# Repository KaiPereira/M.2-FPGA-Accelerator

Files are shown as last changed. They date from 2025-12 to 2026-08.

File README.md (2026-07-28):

# M.2 FPGA Hardware Accelerator Devboard

This is an M.2 2280 M-Key card I've designed that plugs into the SSD slot in your computer and provides an FPGA fabric you can interact with over PCIe. It also has a couple pins broken out and a couple connectors like micro HDMI and USB-C so you can create custom pipelines that go from peripherals, into the FPGA, directly into your computer through the high-speed PCIe. 




## Custom Features
- M.2 M-Key 2280 SSD Form Factor for PCIe programming and interfacing
- Artix 7 with 50K LUTs and 256MB RAM
- USB-to-JTAG for programming and interfacing with peripherals
- Micro HDMI and 10 pins broken out for extra functionality
- Functions as a standalone devboard or can interface with your computer
- 6 LEDs for debugging and programming
- TC2030 breakout under USB-C if you DNP USB-to-JTAG

## PCB Design

The M.2 FPGA Hardware Accelerator is an extremely high density 0.8mm, 6 layer board using the JLC06081H-2116 stackup and has a stackup of SIGNAL/GND/SIGNAL/PWR/GND/SIGNAL.

A V2 is likely going to use a custom or different stackup to reduce the trace width for the DDR3 traces so I can minimize the cross-talk further, which is an issue with the current board.









## Firmware

Firmware is unwritten because I haven't produced the boards, and it requires significant prototyping in Vivado but there is some basic skeleton software inside of the [/firmware](/firmware) folder.

## Production

I've based the board around JLCPCB production and I've included an LCSC/JLCPCB BOM inside of the [/PCB/production](/PCB/production/) folder.

It uses the JLC06081H-2116 stackup which you can find details about on the JLC site if you want to produce the board from a different fabricator.

You'll want some specific settings too like:
- Impedance controlled traces
- ENIG and select gold fingers to add hard gold onto the M.2 M-Key edge connector
- 0.8mm thick board
- X-Ray to confirm all the BGA placement

Produce this board at your own cost, it's an untested board and I haven't manufactured it myself yet, because I want to create a V2 with a different stackup, and it's an extremely constrained design so many problems can arise!  

## Credits

Thanks so much to the KiCad discord for the PCB reviews, and to everyone in Hack Club for the support and to Renran and Samliu for running [Fallout](https://fallout.hackclub.com/) which is the program that's sponsoring this project!

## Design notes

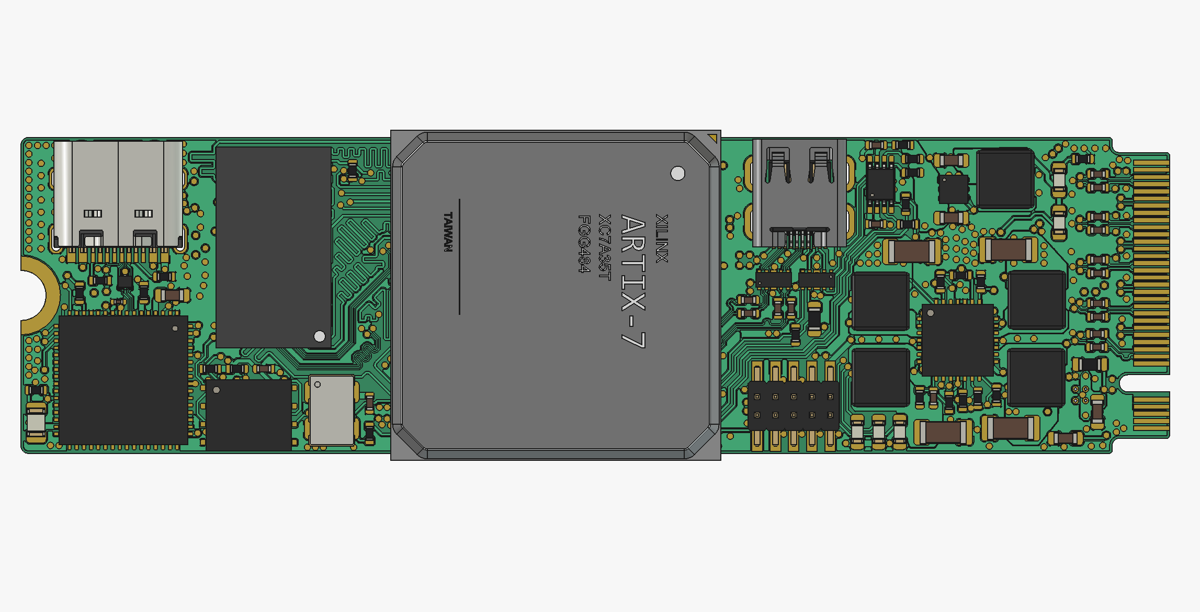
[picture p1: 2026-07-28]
PCB/renders/Top PCB Render.png

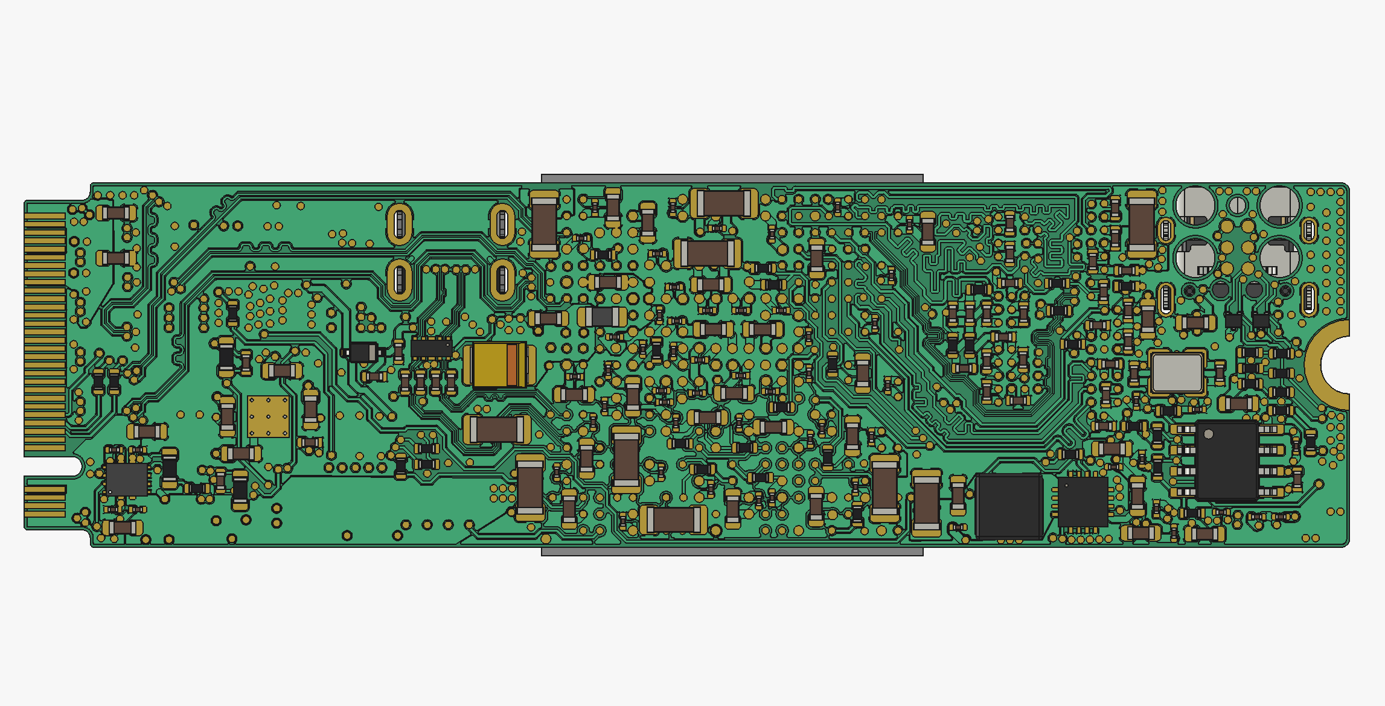
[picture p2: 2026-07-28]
PCB/renders/Bottom PCB Render.png

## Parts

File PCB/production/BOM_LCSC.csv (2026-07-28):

Designator | Footprint | Quantity | Value | LCSC Part #
C10, C11, C12, C3, C4, C5, C6, C7, C8, C9 | 402 | 10 | 220n | C16772
C100, C102, C104, C105, C106, C107, C108, C109, C112, C118, C124, C125, C127, C129, C135, C136, C137, C138, C143, C144, C145, C146, C148, C150, C151, C154, C155, C156, C157, C161, C162, C163, C164, C168, C169, C17, C170, C171, C18, C19, C20, C25, C27, C28, C29, C30, C31, C35, C36, C38, C39, C47, C54, C67, C69, C71, C91, C92, C95, C99 | 201 | 60 | 470n | C76591
C101, C103, C126, C130, C133, C134, C141, C142, C147, C15, C152, C153, C159, C160, C166, C167, C173, C2, C21, C22, C23, C32, C33, C37, C40, C41, C42, C43, C44, C56, C66, C68, C70, C75, C87, C89, C90, C94, C98 | 603 | 39 | 4u7 | C19666
C110, C111, C113, C114, C115, C116, C117, C119, C120, C122, C123, C139, C14, C16, C57, C58, C59, C60, C61, C62, C63, C64, C65, C73, C74, C76, C77, C78, C79, C80, C81, C82, C83, C84, C86, C93 | 402 | 36 | 100n | C1525
C121, C46 | 402 | 2 | 1u | C52923
C128, C72 | 603 | 2 | 47n | C1622
C13, C172 | 402 | 2 | 10n | C15195
C131, C132, C140, C149, C158, C165, C34, C45, C49, C51, C53, C85, C88 | 1206 | 13 | 47u | C96123
C24 | CP_EIA-3528-21_Kemet-B | 1 | 330u | C542287
C26 | 1206 | 1 | 100u | C15008
C48 | 402 | 1 | 68pF | C107009
C50, C96, C97 | 402 | 3 | 33p | C1562
C52 | 402 | 1 | 22pF | C1555
D1 | 603 | 1 | KT-0603R | C2296
D2 | 805 | 1 | KT-0805Y | C2296
D3 | D_SOD-323 | 1 | 1N5819WS | 1N5819WS
D4, D5, D6, D7 | 603 | 4 | KT-0603G | C2297
FB1 | 805 | 1 | 120@100MHz | C5120901
J1 | M.2 M-Key 2242 | 1 | Bus_M.2_Edge_M
J4 | USB_C_Receptacle_HRO_TYPE-C-31-M-12 | 1 | TYPE-C-31-M-12 | C165948
J5 | PinHeader_2x05_P1.27mm_Vertical_SMD | 1 | Conn_02x05_Odd_Even | C41376037
J7 | Kai's_HDMI_Micro-D_Molex_46765-1xxx | 1 | HDMI_D_1.4 | C711358
L1, L2, L3, L4, L5, L6 | L_Sunlord_SWPA4030S | 6 | 1u5 | C42100
R1, R31 | 402 | 2 | 100 | C25076
R10, R11, R12, R13, R34, R38, R39, R40, R41, R45, R46, R5, R50, R51, R53, R54, R7, R9 | 402 | 18 | 10k | C25744
R14, R15, R17, R18, R2, R24, R3, R42, R43, R56, R57, R76, R77, R78, R79, R80 | 402 | 16 | 1k | C11702
R16 | 402 | 1 | 240 | C25153
R19, R20, R21, R23, R27, R28, R30, R44, R59, R60, R61, R62, R63 | 402 | 13 | 4k7 | C25900
R25, R26, R29, R32, R36, R37, R75 | 402 | 7 | 22 | C25092
R33, R47 | 603 | 2 | 30k | C22984
R35, R6 | 603 | 2 | 4k99 | C23046
R4 | 402 | 1 | 2k | C4109
R48, R49 | 402 | 2 | 5k1 | C25905
R52 | 402 | 1 | 2k2 | C25879
R55 | 402 | 1 | 12k | C25752
R58, R65 | 402 | 2 | 100k | C25741
R8 | 603 | 1 | 8k2 | C25981
U1 | Xilinx_FGG484 | 1 | XC7A50T-FGG484 | C1521780
U10 | QFN-64-1EP_9x9mm_P0.5mm_EP4.35x4.35mm | 1 | FT2232HQ | C193662
U11 | FBGA-96_8x14mm_Layout9x16_P0.8mm | 1 | MT41J128M16JT-125:K | C426885
U12 | VSSOP-8_2.3x2mm_P0.5mm | 1 | PCA9306DC1 | C129510
U14, U15, U16 | Diodes_UDFN-10_1.0x2.5mm_P0.5mm | 3 | UCL0524P | C2835428
U17 | VQFN-16-1EP_3x3mm_P0.5mm_EP1.68x1.68mm_ThermalVias | 1 | TPS62132 | C81563
U2 | QFN-28-1EP_5x5mm_P0.5mm_EP3.25x3.25mm_ThermalVias | 1 | MAX20029ATIA/V+ | C1235515
U3, U4, U6 | Texas_DRT-3 | 3 | TPD2EUSB30 | C97502
U5 | Texas_VQFN-HR-12_2x2.5mm_P0.5mm_ThermalVias | 1 | TPS2121RUXR | C485916
U7 | W-PDFN-8-1EP_6x5mm_P1.27mm_EP3x3mm | 1 | MT25QL128ABA1EW7-0SIT | C2887898
U8 | WSON-6-1EP_2x2mm_P0.65mm_EP1x1.6mm | 1 | TPS61240DRVR | C59567
U9 | SOIC-8_3.9x4.9mm_P1.27mm | 1 | M93C56-WMN6TP | C283453
Y2 | Crystal_SMD_3225-4Pin_3.2x2.5mm | 1 | 12MHz | C9002
Y3 | Oscillator_SMD_SiT_PQFN-4Pin_5.0x3.2mm | 1 | 100MHz | C78882

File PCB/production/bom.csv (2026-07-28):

Designator | Footprint | Quantity | Value | LCSC Part #
C10, C11, C12, C3, C4, C5, C6, C7, C8, C9 | 0402 | 10 | 220n
C100, C102, C104, C105, C106, C107, C108, C109, C112, C118, C124, C125, C127, C129, C135, C136, C137, C138, C143, C144, C145, C146, C148, C150, C151, C154, C155, C156, C157, C161, C162, C163, C164, C168, C169, C17, C170, C171, C18, C19, C20, C25, C27, C28, C29, C30, C31, C35, C36, C38, C39, C47, C54, C67, C69, C71, C91, C92, C95, C99 | 0201 | 60 | 470n
C101, C103, C126, C130, C133, C134, C141, C142, C147, C15, C152, C153, C159, C160, C166, C167, C173, C2, C21, C22, C23, C32, C33, C37, C40, C41, C42, C43, C44, C56, C66, C68, C70, C75, C87, C89, C90, C94, C98 | 0603 | 39 | 4u7
C110, C111, C113, C114, C115, C116, C117, C119, C120, C122, C123, C139, C14, C16, C57, C58, C59, C60, C61, C62, C63, C64, C65, C73, C74, C76, C77, C78, C79, C80, C81, C82, C83, C84, C86, C93 | 0402 | 36 | 100n
C121, C46 | 0402 | 2 | 1u
C128, C72 | 0603 | 2 | 47n
C13, C172 | 0402 | 2 | 10n
C131, C132, C140, C149, C158, C165, C34, C45, C49, C51, C53, C85, C88 | 1206 | 13 | 47u
C24 | CP_EIA-3528-21_Kemet-B | 1 | 330u | C542287
C26 | 1206 | 1 | 100u | C15008
C48 | 0402 | 1 | 68pF
C50, C96, C97 | 0402 | 3 | 33p
C52 | 0402 | 1 | 22pF
D1 | 0603 | 1 | KT-0603R | C2296
D2 | 0805 | 1 | KT-0805Y | C2296
D3 | D_SOD-323 | 1 | 1N5819WS | 1N5819WS
D4, D5, D6, D7 | 0603 | 4 | KT-0603G | C2297
FB1 | 0805 | 1 | 120@100MHz | C5120901
J1 | M.2 M-Key 2242 | 1 | Bus_M.2_Edge_M
J4 | USB_C_Receptacle_HRO_TYPE-C-31-M-12 | 1 | TYPE-C-31-M-12 | C165948
J5 | PinHeader_2x05_P1.27mm_Vertical_SMD | 1 | Conn_02x05_Odd_Even
J7 | Kai's_HDMI_Micro-D_Molex_46765-1xxx | 1 | HDMI_D_1.4 | C711358
L1, L2, L3, L4, L5, L6 | L_Sunlord_SWPA4030S | 6 | 1u5 | C42100
R1, R31 | 0402 | 2 | 100
R10, R11, R12, R13, R34, R38, R39, R40, R41, R45, R46, R5, R50, R51, R53, R54, R7, R9 | 0402 | 18 | 10k
R14, R15, R17, R18, R2, R24, R3, R42, R43, R56, R57, R76, R77, R78, R79, R80 | 0402 | 16 | 1k
R16 | 0402 | 1 | 240
R19, R20, R21, R23, R27, R28, R30, R44, R59, R60, R61, R62, R63 | 0402 | 13 | 4k7
R25, R26, R29, R32, R36, R37, R75 | 0402 | 7 | 22
R33, R47 | 0603 | 2 | 30k
R35, R6 | 0603 | 2 | 4k99
R4 | 0402 | 1 | 2k
R48, R49 | 0402 | 2 | 5k1
R52 | 0402 | 1 | 2k2
R55 | 0402 | 1 | 12k
R58, R65 | 0402 | 2 | 100k
R8 | 0603 | 1 | 8k2
U1 | Xilinx_FGG484 | 1 | XC7A50T-FGG484
U10 | QFN-64-1EP_9x9mm_P0.5mm_EP4.35x4.35mm | 1 | FT2232HQ
U11 | FBGA-96_8x14mm_Layout9x16_P0.8mm | 1 | MT41J128M16JT-125:K | C426885
U12 | VSSOP-8_2.3x2mm_P0.5mm | 1 | PCA9306DC1 | C129510
U14, U15, U16 | Diodes_UDFN-10_1.0x2.5mm_P0.5mm | 3 | UCL0524P | C2835428
U17 | VQFN-16-1EP_3x3mm_P0.5mm_EP1.68x1.68mm_ThermalVias | 1 | TPS62132
U2 | QFN-28-1EP_5x5mm_P0.5mm_EP3.25x3.25mm_ThermalVias | 1 | MAX20029ATIA/V+ | C1235515
U3, U4, U6 | Texas_DRT-3 | 3 | TPD2EUSB30
U5 | Texas_VQFN-HR-12_2x2.5mm_P0.5mm_ThermalVias | 1 | TPS2121RUXR | C485916
U7 | W-PDFN-8-1EP_6x5mm_P1.27mm_EP3x3mm | 1 | MT25QL128ABA1EW7-0SIT | C2887898
U8 | WSON-6-1EP_2x2mm_P0.65mm_EP1x1.6mm | 1 | TPS61240DRVR
U9 | SOIC-8_3.9x4.9mm_P1.27mm | 1 | M93C56-WMN6TP
Y2 | Crystal_SMD_3225-4Pin_3.2x2.5mm | 1 | 12MHz | C9002
Y3 | Oscillator_SMD_SiT_PQFN-4Pin_5.0x3.2mm | 1 | 100MHz | C78882

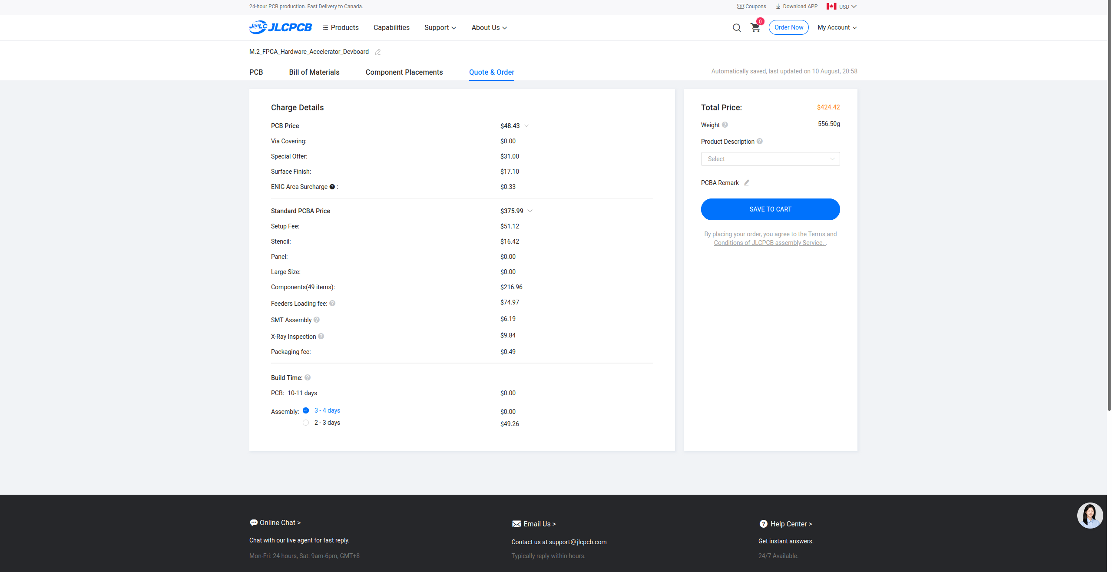
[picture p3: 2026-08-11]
PCB/production/JLCPCB BOM Cost.png

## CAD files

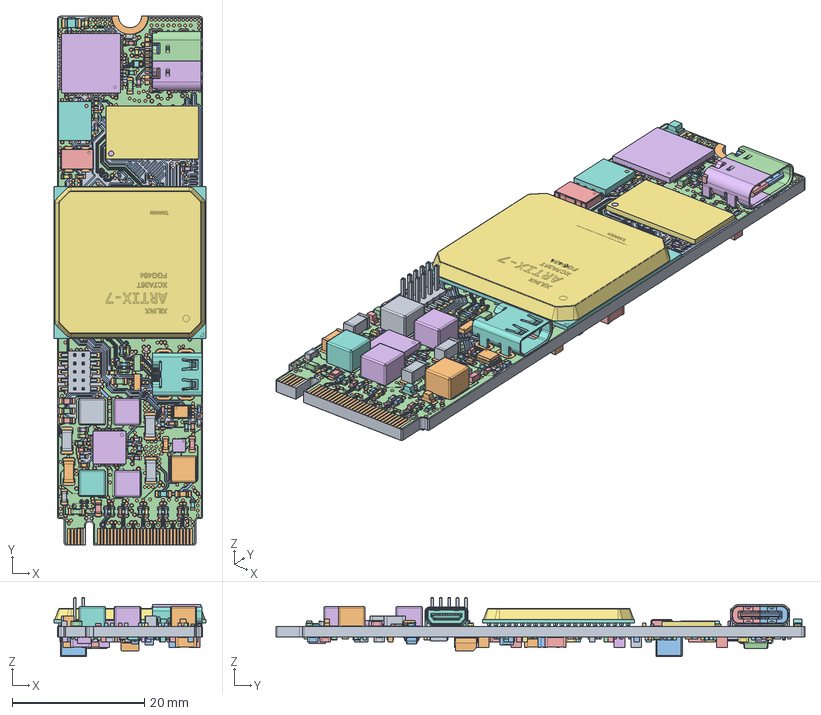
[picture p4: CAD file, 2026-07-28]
PCB/PCB.FCStd
23.0 x 80.0 x 9.00 mm
Pcb_6ed7
topPads_6ed7_cut
topTracks_6ed7
topZones_6ed7
botPads_6ed7_cut
botTracks_6ed7
botZones_6ed7
U3_DRT_3_db824c9c6ecc
C72_C_0603_1608Metric_5e36e871a214
U12_VSSOP-8_2.3x2mm_P0.5mm_27119c29455c
C105_C_0201_0603Metric_810f01f4b739
C70_C_0603_1608Metric_285581eceda0
C9_C_0402_1005Metric_7bbb193fbc59
R28_R_0402_1005Metric_2ceafa7c5941
A0A1D60D-8EA2-4440-A76C-889AD579F6B7
A0A1D60D-8EA2-4440-A76C-889AD579F6B001
J5_PinHeader_2x05_P127mm_Vertical_SMD_d3717308b6a3
R62_R_0402_1005Metric_ff690207b4ec
C5_C_0402_1005Metric_4392c6b985be
U15_Diodes_UDFN-10_1.0x2.5mm_P0.5mm_482b8b0d3ad6
R33_R_0603_1608Metric_e8235a0dd6c8
U8_WSON_6_1EP_2x2mm_P065mm_EP1x16mm_4512e4520f19
C119_C_0402_1005Metric_a6c59a1147ee
b2c8199a-8124-11ed-a8f2-acde48001122_part
b2c81abc-8124-11ed-a8f2-acde48001122_part
b2c81abc-8124-11ed-a8f2-acde48001122_part001
b2c81abc-8124-11ed-a8f2-acde48001122_part002
b2c81abc-8124-11ed-a8f2-acde48001122_part003
b2c81abc-8124-11ed-a8f2-acde48001122_part004
b2c81abc-8124-11ed-a8f2-acde48001122_part005
b2c81abc-8124-11ed-a8f2-acde48001122_part006
b2c81abc-8124-11ed-a8f2-acde48001122_part007
b2c81abc-8124-11ed-a8f2-acde48001122_part008
b2c81b5c-8124-11ed-a8f2-acde48001122_part
R11_R_0402_1005Metric_b85a15342edb
D6_LED_0603_1608Metric_46c866f26d77
Y3_Oscillator_SMD_EuroQuartz_XO53-4Pin_5.0x3.2mm_67b5db197837
R48_R_0402_1005Metric_d4512e19648c
C48_C_0402_1005Metric_6bb54f56762e
D2_LED_0805_2012Metric_66023c916e94
C7_C_0402_1005Metric_07508b53c483
a684622a-8551-11ed-a139-00155d22e2d7_part
a68462b6-8551-11ed-a139-00155d22e2d7_part
a68462b6-8551-11ed-a139-00155d22e2d7_part001
R60_R_0402_1005Metric_9ab4710071f4
C111_C_0402_1005Metric_9e80eb63b43e
R49_R_0402_1005Metric_c1691efec041
R55_R_0402_1005Metric_50459dd57344
a684622a-8551-11ed-a139-00155d22e2d7_part001
a68462b6-8551-11ed-a139-00155d22e2d7_part003
a68462b6-8551-11ed-a139-00155d22e2d7_part004
C10_C_0402_1005Metric_e4306dec6820
D7_LED_0603_1608Metric_ffa68f399684
U2_QFN-28-1EP_5x5mm_Pitch0.5mm_19db0ce88066
R75_R_0402_1005Metric_a483df6bea4b
R77_R_0402_1005Metric_3be320d7ddfe
C4_C_0402_1005Metric_65057fa5bc6c
C139_C_0402_1005Metric_fde9821d451f
C122_C_0402_1005Metric_816c50b5e529
R47_R_0603_1608Metric_03dc8c990f57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

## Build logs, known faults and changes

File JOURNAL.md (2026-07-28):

---
title: FPGA Accelerator
author: Kai Pereira
description: " A low-cost, PCIe FPGA accelerator M.2 M-Key form factor devboard for hobbyists"
created_at: 2025-12-16
---
## The idea - 2 Hours

I've worked on a ton of different boards ranging from keyboards, to motherboards to hackathon badges to even carriers, but now I want to work on something next level.

I've always been fascinated by hybrid computing in a consumer setting and building complicated stuff, so with that in mind, I've come up with my next idea.

FPGA's are becoming much more mainstream for parallelization and computing so I want to explore how hobbyists can leverage this technology in an affordable and cool way.

The thing about FPGA's, is while they're really useful, it's hard to make practical applications of them as a hobbyist, because it's not like you're going to innovate the next big chip or something, but that's where I want to leverage the fact that FPGA's aren't just useful for mainstream chips, but also more niche applications like very specific hardware acceleration, that consumers can actually make cool use of and practice.

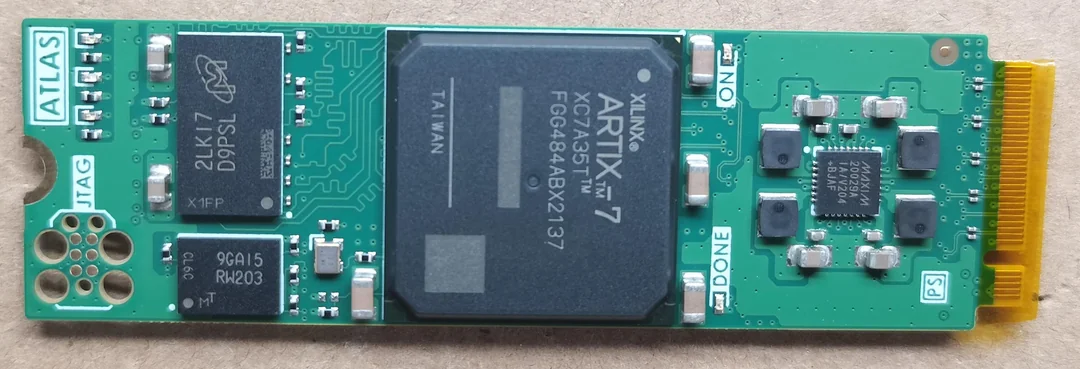
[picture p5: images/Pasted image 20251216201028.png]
Pasted image 20251216201028.png


So the idea is simple, I want a low-cost way, hobbyists can make practical applications of FPGA's in a bunch of different settings.

To do this, I want to provide an FPGA devboard of sorts, that can interface with your computer hardware so you can practice on real-world applications in more niche settings. But I want to go a step further and also make it function as a standard devboard in case you don't have access to an M.2 slot, so I need to break out like standard USB-C and whatnot.

This also means that I want to add other functions like HDMI, maybe even GbE and just generally make it insanely useful to hobbyists!

There's a couple key goals I have for this project:
- Learn to route BGA and high-density impedance controlled traces
- Learn GbE, HDMI and PCIe routing
- Understand at a high level, the physics behind the board
- Focus on routing best practices, specifically minimizing loops

This project has already been similarly done by Phil's lab, but his project was more-so focused on acceleration instead of as a hobbyist development board, but this video will still be really useful to reference during development of this project! https://www.youtube.com/watch?v=8bw80LiCl7g

## Connectors!! - 4 Hours

Now the first thing I have to decided, is what type of edge connector I want to use. Now NVMe SSD's are standard M.2 size, but have different type of "keys" which is essentially where the different holes are on it:

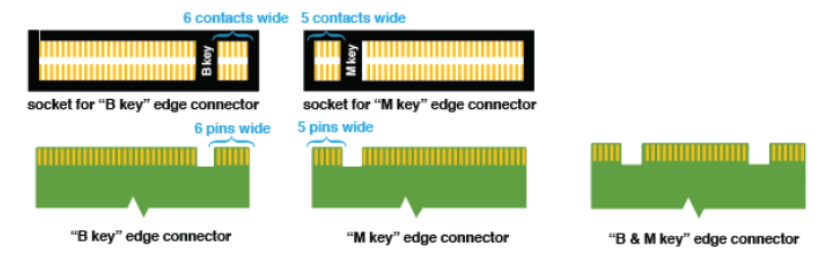
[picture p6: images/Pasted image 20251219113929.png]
Pasted image 20251219113929.png


NVMe SSD's mostly just use M-Key edge connectors, so that's what I'm going to use.

But now, there's also more than just one type of size, there's actually 5 of them (probably more than that, but the 5 most common)

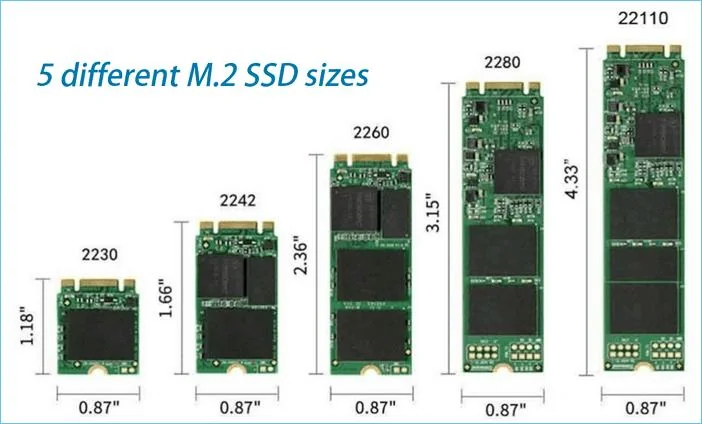
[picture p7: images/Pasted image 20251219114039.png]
Pasted image 20251219114039.png


Now 2280 is by far the most common, but I don't actually think I'll use all that space, so for now, I think I'm going to go with 2242 which is decently common still but for other applications most of the time.

The numbering system is really simple. 2242 means 22mm x 42mm, 2280 means 22mm x 80mm.

So now i have to create my footprint and symbol for these edge connectors. I can also easily change my form factor after making the footprint because it's legitimately just the height that changes.

Lucky for me, someone's already made some M.2 footprints and symbols, so I'm going to use these ones from https://github.com/timonsku/M.2-Card-Footprints

Now this person didn't actually make an M-Key, so I had to modify one of the existing ones to make it. M.2 footprints are really interesting, because they literally just remove the pins where the key is and don't really shift anything, so it's easy to make footprints for:

Pasted image 20251219114720.png

Now I was thinking I might be able to use a B+M-Key to be more compatible, but the ECP5 only has a soft SATA PHY or SERDES which would be really complicated and annoying to implement, so I'm just keeping it symbol.

And then this library I downloaded included the symbols already, so I'm all set to get working:

Pasted image 20251219115014.png

## Edge connector and choosing an FPGA - 4 Hours

Now I want to get working on actually wiring the edge connector! The first thing I'm going to do is wire the power and ground.

I decided to use one 100nF cap per pin, and then one 1uF + 10uF per group of them like so:

Pasted image 20251219121205.png

I'm referencing the M.2 PCI express electromechanical datasheet for pins https://picture.iczhiku.com/resource/eetop/sHksKPigIJigRbbx.pdf

Pasted image 20251219121236.png

I've decided to 0402 for 100nF, and 1uF, and then 0603 for 10uF to save as much space as possible, but still be pretty efficient at decoupling.

Next, I need to choose what FPGA I actually want to use. The first thing that comes to mind is the ECP5. It's a small and cheap FPGA with SERDES so it works with PCIe which is really cool. 

It has a faster (5G) and slower version, so I can have gen 2 PCIe speeds which is pretty cool. The minimum 5G FPGA costs around $18.50 https://jlcpcb.com/partdetail/Lattice-LFE5UM5G_25F8MG285C/C1551932 so it's a pretty good option.

But there's also the Xilinx Artix FPGA which is significantly more powerful, the XC7A100T has nearly 4x the LUTS and is way more powerful, but is also significantly larger, having 4x lanes. The price is actually pretty good though, coming in at just $29.

So the Artix FPGA is probably a better option, because the price and accessibility of the ECP5 for the specs I need is just kind of out of scope. It'll also give me really good practice with a really popular AMD FPGA which could be really helpful for the future! 

Now the Xilinx Aritix has MANY different packages, ranging from 12K to 215K LUTs and 720 to 13000 Kb of memory. I also need a minimum of 4 GTP transceivers which are essentially just high speed pins so 15K LUTs minimum.

But let's stay within the price range, so I want under $20 for the FPGA and preferably over 25K LUTs which gives me many good options!

This means I should also increase the size of my board from 2242 to 2280 which I actually wanted an excuse to do, and I can also add all those other features. 

So in the end, I think I'm going to go with the XC7A50T-1FGG484C, the Xilinx Artix 7, with 50K LUTs, coming in at just $17 at minimum quantities, and having 484 pins!!! https://jlcpcb.com/partdetail/AMDXILINX-XC7A50T1FGG484C/C1521780

I think this is honestly the perfect option, and I know Phil's Lab uses the same one, but it's the best for the job!

## Working on the FPGA - 3 Hours

Now that I know I want to use the Artix 7 FPGA, I need to add it into KiCad. I'm really lucky because KiCad actually has this symbol built in, but the footprint doesn't seem to come up, so I'll need to look into that:

Pasted image 20251220104108.png

Pasted image 20251220104157.png

And lucky me, a footprint actually does exist!!

Pasted image 20251220104406.png

Next, I want to figure out what voltage lines I need for my project. Based off of the datasheet, I'll need:
- VCCINT 1V, FPGA fabric logic, lowest voltage for CMOS is 1V
- VCCBRAM 1V. internal block RAM, needs to be really stable
- VMGTAVCC 1V, analog GTP transceivers voltage, might need to be seperate from VCCINT
- VCCAUX 1V8, powers configuration and clocking stuff, 1V8 for noise margin
- VCCO 3V3, powers I/O banks 3V3 because connector is 3V3 and I use 3V3 logic
- VMGTAVTT 1V2, very interesting termination voltage, it basically controls the impedance of the GTP transceiver/PCIe lines, and makes sure they don't see reflections and too much nosie!
- DDR3 Voltage, 1V5 for DDR3 I/O bank pins which are 1V5 for standard DDR3 (1V35 for DDR3L)

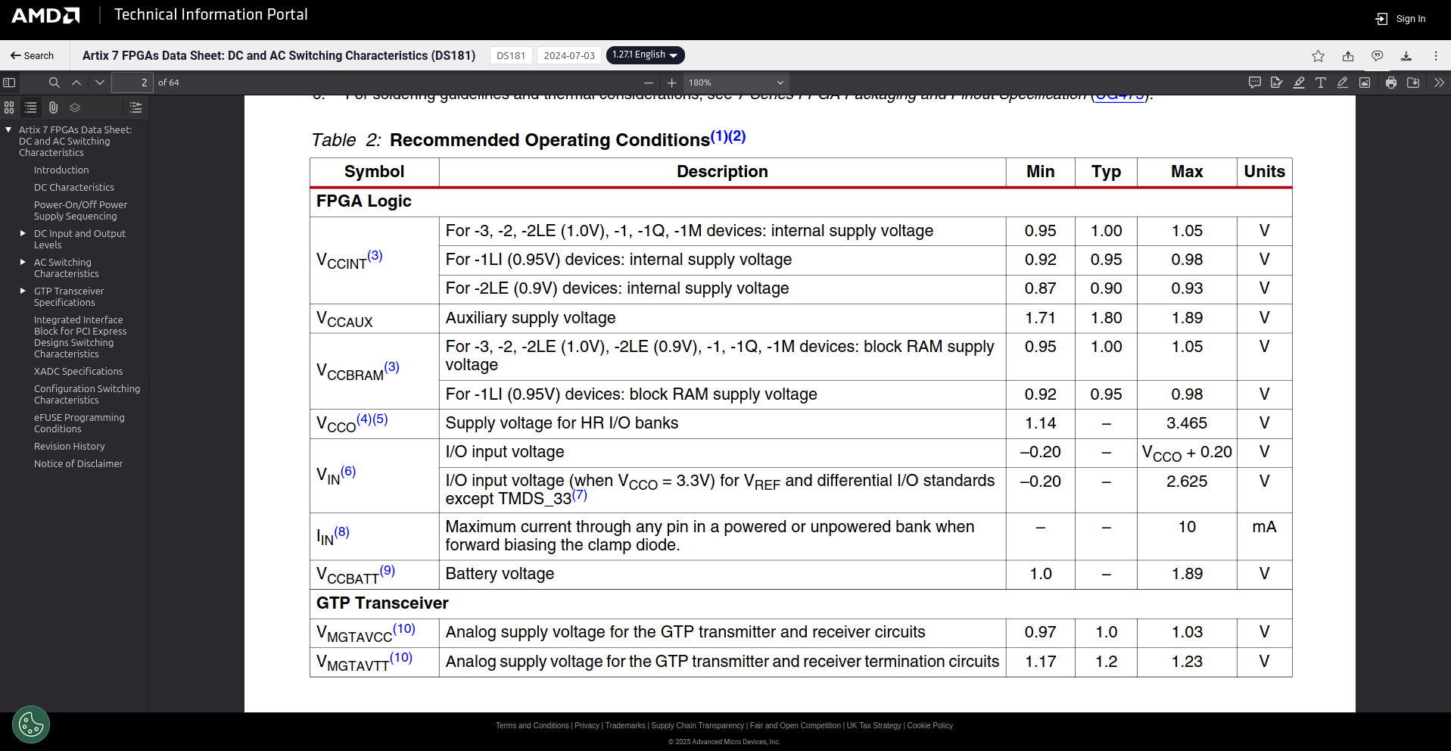
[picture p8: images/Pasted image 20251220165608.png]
Pasted image 20251220165608.png


So now that I have all the theory worked out, I can get working on making the actual thing! 

This was just a bunch of datasheet reading today and a couple video's, but I have a really good idea on how to do this now!

## Decoupling time! - 5 Hours

Decoupling is fairly simple with the Artix 7, the datasheets tell you almost exactly how to do it:

Pasted image 20251221082541.png
Pasted image 20251221082558.png

So just like that, I organized everything and added in the decoupling: 

Pasted image 20251221082621.png

And I'll also need ferrite beads on these lines, but before that, I want to figure out what PMIC I'm going to use. I have 4 rails, and I need 3V3, so a quad switching buck converter would be a really good option! 

I want to do this, because the characteristics of the bucks will help me determine the values of the ferrite beads!

I spent nearly 6 hours straight, fueled from Yerba and classical music trying to find the best buck, and I've found 2 possible options.

The [MAX20029](https://www.analog.com/en/products/max20029.html) is the lower cost option, with up to 1.5A channels, and is fixed/adjustable, though I would only use the fixed part. It's high efficiency, but the efficiency kind of drops off at lower current, but it has a smaller package and is designed for automotive. You can use the same value inductor on all the rails and it has power sequencing. This is the same one that Phil's lab uses, and it's really good!

The [LTC3370](https://www.digikey.ca/en/products/detail/analog-devices-inc/LTC3370IUH-TRPBF/5155587) is a bit more overkill, with strong 2A channels, and really good efficiency characteristics. It's a bit larger and a bit more expensive, and it's a bit overkill, but you can have the same value inductors, and is also a fantastic option! 

I've legitimately looked at 100's of buck converters, and these are probably the 2 best options! 

In the end, I think I'm going to go with the MAX20029 because it has smaller inductors, is cheaper and perfectly fits the specs. Even though it's what phil uses, it honestly just is the superior option and the only downfall is I can't use any of the fixed variants, so I have to use quite a few voltage dividers. 

I've done a lot of research today, so I think I'm going to hop off for now! 

## Power management! - 8 Hours

Now that I've found what PMIC I want to use, we need to add it into KiCad.

But after some second thought, I've decided that the LTC3370 is actually probably a better choice because of it's higher current demands which means better power tolerance, and I want support for all the extra peripherals I might add too. 

So let's add that in! 

The first thing I need to do is create the symbol for my buck converter. After referencing the datatsheet and tuning things up, I've come up with this pretty clean symbol that will probably change to my likings, but it's good as a template, and has all the necessary pins and footprint! 

Pasted image 20251225000450.png

Pasted image 20251225000521.png

Next, I'm going to wire all the important stuff for the buck converter. Per the datasheet, each input should have a 22uF cap, VCC should have 10uF, and each 2A channel output should have 47uF! 

I calculated the voltage dividers using VOUT = VFB(1 + R2/R1), and used 100K as my bottom resistor to minimize my BOM. This gives me a really nice and convenient voltage divider setup:

I also used 2.2uH inductors which are recommended by the datasheet for 2A, and they have a really low ESR to minimize power loss:

Pasted image 20251225000820.png

BUTTTT, this is kind of when I had a brain blast and decided to just outright switch to the MAX20029.

I realized that I would be saving over $7 with the MAX20029 and it has way simpler power sequencing and smaller package, so it's just significantly better.

So let's make the symbol for the MAX20029! I came up with this tall little symbol, I might make it larger but it kind of fits my needs:

Pasted image 20251227142741.png

And then it's really simple wiring, you just need pullups on PG to have a stable state, and also calculate the voltage dividers and frequency matching capacitors:

Pasted image 20251227142844.png

PG1 will go high when it's active, and the pullup just helps to ensure it gets there. There's no voltage divider on 1V0, because the VOUT is already 1V, and then the rest have voltage dividers to get there and frequency matching rounded down to the nearest E6 capacitor!

## More decoupling and filtering - 5 Hours

Now that I've finished with my power supply, I need to figure out how to properly filter it for my analog rails! 

This actually took me a really long time to figure out because I've never fully understood ferrite beads, but after a bit of research and talking with the KiCad guys, I've done a simple but effective implementation in my opinion:

Pasted image 20251229001159.png

I chose 600R@100MHz to filter out the high frequency noise moderately and it's low DCR so it has a minimal drop and is up to 2A. I made a little low pass filter LC filter by adding some shunts to ground, and added a bulk before the cap on MGTAVCC because it's higher current!

I decided to also set up an LTSpice simulation for these ferrite beads, just to make sure everything will be fine, and I can use it in the future for more accurate testing and adjusting once I've finished routing the board!

This took me a really long time to figure out, but I think it turned out really well! 

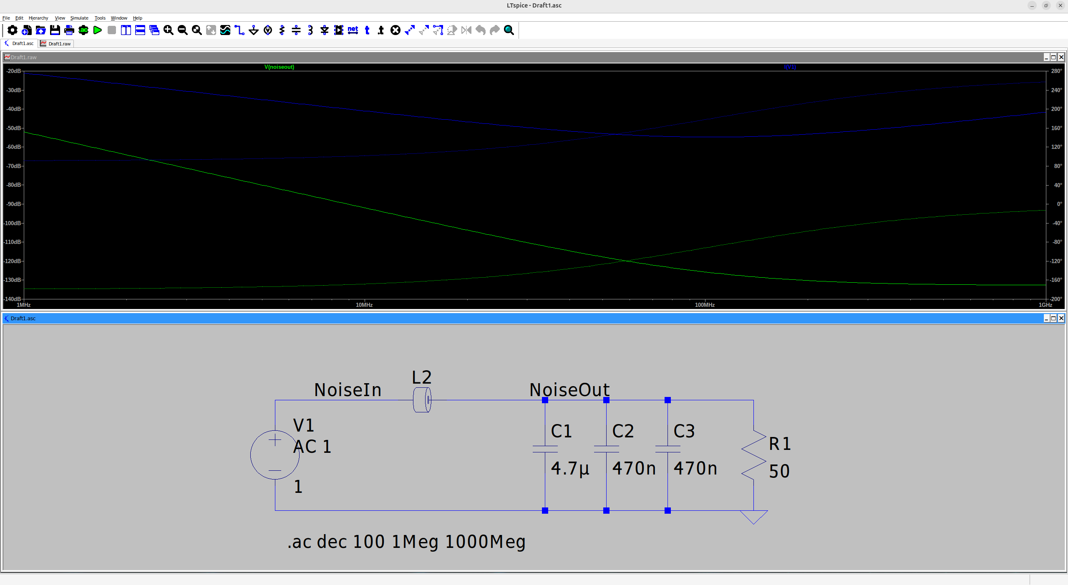
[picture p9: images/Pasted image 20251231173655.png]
Pasted image 20251231173655.png


This isn't too relevant right now, but will be really useful once I've finished routing! 

I also fixed up some of the decoupling on my m.2 edge connector because it wasn't using the standard values in my schematic.

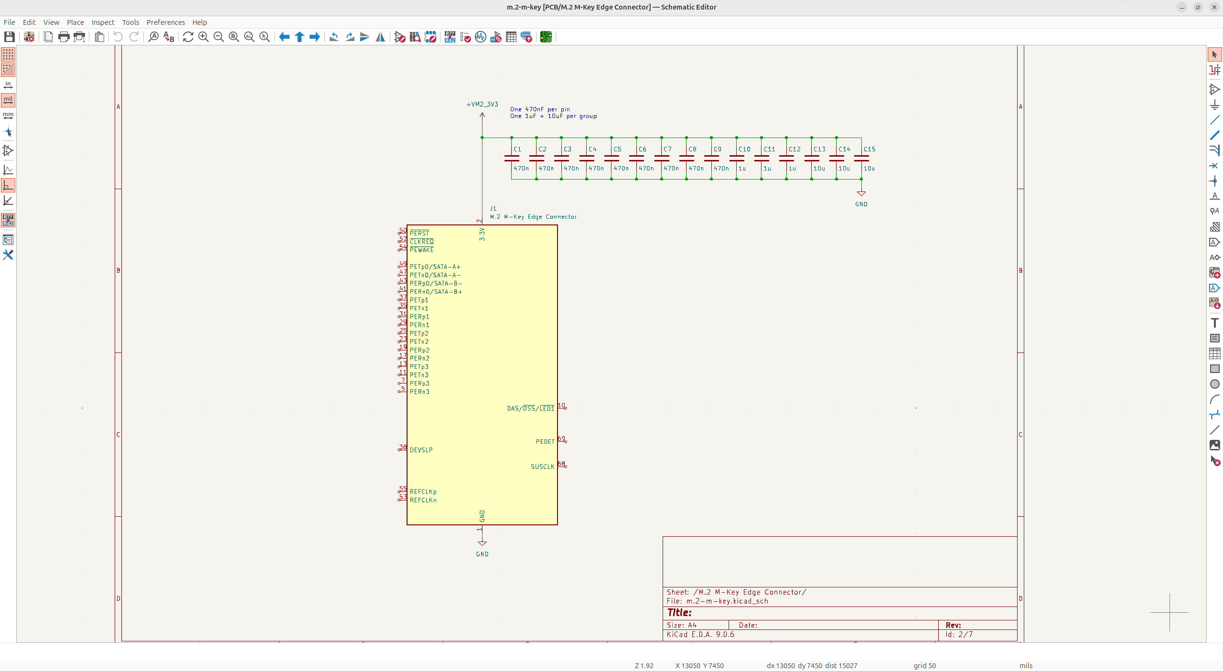
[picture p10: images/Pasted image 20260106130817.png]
Pasted image 20260106130817.png

It actually took me so long to figure out LTSpice, but that was essentially how my day went! 

## Configurations and JTAG, oh no - 15 hours

So now I have the majority of my fundamental power system in place, but I actually need a way to program this thing. The first thing I have to do is configure the artix 7 to work over master SPI. I referenced the datasheet for this part and it pretty much tells you what to do:

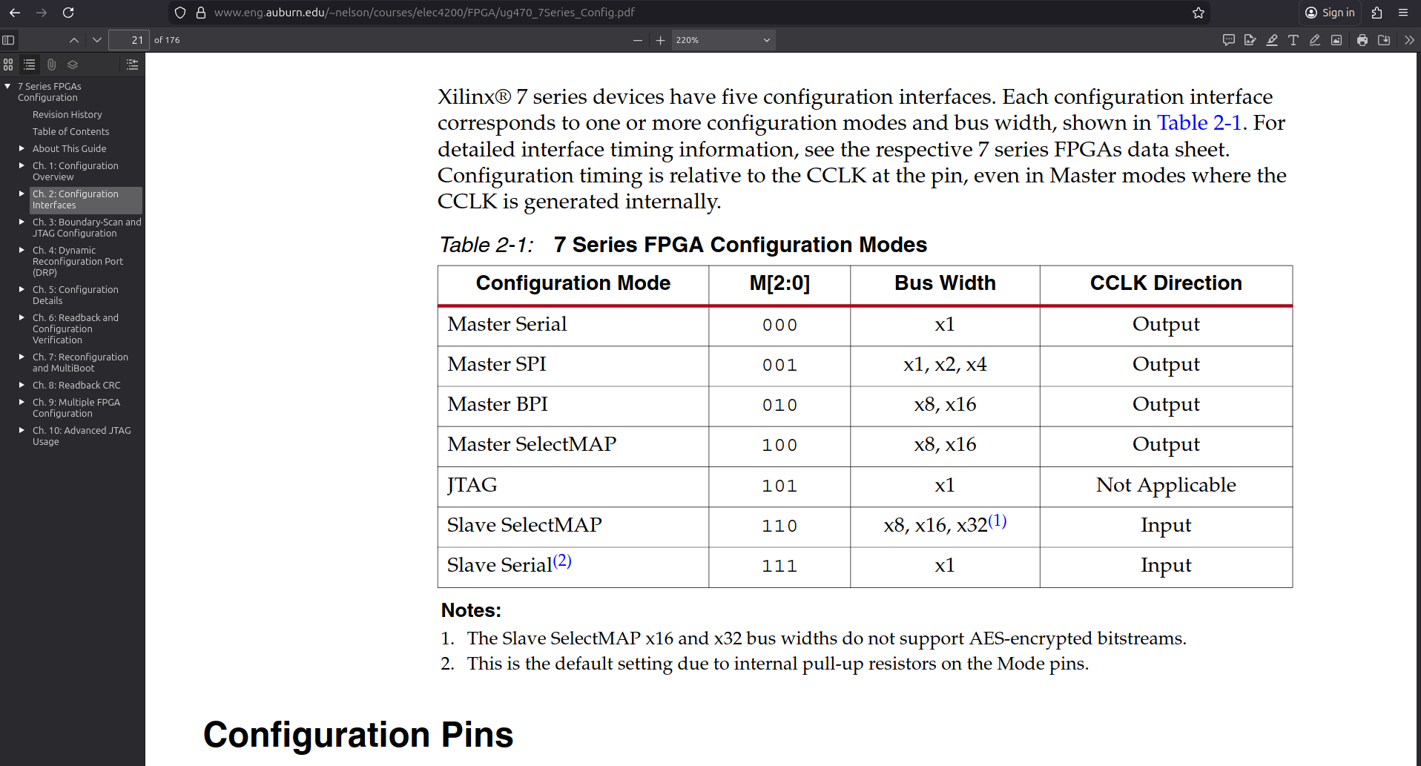
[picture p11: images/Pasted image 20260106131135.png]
Pasted image 20260106131135.png


A 0 means tie it low, and a 1 means tie it high. I also added this DNP resistor in case you want to use the artix 7 built in flash for debugging, so it's just kind of handy:

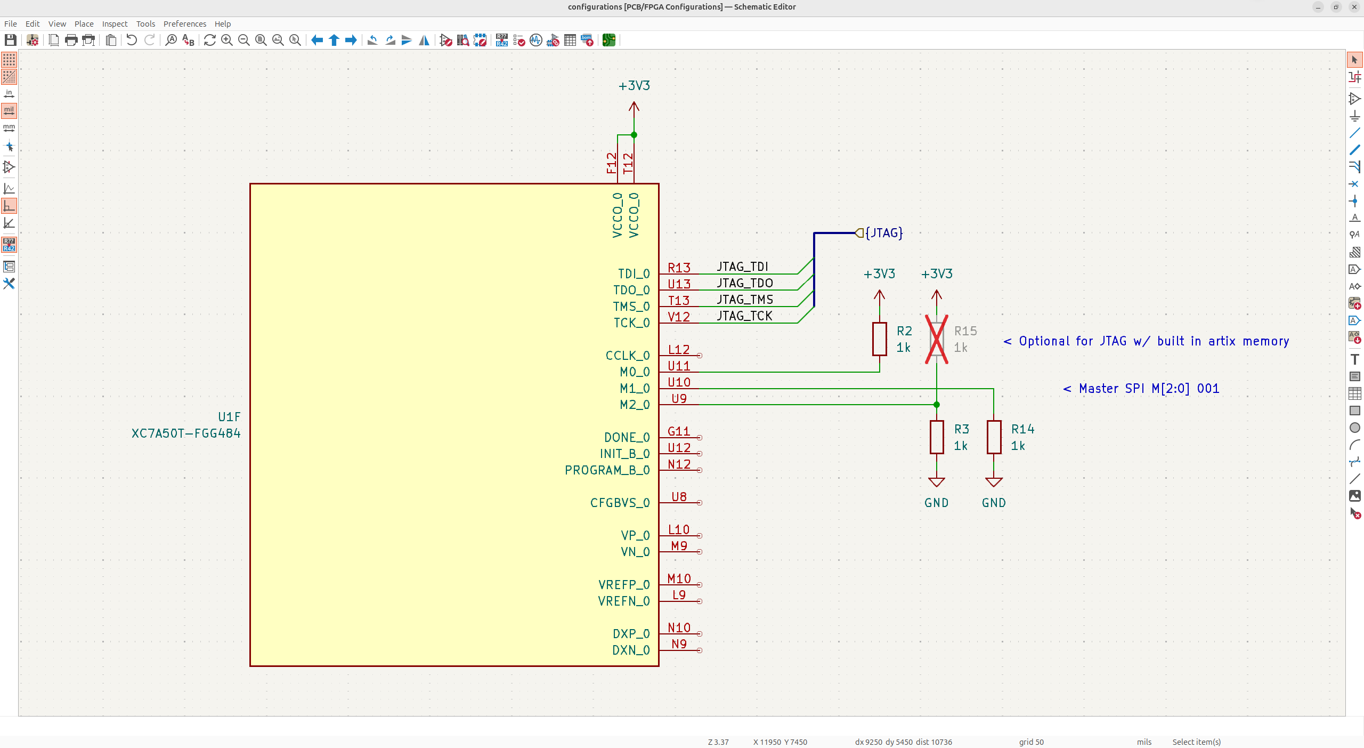
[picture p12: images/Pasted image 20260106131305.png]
Pasted image 20260106131305.png


I also learned how buses work, and created a JTAG bus which connects to a hierarchial label which will connect to my USB to JTAG/TC2030.

The next thing I need to figure out is my JTAG. This is how the board will be programmed, the JTAG interface will feed into the artix 7, and the artix 7 will feed it into SPI.

Now the first thing I want to do is add on a TC2030 interface which is a compact way of programming JTAG using this little debugger:

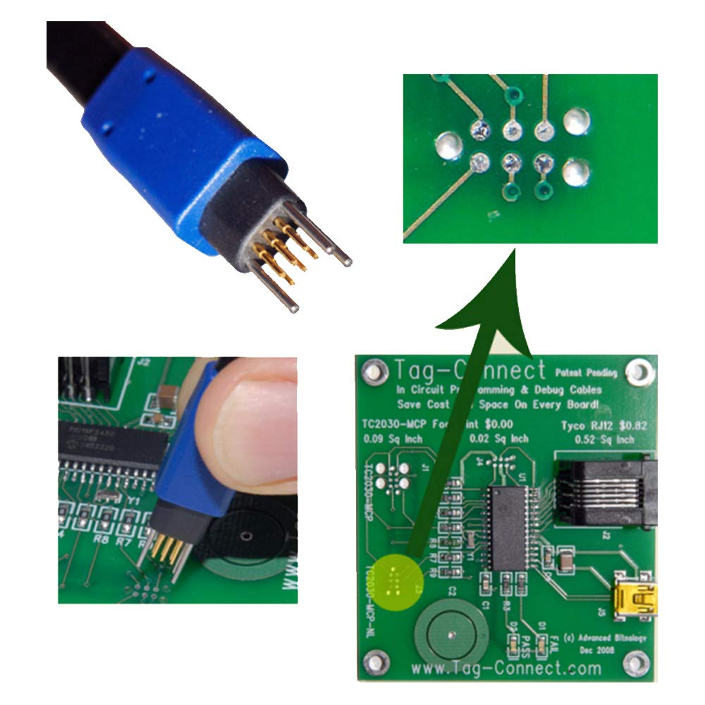
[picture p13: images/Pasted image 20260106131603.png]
Pasted image 20260106131603.png


I also wanted to have USB to JTAG because it's way easier and actually cheaper to debug with it because you don't need an external probe. Now I probably spent over 10 hours thinking about how I should do my USB to JTAG, I put so much thought into this.

But at the end of the day, Vivado, the tool I'm probably going to use to program my board, and all the other tools only really support FT2232H, and because I'm probably going to be debugging a bunch, I didn't want to bitbang, so I decided to go with the large and expensive IC for programming!

The thing is, I don't have to place the FT2232H in my production runs, only in my prototypes runs so it's perfectly fine to have for prototyping, it'll just cost more for those boards though....

I also wanted to have USB to power and program the board, so I came up with this monstrosity of a schematic:

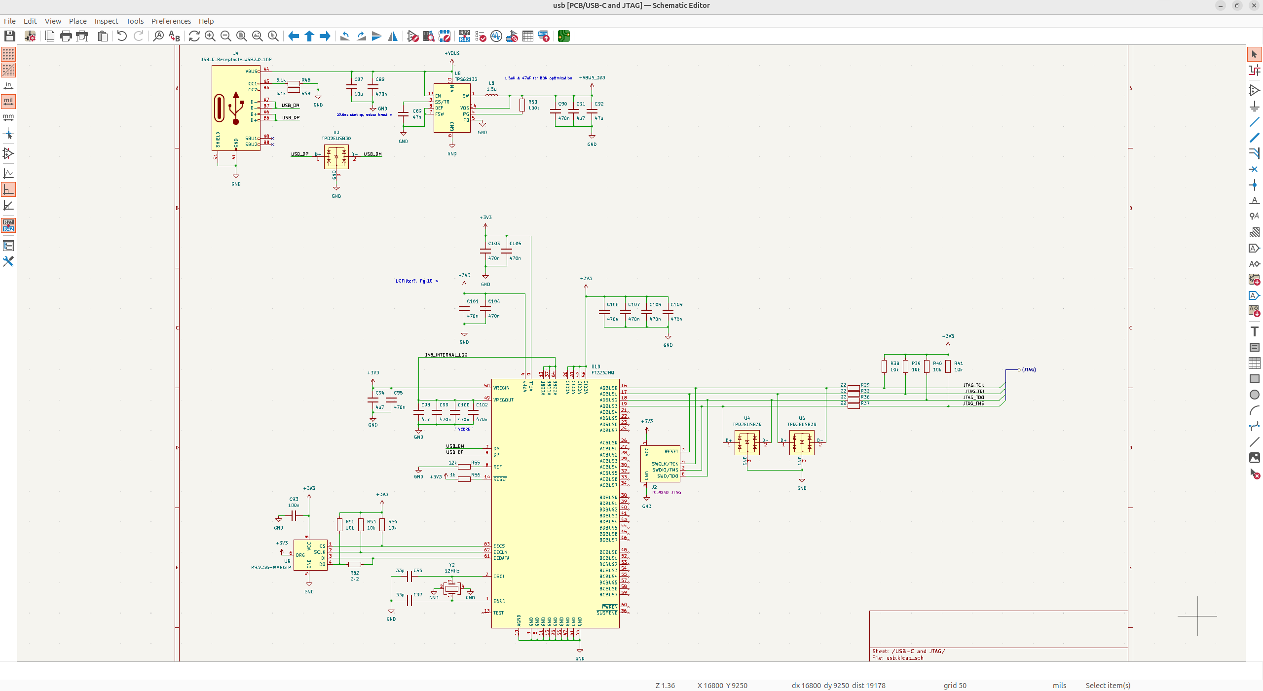
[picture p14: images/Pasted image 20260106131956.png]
Pasted image 20260106131956.png


USB-C comes in, get's bucked down and has some ESD protection. The data lines go into the FT2232H USB to JTAG, and then JTAG get's pulled up so nothing's floating, and goes into my bus for use in the configurations schematic. The TC2030 will go underneath the USB-C receptacle and if you DNP the USB to JTAG logic, it'll still be programmable via the probe. Pretty cool huh :D

I did some really good work for these couple days, but I'm still missing some fundamental logic for this circuit that's really important, but we'll see this in the next section!

## Power architecture - 6 Hours

Now there's a bit of a problem that arises with having both USB-C and an m.2 edge connector supplying our board. What if the current just flows right onto the motherboard, completely frying and destroying it.

This is why we need to implement a power mux on our board! I usually try to shy away from power mux's because there's usually a smarter way of solving power issues, but in this case, it was pretty much necessary, and the slight added cost is important so that our board functions smoothly.

I found this nearly perfect IC, which let's met control the ramp up of the inrush, the max current, switchover and so much more, all in a small package! This is THE TPS2121RUXR.

This beauty took me a whole to wrap my head around, but it does everything for me:

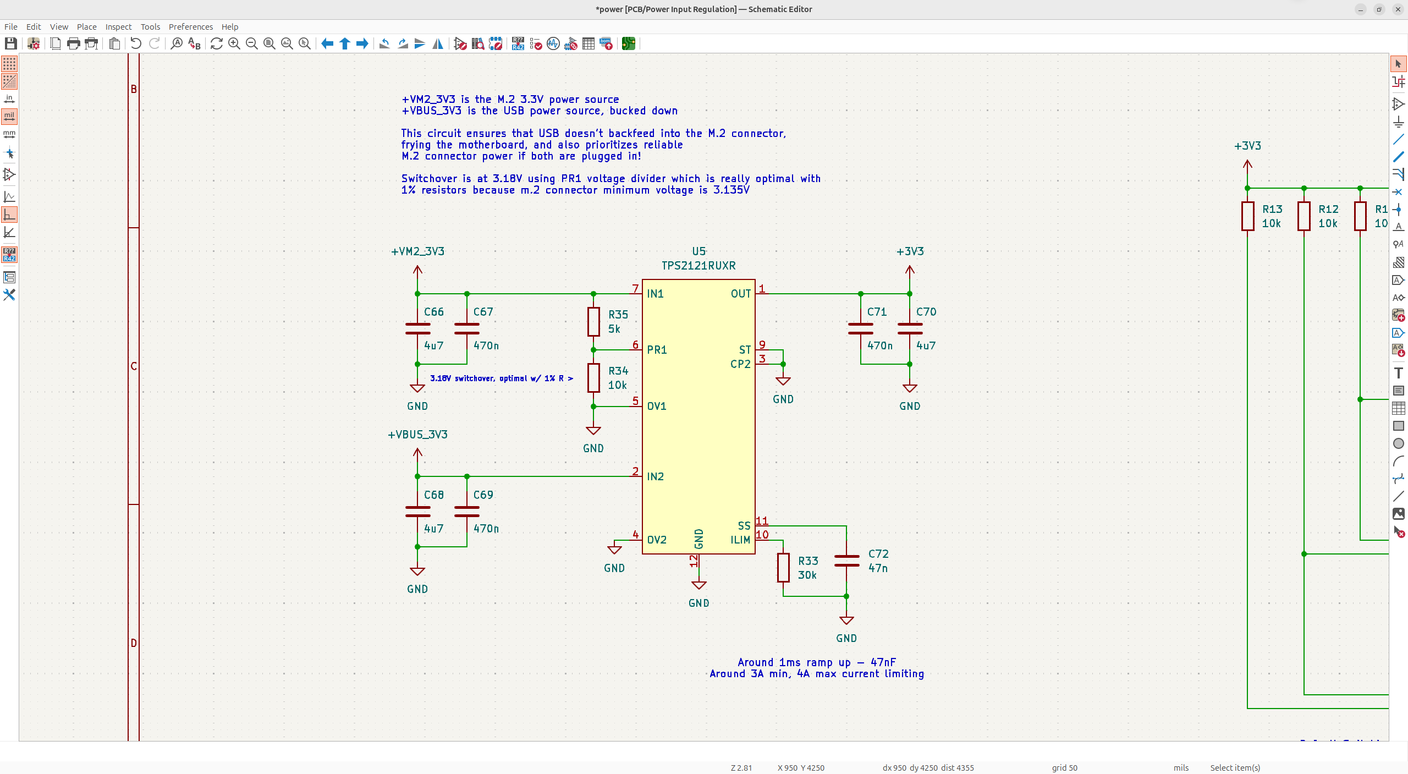
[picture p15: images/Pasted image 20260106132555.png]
Pasted image 20260106132555.png


I prioritized the M.2 connector source because the motherboard is always going to supply smooth power because you need to be able to have a reliable computer right!

And then of course I added some smooth decoupling, and we got that finished after some time! 

I'm going to end off this section here, because now we're going to get into some really technical territory, figuring out the pinouts for my flash, ram, etc. It's going to be a wild ride! 

## Flash storage and configurations - 4 Hours

Now that I've finished with the power architecture of my board, I need to implement all the configurations for my board and also add the flash storage.

The flash storage is fairly simple, there's some fixed pins on the artix 7 for it, so I can just wire it to those with some pullups according to the artix datasheet. I then added some decoupling:

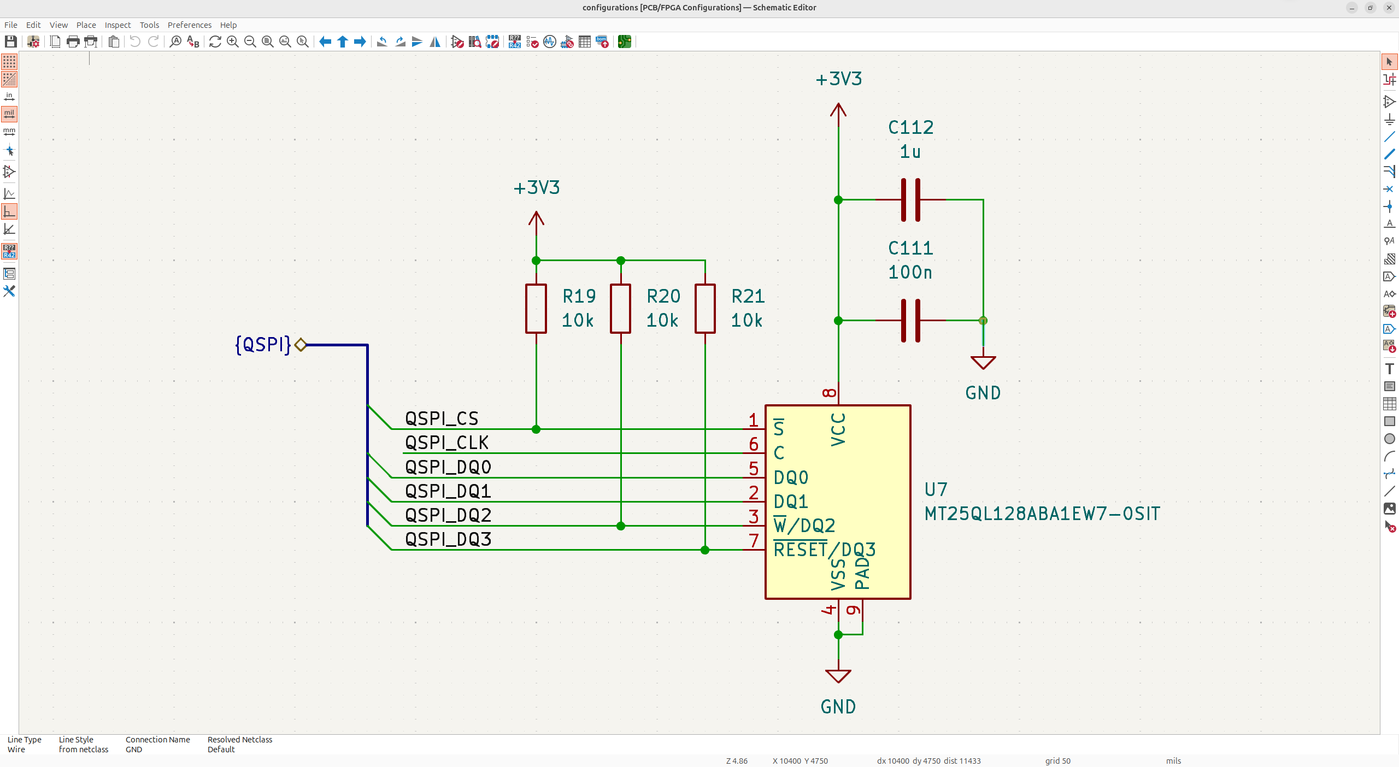
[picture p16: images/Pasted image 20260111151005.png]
Pasted image 20260111151005.png
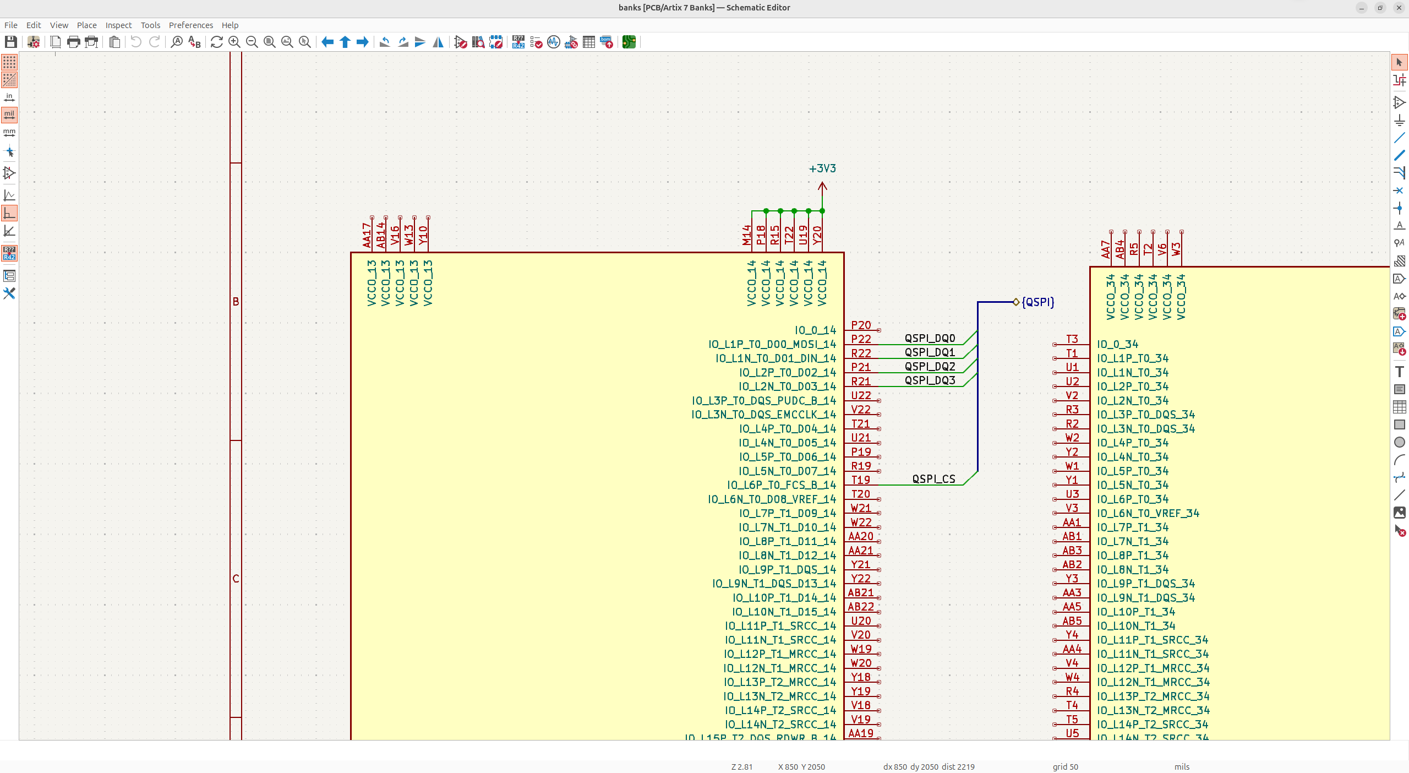
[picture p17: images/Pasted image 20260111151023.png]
Pasted image 20260111151023.png


Next, I added a basic configuration to the board to make it work according to UG470:

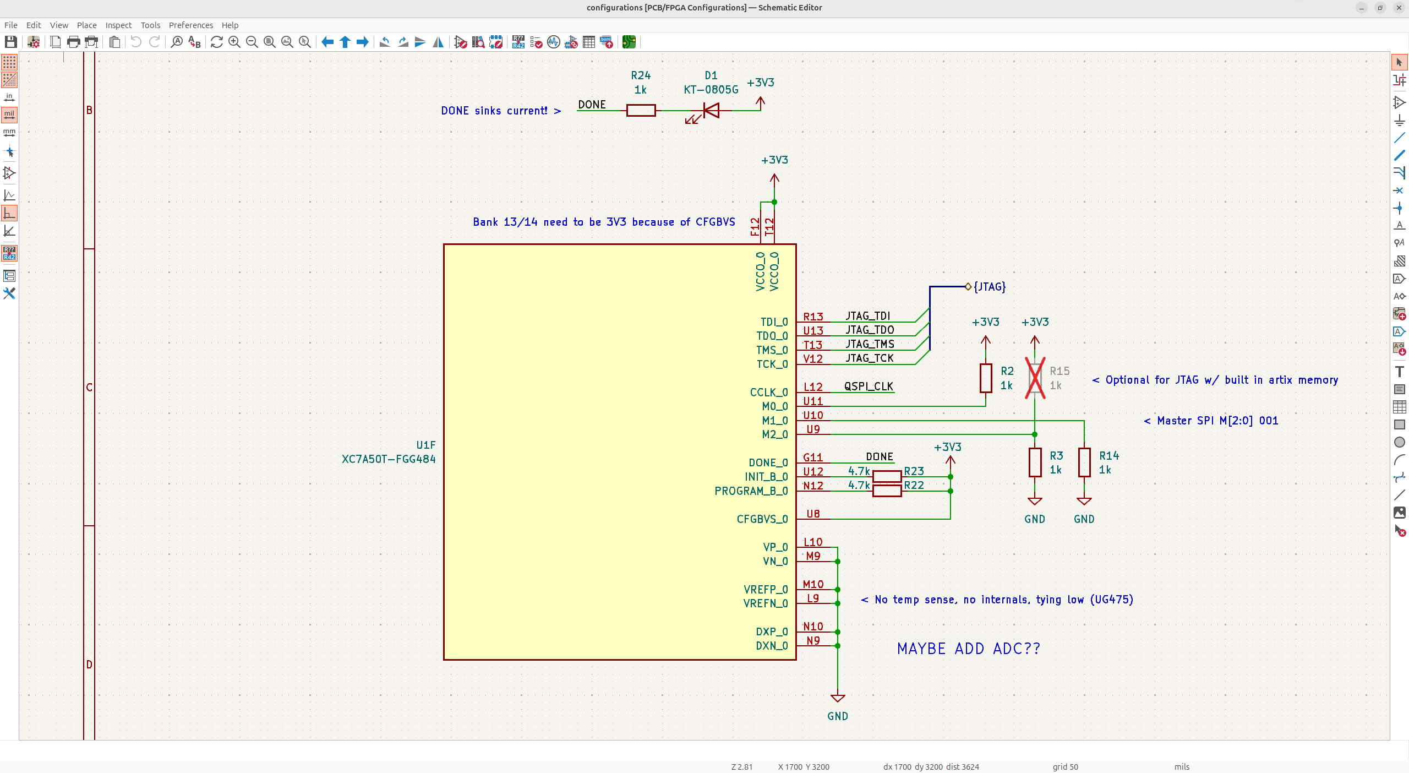
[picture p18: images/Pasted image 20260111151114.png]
Pasted image 20260111151114.png


- DONE is wired so that the LED will turn OFF when the configuration is finished and ON when it's actively configuring. 
- INIT is just a configuration pin that tells you if there's any configuration errors and needs to be pulled high <= 4k7R
- PROGRAM is another configuration pin that's used for configuration reset, and I just needed to pull this high. After reading this a second time, I decided to actually add a button to manually reset it if I wanted to, because this board is technically a devboard ya know (shown below)
- CFGBVS is a bank voltage configuration, it's needed because there's configuration pins on multiple banks so to maintain a near the same voltage of all of the them, I pulled this high to tell the artix 7, they're all 3V3 essentially
- And then, VP/VN, VREFP/VREFN and DXP_0/DXN_0 are essentially just part of the XADC to get internal reads of the FPGA and whatnot, and I just tied them low for now to disable all of that, but I want to revisit it, but not necessarily change any of it!

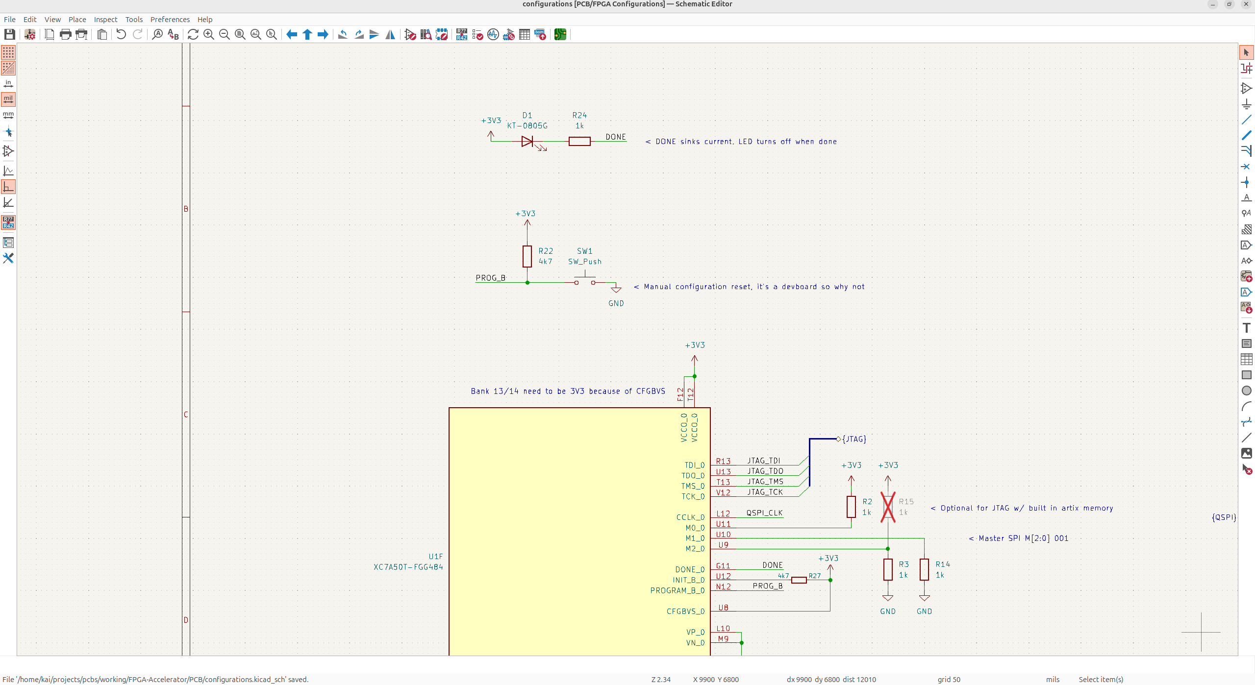
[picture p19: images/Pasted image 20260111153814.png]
Pasted image 20260111153814.png


## Fun DDR3 wiring time now :D - 6 Hours

Now that I've wired up the flash storage, I need to add in the DDR3 memory! Flash storage is non-volatile which means it stores information long term, retaining all of it without power, while RAM is volatile and is used for active tasks (but you probably knew that ;). 

DDR3 works pretty fast, so you have to pay attention to how you wire it! I chose my RAM from an artix 7 datasheet which specifies the compatible ones you can use, and I chose MT41J128M16JT.

This is a 2 Gb (gigabit) memory with 16 bit data width which means it's 256 MB (2Gb / 8) of memory that can fit 128M words 16 bits wide, because 2Gb / 16 = 128! 

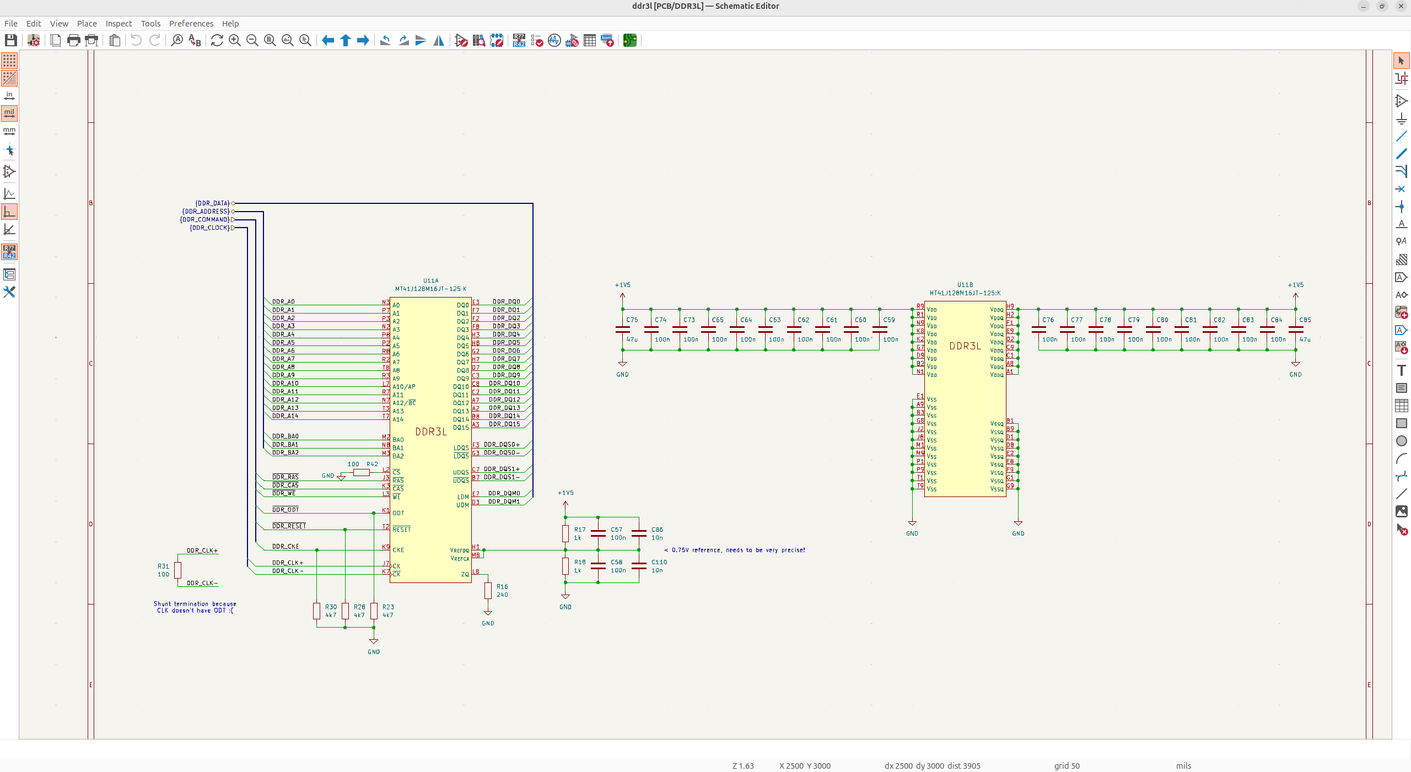
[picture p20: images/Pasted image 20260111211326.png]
Pasted image 20260111211326.png


I created this custom DDR3 symbol because I like to have my decoupling pins visible so I don't make any dumb mistakes. I did a 100nF cap per VDD pin and then a bulk cap near both sides to keep it stable.

Next, I wired all of the address, command, data and clock buses to hierarchical sheets to keep it clean.

CS# is then tied low, because I'm only using one memory IC, and I have pulldowns on ODT, CKE and RESET as suggested from most reference boards. I put a 100R shunt resistor (an AC resistor) to match the differential impedance of 100R, and then ZQ is tied to 240R which is like a calibration pin and needs to be tied with this exact value! 

You'll notice a perfect split voltage divider on Vref, which is essentially just half of VCC, and it needs to be really precise to distinguish cleanly between high and low data signals for fast DDR3 signals. I put a bunch of decoupling on it to make sure it's really precise with very low noise! 

And that's our DDR3 wired, it was a lot more complicated to do than I described, but that's the gist of it! 

## PCIe and the GTP WHAA transceivers ;) - 5 Hours

Now that I've added DDR3 in, I can power on my board, fully program it and execute commands on it too! Now I need to wire the PCIe lanes to the GTP transceivers which lets me board connect to your computer via the m.2 connector! 

Remember earlier how we added in the m.2 connector for power, well now I just have to wire all the lanes up and came up with this:

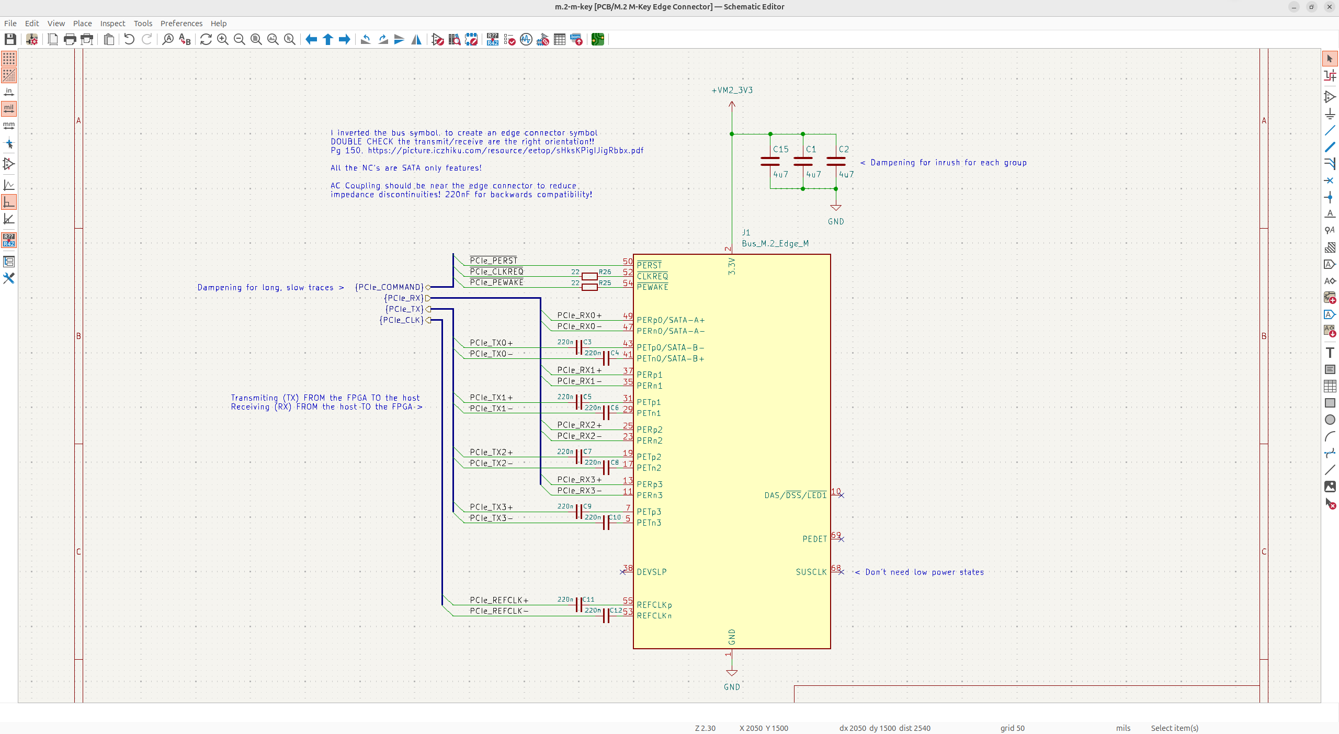
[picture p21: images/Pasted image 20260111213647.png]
Pasted image 20260111213647.png


I changed up the decoupling to instead be a mid range cap per group of pins, because all I really care about is dampening the inrush when plugging the board in/out and powering it on. 

Now let's list out what all of these signals are for! All except for SUSCLK are SATA only pins, and SUSCLK is just for low power states, when you sleep your computer and want to still maintain basic functions which I don't want.

Next, I actually modified my old symbol to create this edge connector symbol which basically just inverses the PCIe text to be more accurate of what's happening on our board. So the pins that were originally receiving PCIe in the form of a bus, are SENDING them now on our board. So all of these transmits, are what's transmitting to our card.

It's mutually known that the side receiving the signals should handle it's own AC coupling, so my FPGA TX lanes, which are sending from the edge connector, and receiving into my board, are going to be AC coupled! 

Because PCIe is close to a fundamental square waveform, it's got sharp edges. So these capacitors in parallel filter out the DC noise, and only allow the switching waveform noise to pass through, pretty cool huh! I used 220nF because it's suggested for if you want multiple generation backwards compatibility because you can use like gen 3 in gen 2 systems, gen 4 in gen 2 and so on and so forth.

CLK also has AC coupling because the direction isn't fixed so they should both be handling it regardless! 

Next, you'll notice 22R dampening resistors on some of the command lines. These are the longer and slower command lines which just travel really far, so I just want to make sure nothing got messed up on the way. PERST is a bit faster so I don't want to cause anti-resonance by adding in dampening resistors on it.

Now we need to just wire these PCIe signals into our FPGA, and BOOM, we're done!

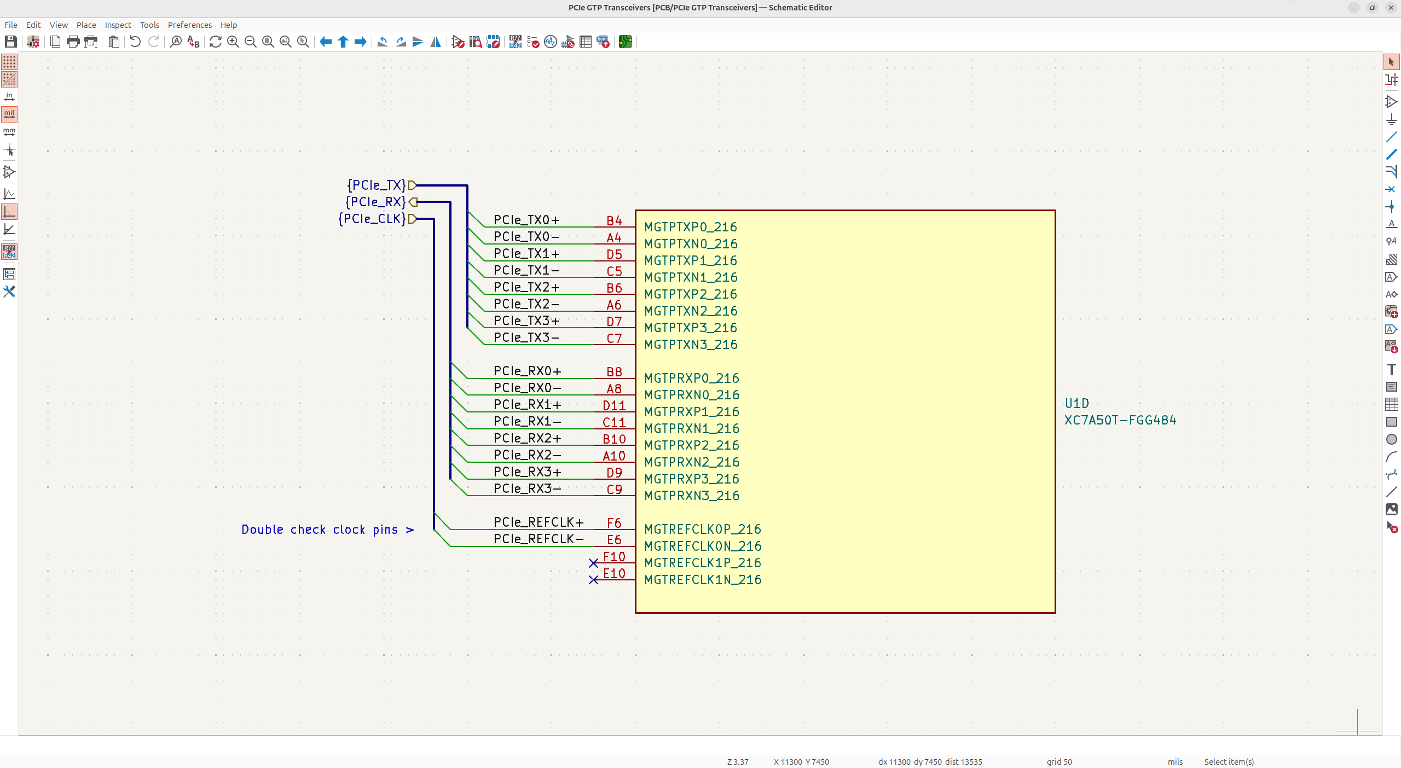
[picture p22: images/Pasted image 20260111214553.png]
Pasted image 20260111214553.png


We don't use the other clock and it's probably reserved for some other uses, so I'm just going to no connect it for now! I want to double check I did this right later, but it should be fine! 

## Time to HDMI - 6 Hours

Because I want my FPGA hardware accelerator devboard to function as a standalone devboard, I really want to add HDMI so that I can use it as a linux capable device, and some other very fun shenanigans. 

Because you could plug it into both your computer and HDMI, you could do fun things like low latency video output or video processing or even data visualization for the whole acceleration!

So I came up with this little schematic:

Pasted image 20260120061538.png

First of all, I don't want ethernet powering my board, so I added a diode to prevent that, and it's connected to VBUS so if USB is plugged in, you get the extra features from HDMI.

I want to actually add a really small boost onto the board so that I can get these features, so I'll think about the best way of adding that! 

My board is pretty noisy, so I added a 1uF cap just because I can, and then of course 100nF for basic decoupling.

The only signals that actually need level shifting is DDC because it's I2C so it's decently fast and important signals. I decided to do some fancy current limiting on HPD so it's a really weak 5V signal that can't damage my FPGA but the FPGA can clamp the voltage to still be able to read it! 

And then CEC is just the electronics control and it's a 3V3 signal that I just need a weak pullup on! 

I added ESD protection to all of the lines, just because I want to create a pretty professional board, and I also added minor AC coupling because it's really fast edge-rate signals.

I think I had a really strong fundamental understanding of this wiring which I'm really proud of myself for, but I really need to get that 5V sorted out, and a $1 boost might be the best way to do that. 

## Ethernet shenanigans - 7 Hours

The second peripheral I wanted to add onto the board is ethernet! 

Ethernet is really cool to add to an FPGA board like this, because it allows you to use the FPGA as like a firewall of sort, or even send signals, and it just has some really neat use cases.

I decided to use a magjack with integrated magnetics and other useful stuff because I don't want to have to worry about all of that working with ethernet for the first time. 

Pasted image 20260120062520.png

First, you'll notice really strong pullups on MDI lines. These aren't actually pullups, and are instead parallel termination. Essentially when signal reflections hit these lines, they'll sink into the power/ground instead of just continuously reflecting, and this is why it's on the analog rail, so the power can get filtered! 

Next, you'll notice my basic decoupling and termination on TX/RX lanes. The RX termination will be close to the PHY, and the TX termination will be closer to the MAC.

RMII needs a 50 MHz crystal, so I've added that in, alongside a feedback resistor which just makes the crystal function smoothly, but you don't really need that so it's just DNP.

I added a button onto the ethernet PHY to force reset, because it's a devboard, I just want a bit more customization, so I decided to just add this!

Finally, we have the LED's, one is pulled up internally, and one needs an external pullup, but once they have pullups they act as current sinks so I can just wire those as sinks to the PHY LED's.

And BOOM, we have ethernet fully wired on our board! I'm really excited to work more with ethernet and understand the PHY and magnetics some more, because they seem really cool!

## Revisions and starting to route everything - 8 Hours

Now that I've finished wiring my ethernet, I'm actually done my schematic!

Now we can work on laying out all the components onto the board so we can make sure that it fits nicely! This is a really iterative process, but you can get a nice rough layout which you'll modify greatly as you route, but it'll form the basis of your board!

**I actually decided to remove my ethernet in this step, because the PHY was too large for such a small card, it wasn't worth it...**

First I layed out all my large components onto the frontside of the PCB so that I could get a grasp of how the board would look.

Next I added all the passives for the top layer to have short loop area's, and really just going for optimal practices. There's a lot of thought that goes into doing this, but it's not too difficult!

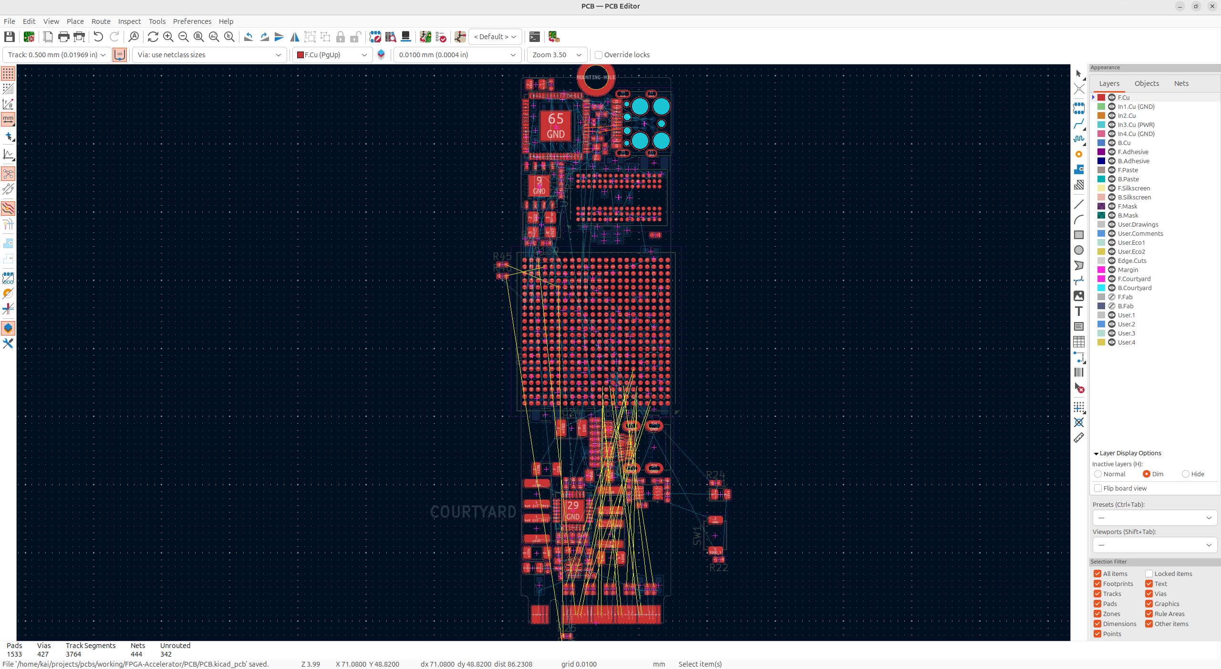
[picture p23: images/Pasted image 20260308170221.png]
Pasted image 20260308170221.png


Next I took a look at the back side. Essentially where I couldn't fit all of the other passives is where I would place these ones. This is especially true for stuff like my decoupling which won't have space on the front because of my BGA DDR3, artix 7, etc.

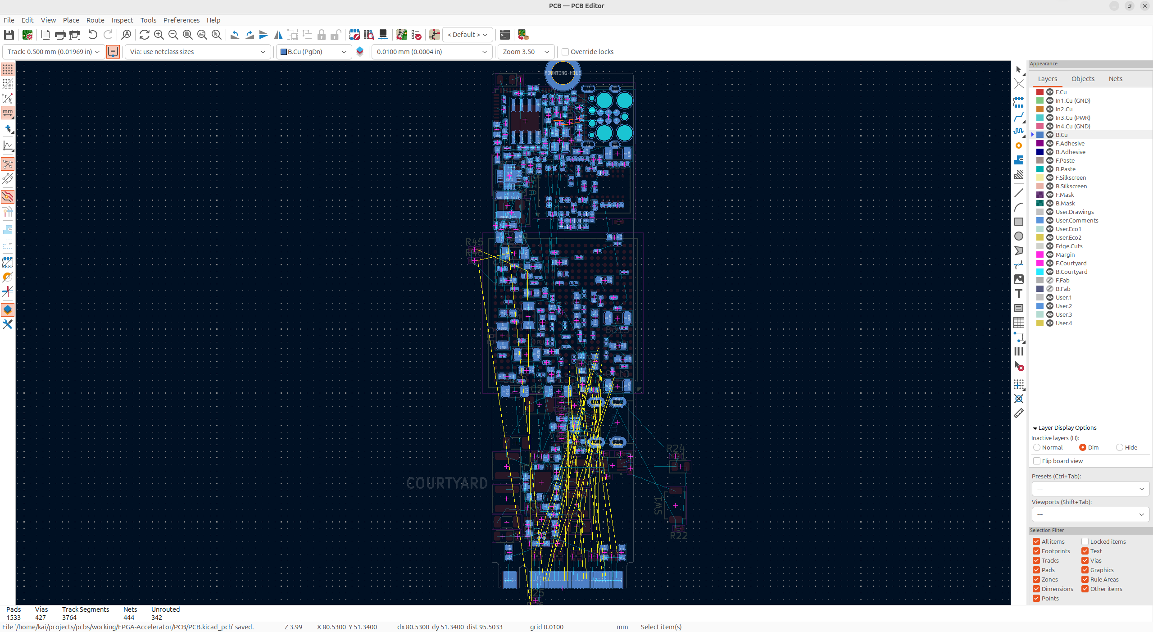
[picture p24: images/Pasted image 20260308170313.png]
Pasted image 20260308170313.png


There was a LOT of thought that went into this layout. I first modelled it off of existing boards, so fpga in the center, power management at the bottom, connectors on one side, and then USB to JTAG at the top alongside the flash and DDR3!

There's a couple components I left off the board for now, because those aren't too important, and they're in spots where traces might go, so I don't quite know exactly where I want to put them!

This was actually after I started routing, so most of these components are in their final spots. Lots more components were actually off the board, and it's a constantly iterative process!

## Decoupling scheme and some basic routing - 7 Hours

Decoupling an FPGA and all the other peripherals is extremely difficult. They're power intensive devices and you really need to know the theory behind what you're doing.

The main things I was thinking about, was keeping a short loop area, minimizing trace inductance and properly laying out components for future routing.

Ignore the DDR3 traces, I took this screenshot after doing some intensive routing:

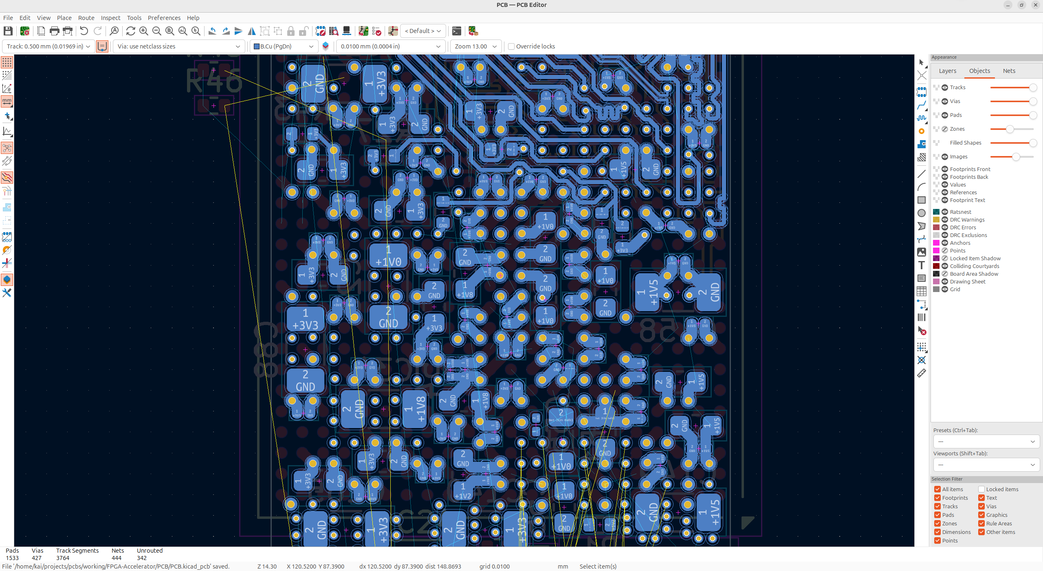
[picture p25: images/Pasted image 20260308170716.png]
Pasted image 20260308170716.png

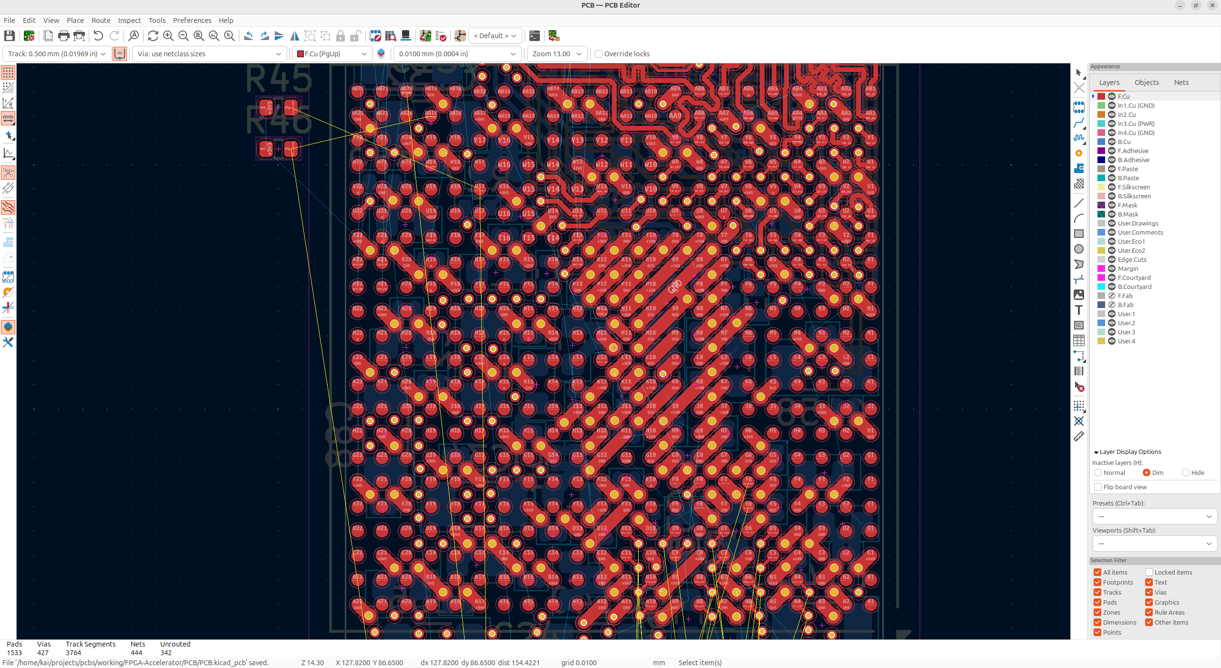
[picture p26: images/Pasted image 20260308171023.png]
Pasted image 20260308171023.png


You can see I used the largest possible trace and via which maximized the surface area of the copper, minimizing the density of the magnetic flux, decreasing inductance which give higher efficient decoupling.

The higher frequency decoupling (470nF) is priority, it should be directly next to the pins it's decoupling. The mid frequency decoupling can be a bit farther away, but you still want to keep it close to the group of pins. And then finally, the low frequency decoupling can be quite far away, but you want to make the path extremely low inductance nonetheless. 

You'll notice that there's no via-in-pad, this is an extra cost that I really don't need, and I want to create an extremely professional board, so it's something that was really important to me.

Now there's a lot of decoupling on this board, but I really just want to go over the FPGA and DDR3 decoupling because those are definitely the most intensive.

Next, let's take a look at our DDR3 decoupling. This needs to be extremely efficient for a hungry device, so we keep the paths short and tight.

You need to keep VREF extremely quiet, so you'll notice a bunch of extra decoupling on that too. 

Ignore these other traces, this is after I routed my DDR3 which we'll go over soon:

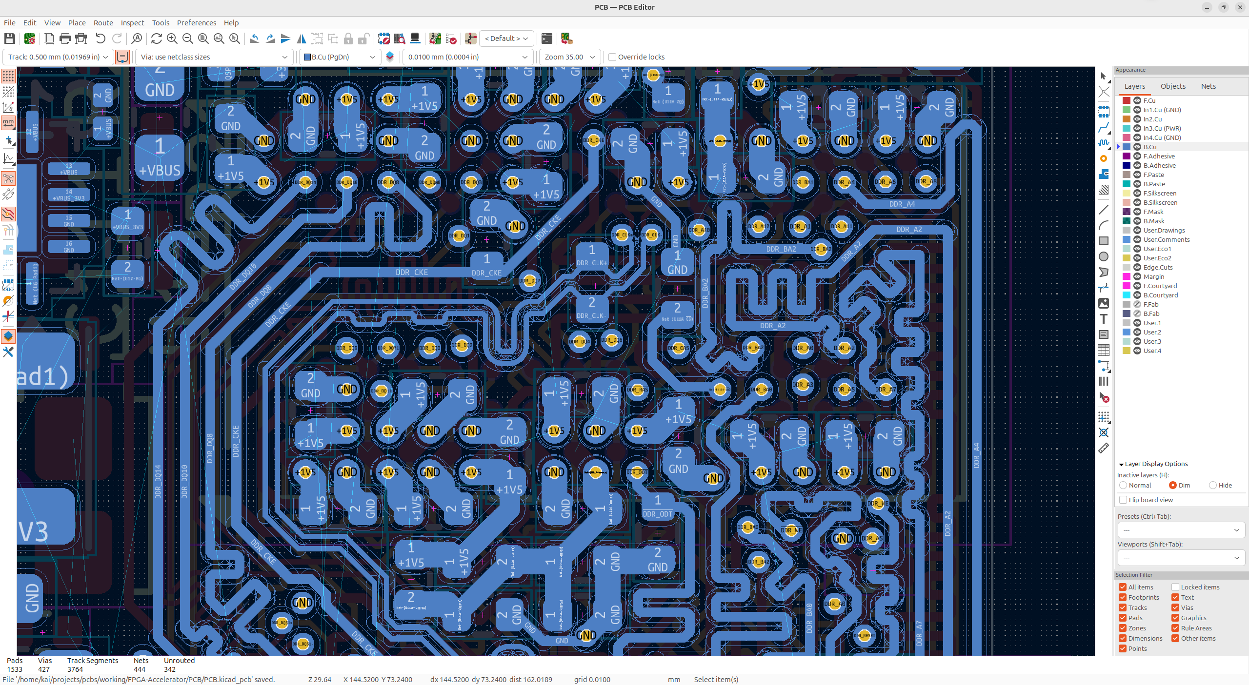
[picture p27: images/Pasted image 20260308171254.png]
Pasted image 20260308171254.png

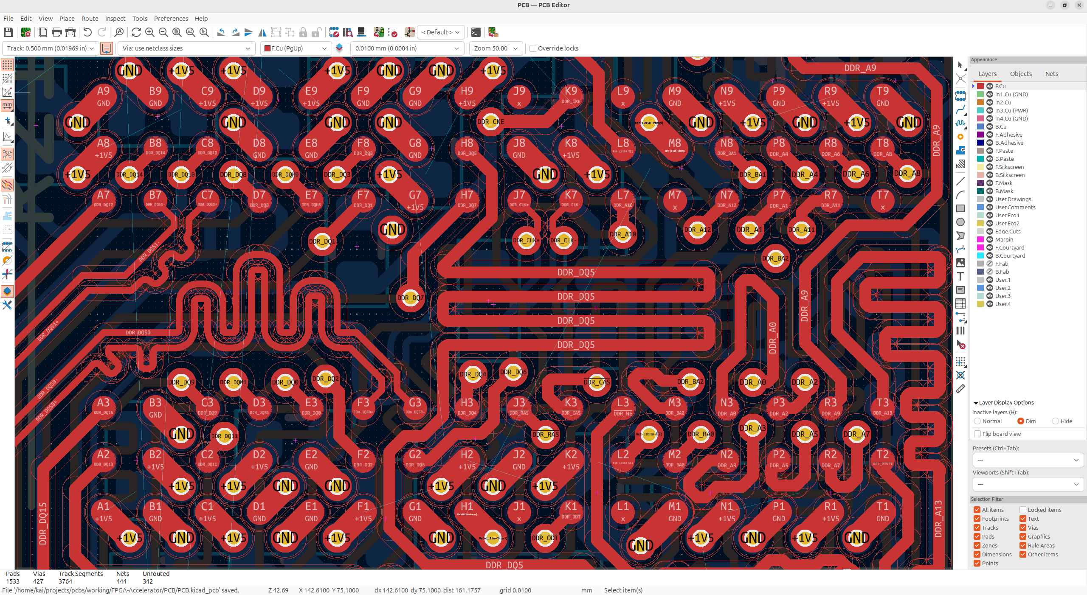
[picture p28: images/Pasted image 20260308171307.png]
Pasted image 20260308171307.png


And just like that, we've efficiently decoupled our intensive components! Next let's take a lookat the most complicated bit of routing, which I've already done a lot of, our DDR3!

## Intensive DDR3 routing - 50 Hours

Now, let's take a look at arguably the most complicated part of our board, the DDR3 routing. 

There's a LOT of considerations when routing DDR3:
- Efficient power distribution and VREF
- Proper configurations
- Proper layout/dogbone/breakout
- DDR3 to FPGA routing
- Length/delay mathching
- Differential pairs

And a whole lot more.

Let's start off with our power distribution. I already went over this a lot, but all of the DDR3 pins should have 100nF decoupling, and medium/bulk decoupling along the sides of the chip. You can see exactly how we decoupled this chip, high frequency decoupling RIGHT by the pins, and then mid/low frequency at the top.

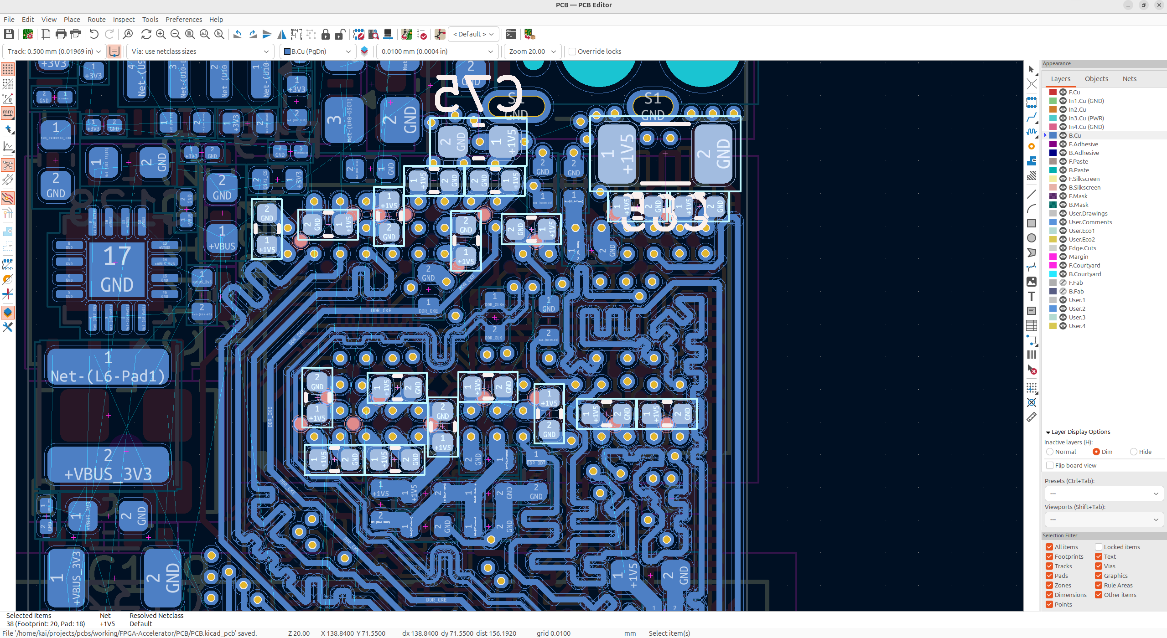
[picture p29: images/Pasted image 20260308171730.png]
Pasted image 20260308171730.png


Next we can take a look at VREF. VREF is a little pesky brat that needs to be well filtered, so we have 100nF to 10nF caps right by the pins so we can efficiently run our DDR3. 

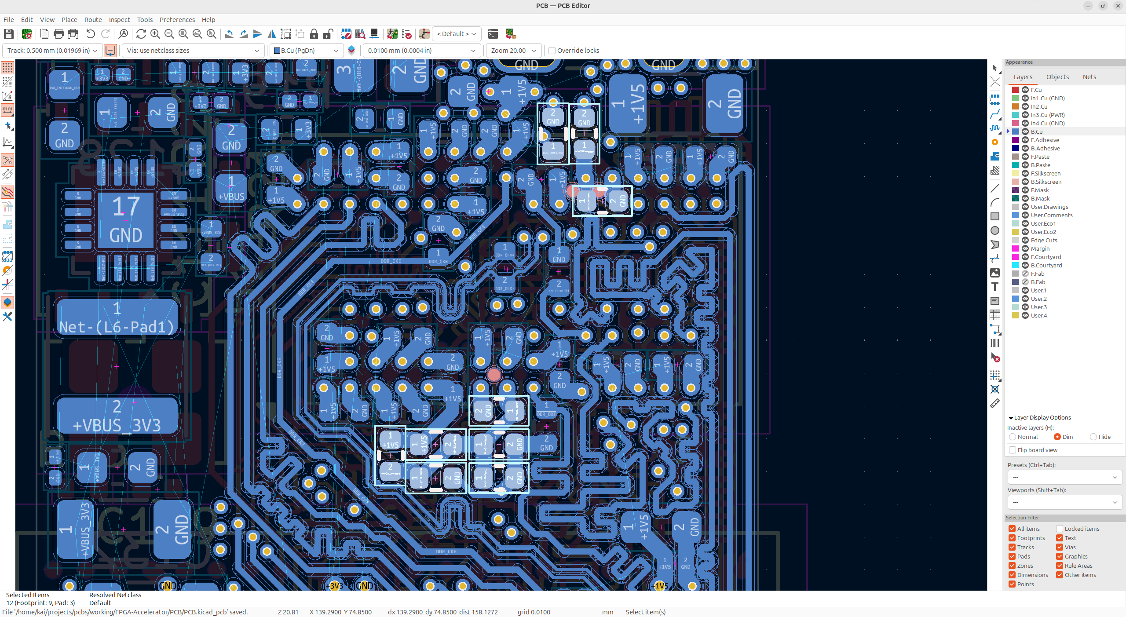
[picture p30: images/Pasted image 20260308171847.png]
Pasted image 20260308171847.png


The layout considerations of these caps is extremely important because you need to image how you're going to get all of your traces through still, so it's a big puzzle game. 

Next we have the actual routing and dogbone. Lots of your traces will need a via to get to other layers, so we put them in the center where there's no pins, perfectly placed so we don't get solder taken away from the pads by the via's.

Routing these traces is definitely what took the longest, because there's so many considerations. 

I routed the traces probably about 10 different times, because you need to pass what's called MIG, which essentially tells you if you used the right pins on the FPGA for your DDR3. The FPGA doesn't have specific pins, but instead byte lanes, where say pins DQ0 - 7 could go, and not other signals, so it's not crazy specific but still tedious.

After passing MIG, you need to length/delay match all of your signals. This is an EXTREMELY dense layout, so doing this is absurdly difficult and tedious, which took a LOT of time.

I'm not going to explain all of the specifics or else I would basically create my own DDR3 datasheet, the important stuff is all already created and I'm not going to repeat it. 

But this is what our final layout looks like, it's absolutely beautiful and took wayyyyy too long:

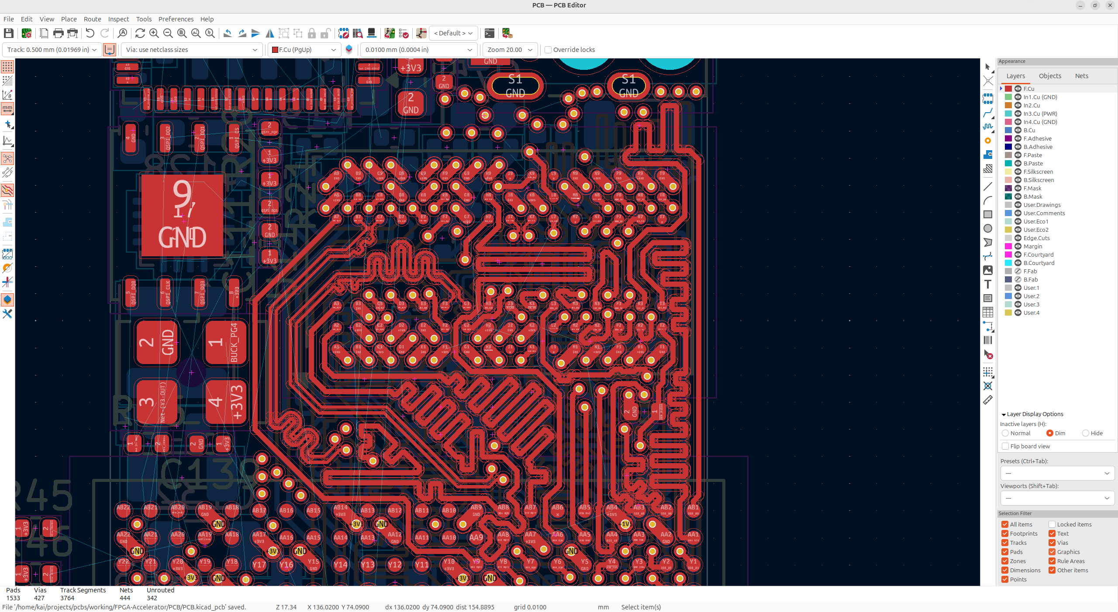
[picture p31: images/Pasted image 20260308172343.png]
Pasted image 20260308172343.png


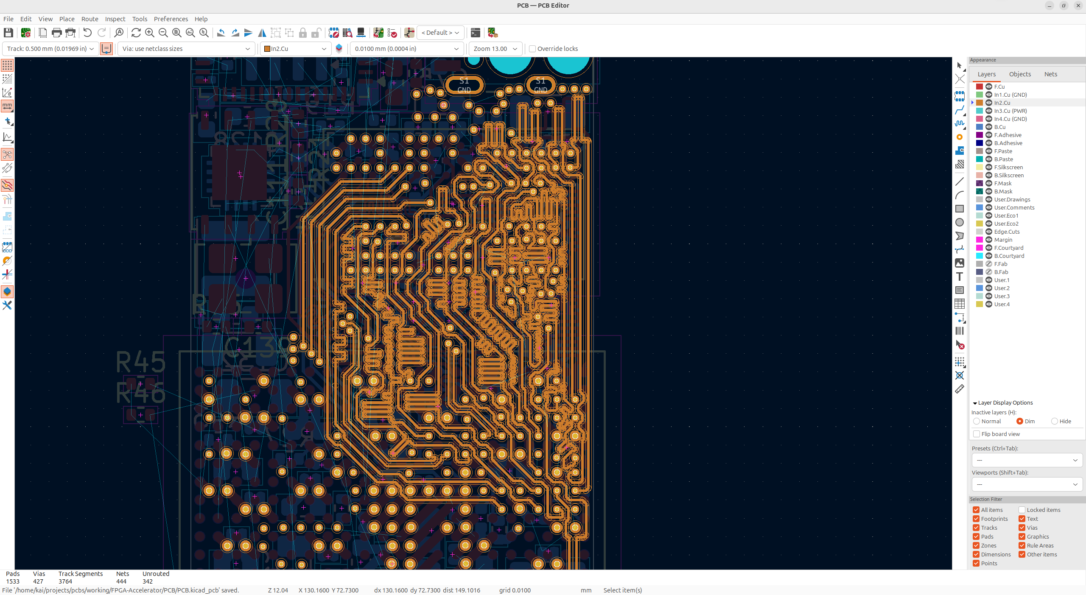
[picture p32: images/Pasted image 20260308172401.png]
Pasted image 20260308172401.png


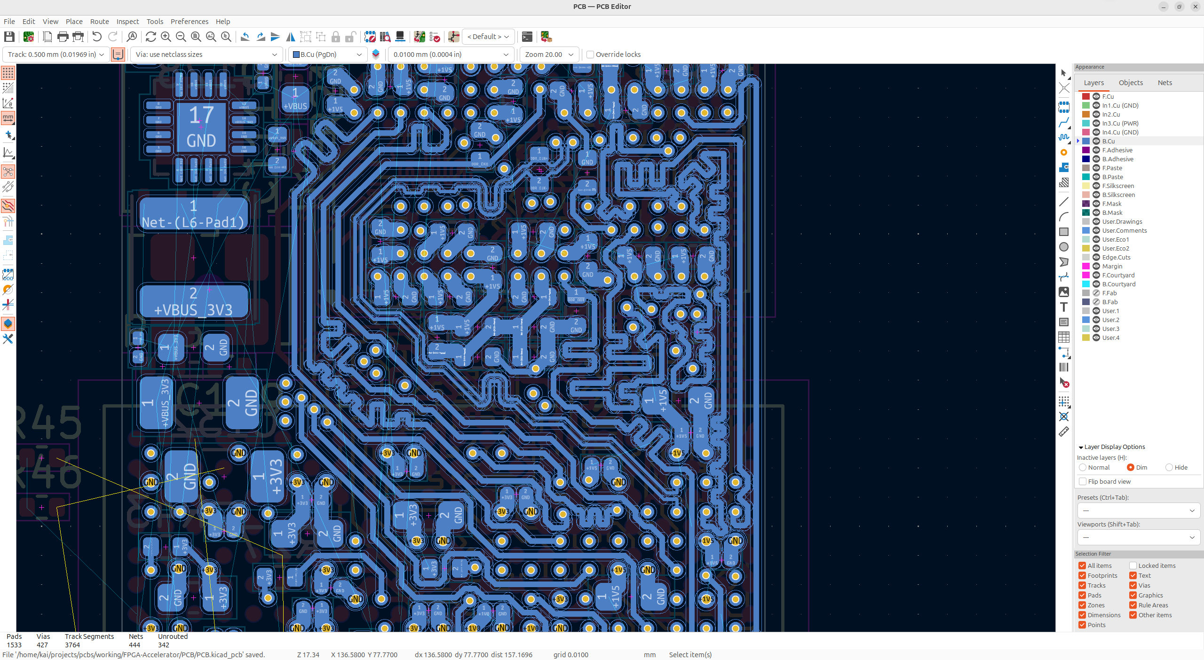
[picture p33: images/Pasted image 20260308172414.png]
Pasted image 20260308172414.png


This isn't actually the end of my DDR3 shenanigans though. I haven't done it yet, but I'll need to simulate the signal integrity of my traces using a field solver because of the extremely dense layout, there's a lot of local crosstalk which could kill my design. 

## More layout and basic routing - 5 Hours

Now it's really hard to say specifically what I'm up to in these parts, but I'm essentially just trying to lay out all the components, and get ready for a massive spree of routing. Because all the connections are made to be as short as possible, routing everything else is actually fairly simple.

All of these small things is just like configurations, passives, all the small details ya know.

So let's take a look at the current status of the board:

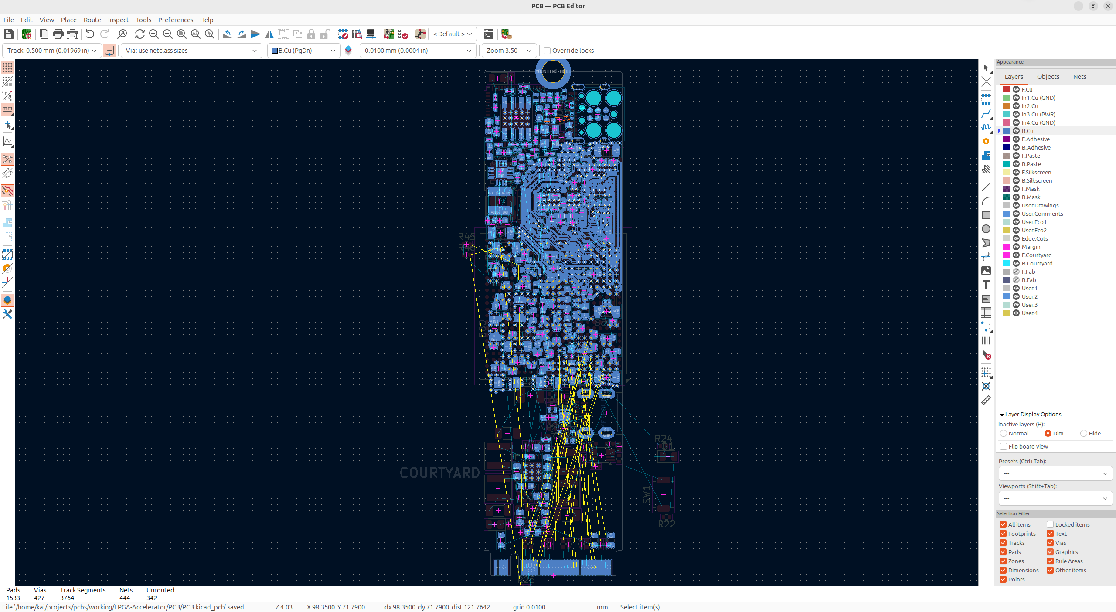
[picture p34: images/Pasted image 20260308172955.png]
Pasted image 20260308172955.png


Pasted image 20260308173008.png

Pasted image 20260308173018.png

The only components left are this button with it's resistor and an LED, because I want to figure out if I want to add some more LED's and I don't quite know exactly where I want to put these yet, so it's not crazy serious.

I was also running the DRC during this time to make sure that I didn't have any problems that would annoy me AFTER I finished doing all of this routing, so it was just like a lot of small stuff I was up to.

Let's just take a minute to admire this beautiful, near 100% density layout :D 

Pasted image 20260308173205.png

Now that I've actually put everything on the board, it's time to actually route it!!!! 

This honestly won't take too long, because all the connections are so optimally placed already, it's just a quick trace ;) 

## Top half routing - 6 Hours

Now initially I thought that the rest of my layout would've been simple to route on 6 layers, but I was actually kind of wrong. 

The first thing I need to do, was route the top half, to the bottom half. This means USB to JTAG, QSPI flash, crystal, etc. I decided to keep the QSPI and JTAG signals on the middle layer and then leave all the simple direct connections to the top and bottom so they could be low inductance. 

Pasted image 20260329142145.png

Pasted image 20260329142208.png
Pasted image 20260329142235.png

You can see it's getting extremely dense which makes it significantly harder to route. I'm currently still in the process of routing the JTAG lines, but it's almost done. 

## Power architecture - 7 Hours

Now that I've routed pretty much the entirety of the top half, I need to route most of the bottom half. This half is a bit more important because it consists of the high speed PCIe gen 2.0 and also the power architecture/rails.

Now this part will only consist of the power architecture just barbecue it took a really long time and was a major part of this board. 

So the first thing I had to do was layout my buck converter so that I could efficiently branch out the power fills on the same layer. 

I drew it out and then matched it onto the cube shaped quad buck:

Pasted image 20260329142723.png
Pasted image 20260329142733.png

This gave me a good visualization of how to do the fills, so this is how I layed out my buck:

Pasted image 20260329142828.png

I also added a small 5V buck boost so that I could always power the HDMI, which I thought was worth it so I didn't have any unpredictable behavior on this board. It'll also let me break out another 5V debug pin which is pretty useful to people. 

Now that I've finished the buck schematic and routing, I can do my power fills and the rest of the bottom routing. Do note that a lot of my bottom stuff has already been routed, and that this is just an old screenshot, but you'll see more in the next log.

And this is how I did my power fills, pretty clean and messy at the same time:

Pasted image 20260329143046.png

Now that I've done all my power fills, we can move onto the next and one of the final parts!

## The bottom routing - 5 Hours

Now the power architecture was quite a large portion of the bottom routing, but there's still quite a bit like the PCIe and bringing out the JTAG/QSPI pins on the FPGA to the top.

So the first thing I did was route the PCIe. This took a lot of mental bandwidth to figure out, but I did it pretty cleanly, without too many via transitions.

Pasted image 20260329143317.png

And then next, I routed out the HDMI and all the other smaller things I need to do like the power good signal for the crystal from the buck converter and many other things!

Pasted image 20260329143417.png

Pasted image 20260329143435.png

And then finally, you'll notice some of the other small things on the board like the LED's, small passives , configuration stuff and other things I was waiting to add when I had less space. 

Now, I just have to route the 34 remaining things and also do my UART and HDMI routing! 

## Some chill routing - 4 Hours

Now I'm on the final stretches of this board with 34 unrouted items. But the thing is, this number is kind of a lie, because some of these are like badly done fills so you need to completely redo them.

So I did quite a few different things this time. I was mainly fixing DRC errors and routing the smaller things. This includes doing stuff like:
- Fixing small traces to decoupling/resistors that I forgot to add
- Redoing the M.2 3V3 power fill to be much more efficient
- Routing some small, low frequency signal pins
- DRC fixes

There's honestly not too many changes in the photo's, but here's the new power fill and feel free to check the commit history :D 

Pasted image 20260331072314.png

Pasted image 20260331072333.png

18 unrouted now, way less DRC errors, we're getting really close!

## Finishing up the project- 20 Hours

I went into a crazy focus mode in order to finish up this project, so I'm constraining it into one log.

So the first thing I did was finish routing everything onto the board:

Pasted image 20260727194611.png

But I really wanted to add more LED's and also some header pins so that I could debug stuff, so with a lot of finesse, I added those in too:

Pasted image 20260727194649.png
Pasted image 20260727194707.png

And after fixing all of the DRC errors which were mostly just problems with the fills not getting to some components, which required tuning up the settings for the fills, the board design is done :D

Pasted image 20260727194737.pngPasted image 20260727194744.png

*I also added in some 3D models of the missing components so the board would look more complete*

Now I just had to create the BOM which was pretty simple because all of the complicated parts already had their part or manufacturing #'s because I was putting them in, while designing the board instead of after:

Pasted image 20260727194846.png

*Beautiful :D*

Then, I produced all of my fab files, double checked everything and now we can move onto the README!

I'm a big perfectionist when it comes to my README's, so this one was no different. I simply did an introduction + custom features + PCB Design + firmware + production notes in my README and just like that, it's complete.

Pasted image 20260727195011.png

My entire project is finally complete, the culmination of many months and nearly 200 hours of work, and it's beautiful.

I'm probably not going to get the board manufactured until I re-do the board with a better stackup so I can reduce the trace width, and reduce the cross-talk for the DDR3.

Extremely constrained boards like this are really tricky, but I think I did a great job and in the future, I'll probably work on boards with larger footprints so I'm not as constrained... lots of cool stuff to come :D

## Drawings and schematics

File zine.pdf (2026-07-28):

# M.2 FPGA Hardware Accelerator Devboard

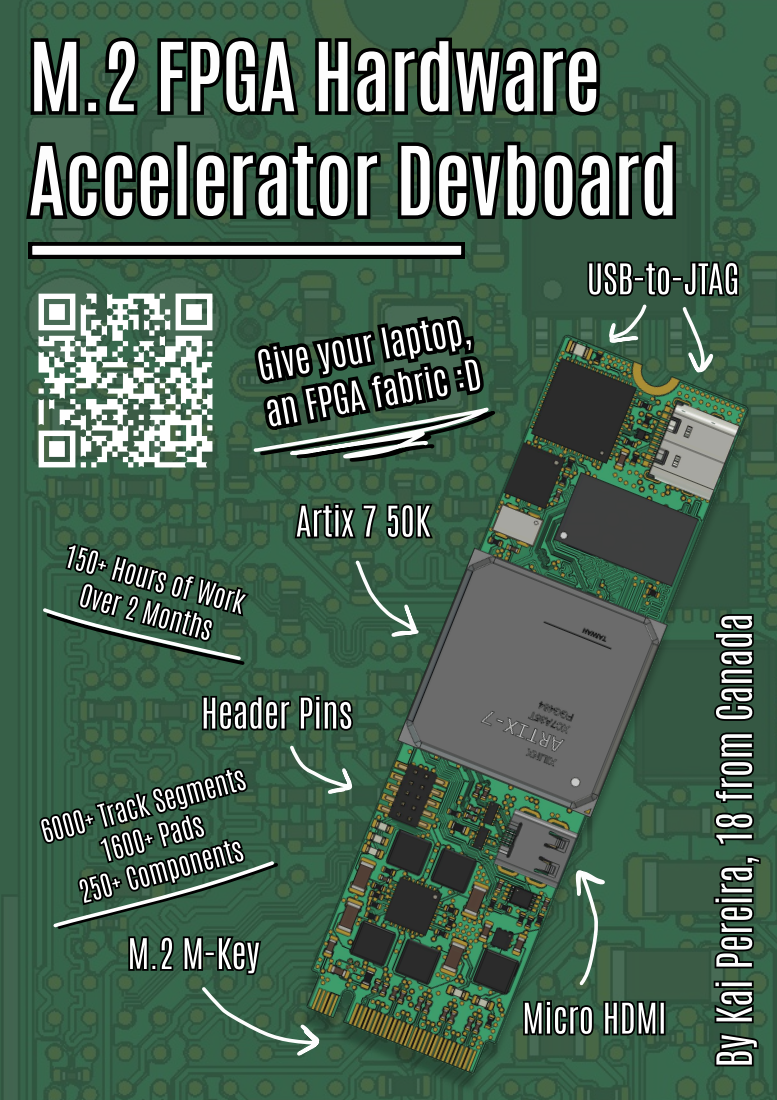
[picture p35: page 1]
Over 2 Months; Header Pins; Artix 7 50K; Micro HDMI; 6000+ Track Segments; 1600+ Pads 250+ Components; M.2 M-Key

USB-to-JTAG By Kai Pereira, 18 from Canada

Give your laptop,

an FPGA fabric :D

150+ Hours of Work

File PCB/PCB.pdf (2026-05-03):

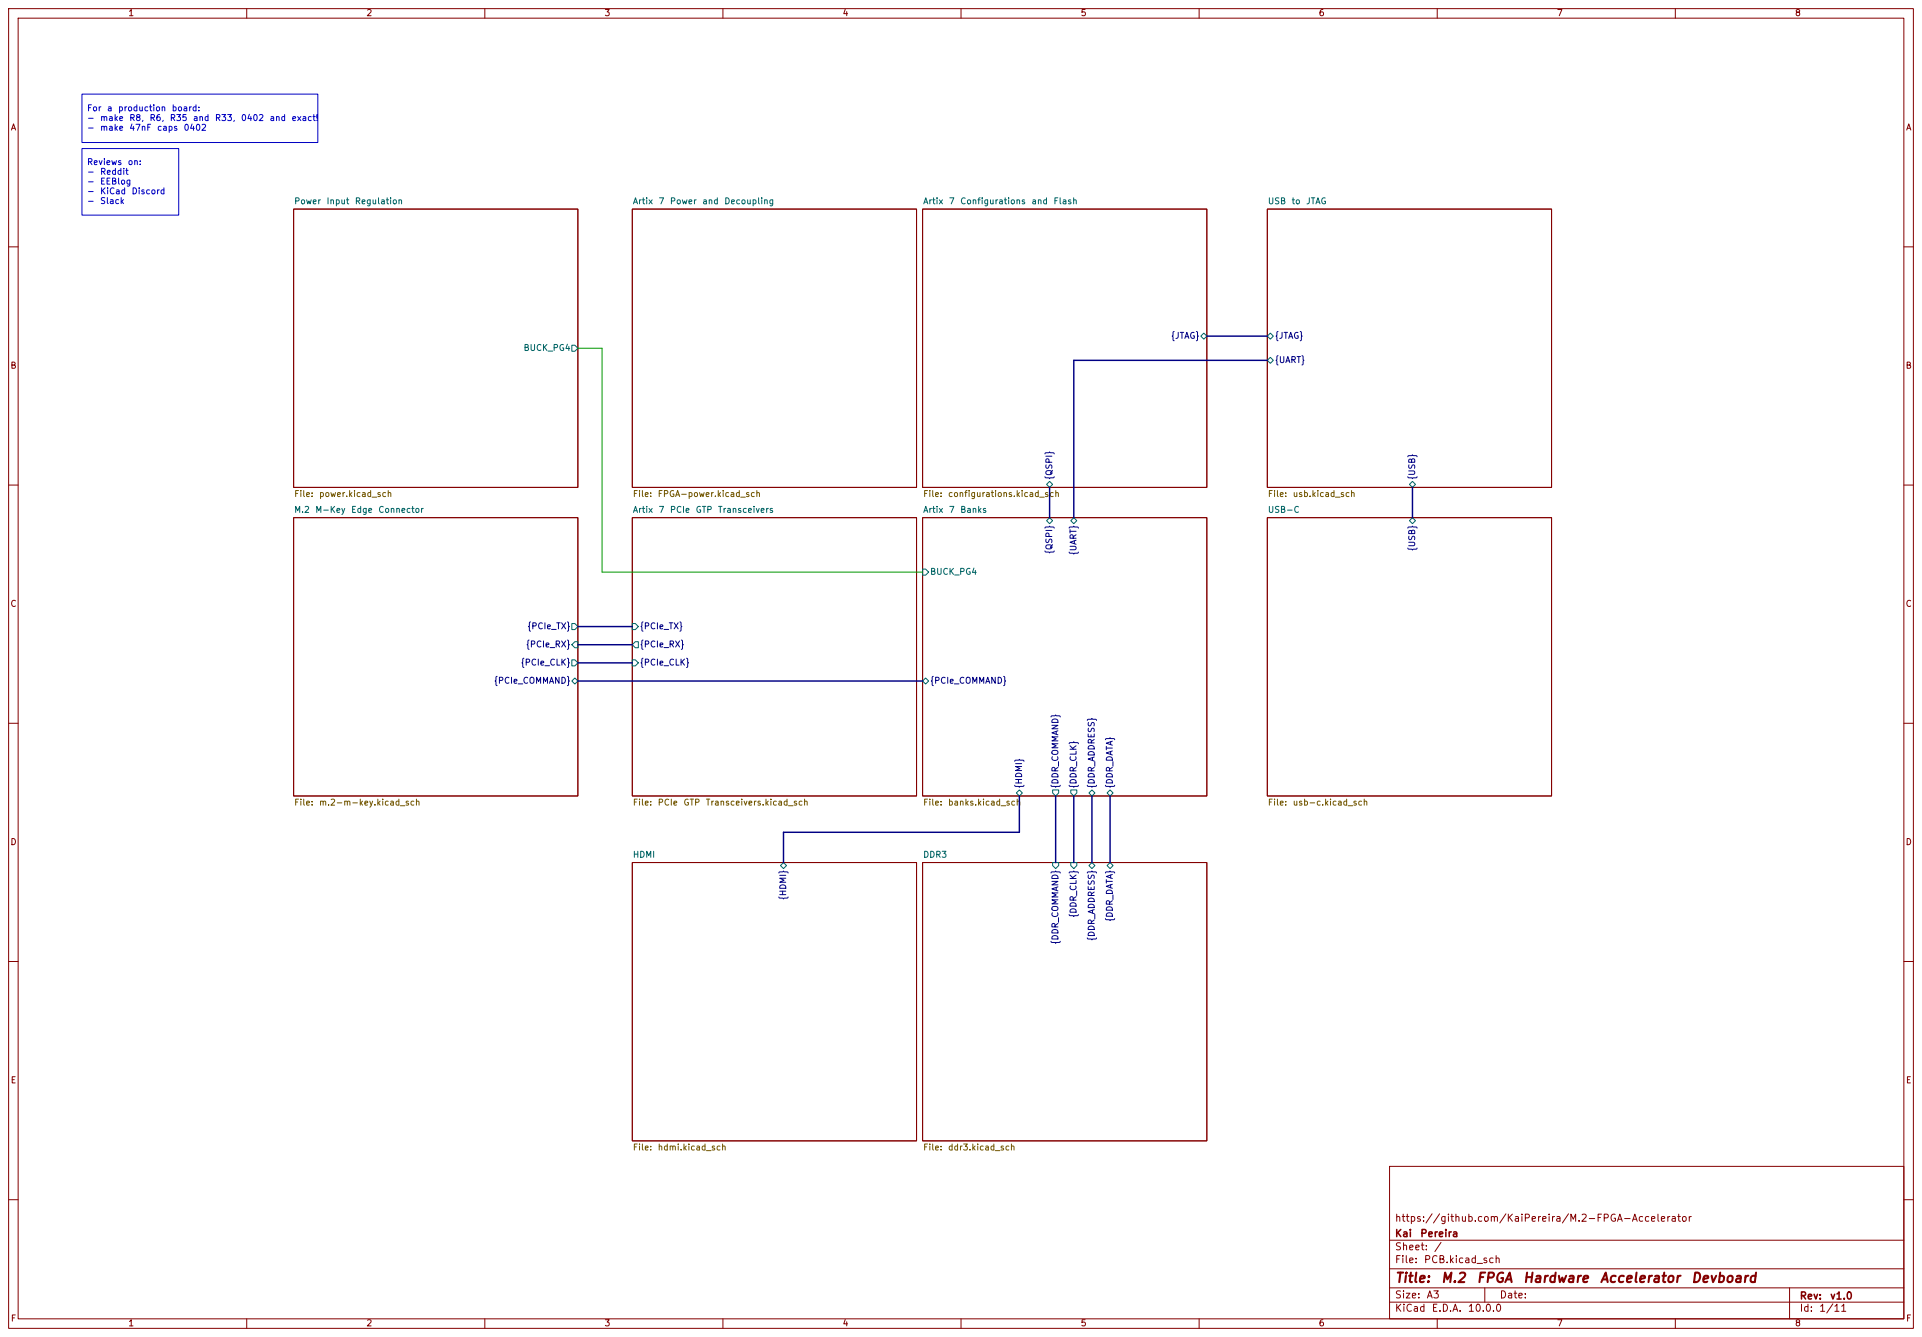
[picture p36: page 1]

File: usb.kicad_sch BUCK_PG4 Power Input Regulation

Artix 7 Power and Decoupling

Artix 7 Configurations and Flash

{JTAG} {QSPI}
Artix 7 Banks File: banks.kicad_sch

File: FPGA-power.kicad_sch
Artix 7 PCIe GTP Transceivers File: PCIe GTP Transceivers.kicad_sch

File: usb-c.kicad_sch {HDMI} HDMI File: hdmi.kicad_sch

https://github.com/KaiPereira/M.2-FPGA-Accelerator
Kai Pereira
Sheet: /
File: PCB.kicad_sch
Title: M.2 FPGA Hardware Accelerator Devboard

Size: A3 | Rev: v1.0 | F Date:
KiCad E.D.A. 10.0.0 | Id: 1/11

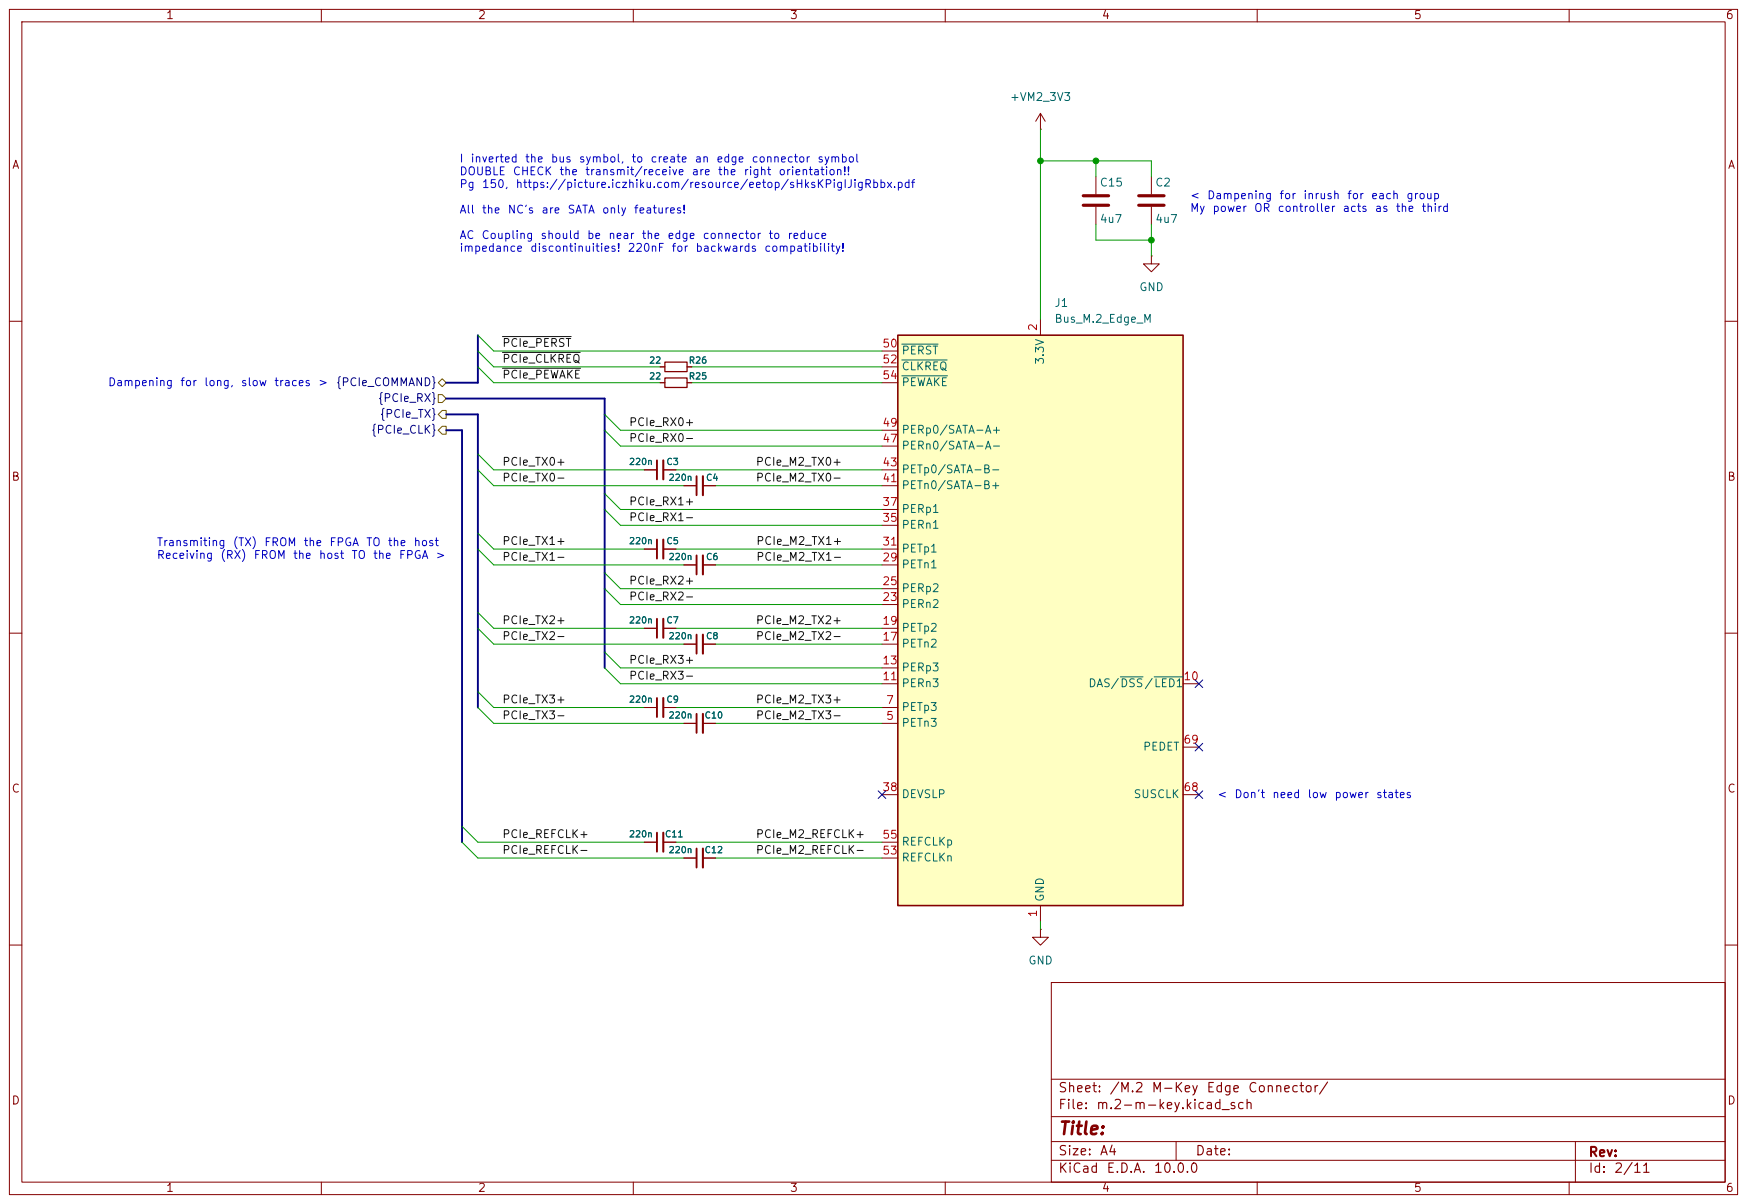
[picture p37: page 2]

I inverted the bus symbol, to create an edge connector symbol
DOUBLE CHECK the transmit/receive are the right orientation!! Pg 150, https://picture.iczhiku.com/resource/eetop/sHksKPigIJigRbbx.pdf

< Dampening for inrush for each group My power OR controller acts as the third

All the NC's are SATA only features! AC Coupling should be near the edge connector to reduce
PCIe_PERST PCIe_REFCLK+
PCIe_CLKREQ

1 3.3V 2 PETn3 5 PETp3 7 DAS/DSS/LED110 PERn3 11 PERp3 13 PETn2 17 PETp2 19 PERn2 23 PERp2 25 PETn1 29 PETp1 31 PERn1 35 PERp1 37 DEVSLP 38 PETn0/SATA-B+ 41 PETp0/SATA-B- 43 PERn0/SATA-A- 47 PERp0/SATA-A+ 49 PERST 50 CLKREQ 52 REFCLKn 53 PEWAKE 54 REFCLKp 55

Dampening for long, slow traces >

Transmiting (TX) FROM the FPGA TO the host Receiving (RX) FROM the host TO the FPGA >

Sheet: /M.2 M-Key Edge Connector/
File: m.2-m-key.kicad_sch
Title:

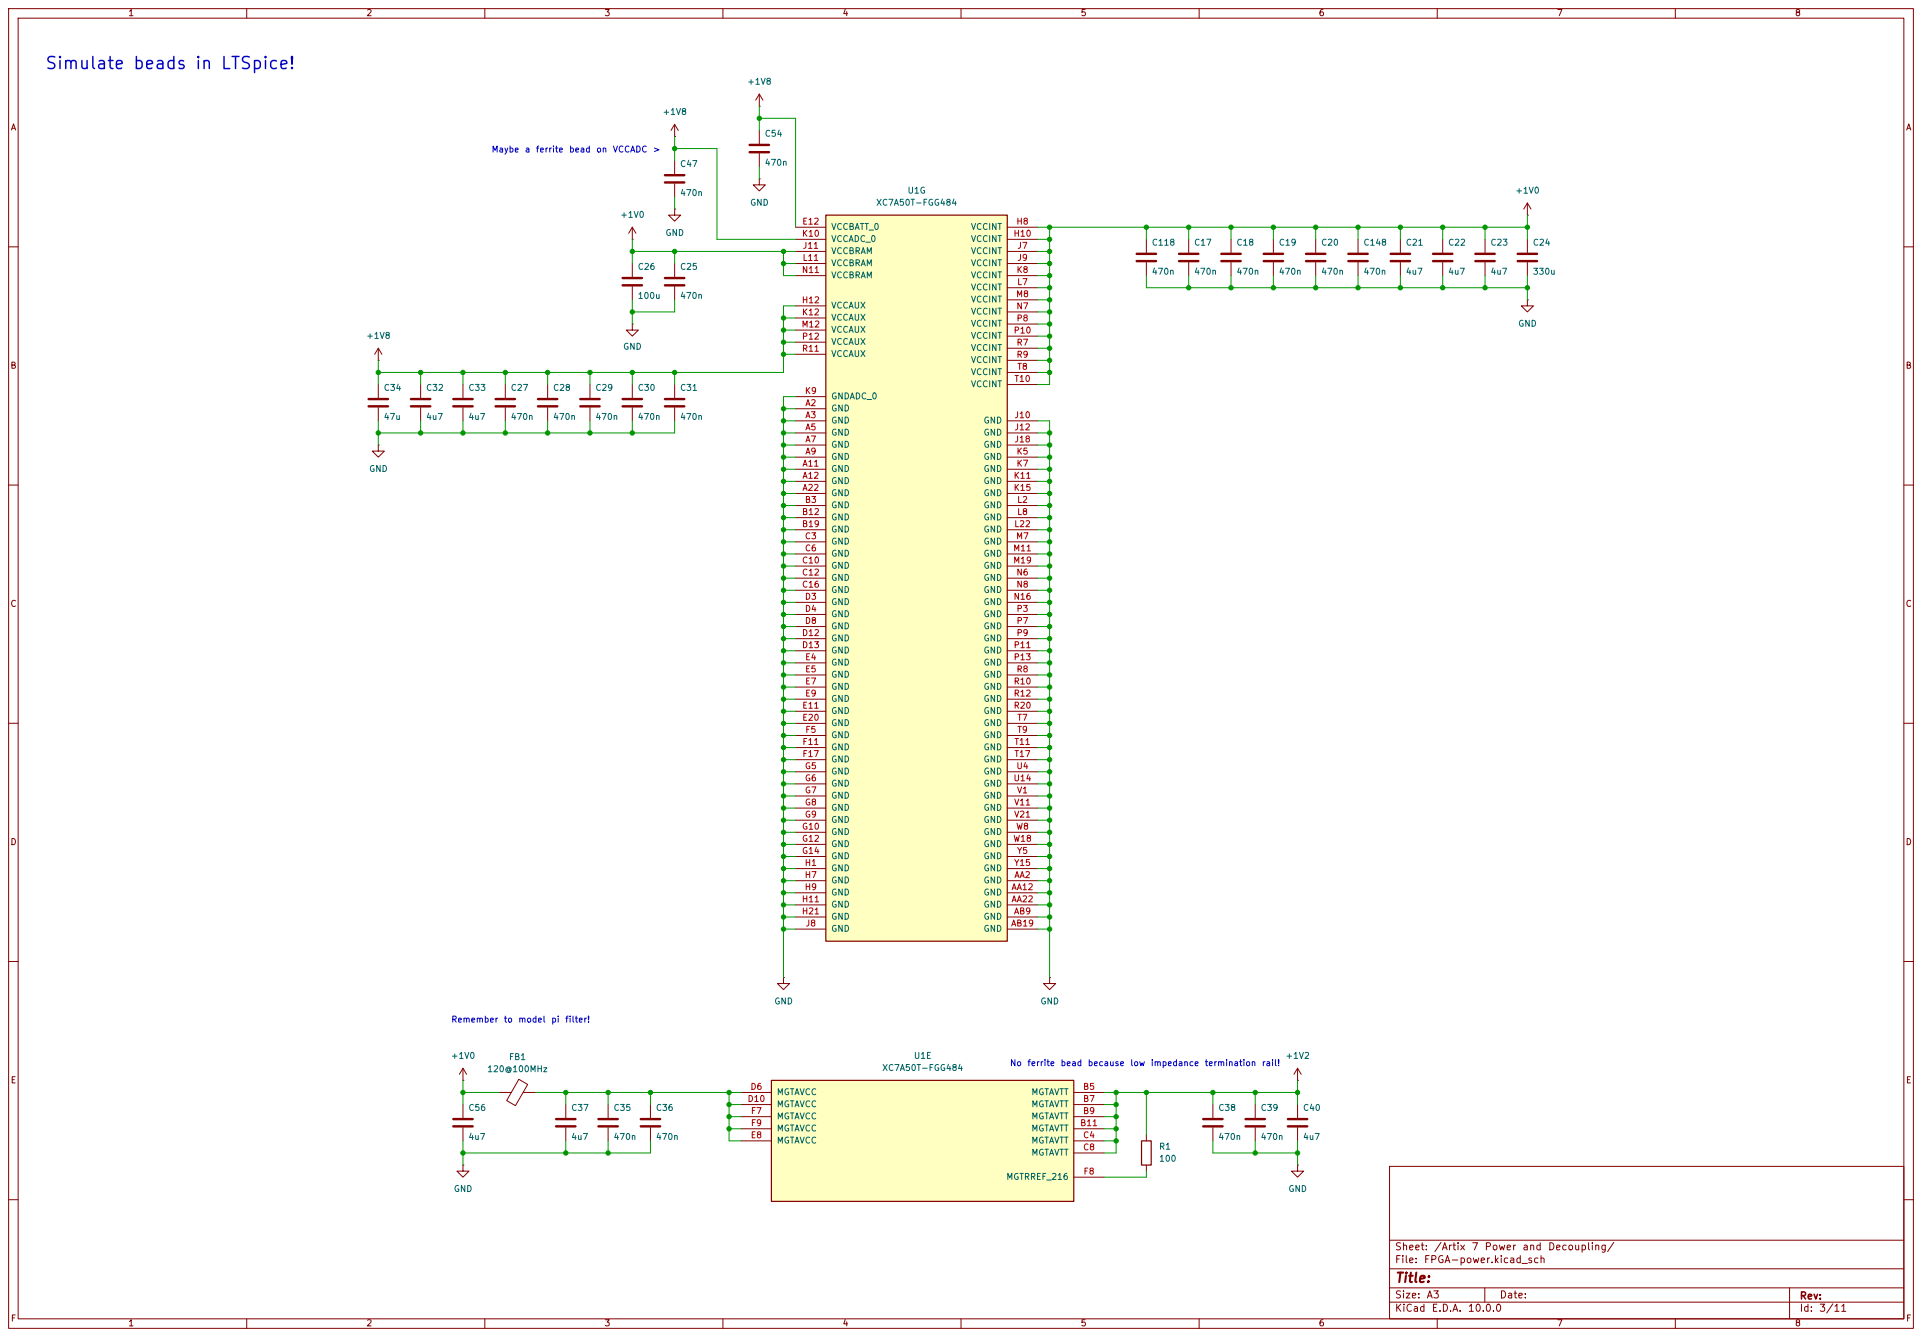
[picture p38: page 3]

Maybe a ferrite bead on VCCADC > Simulate beads in LTSpice!

No ferrite bead because low impedance termination rail! Remember to model pi filter!

Sheet: /Artix 7 Power and Decoupling/
File: FPGA-power.kicad_sch
Title:

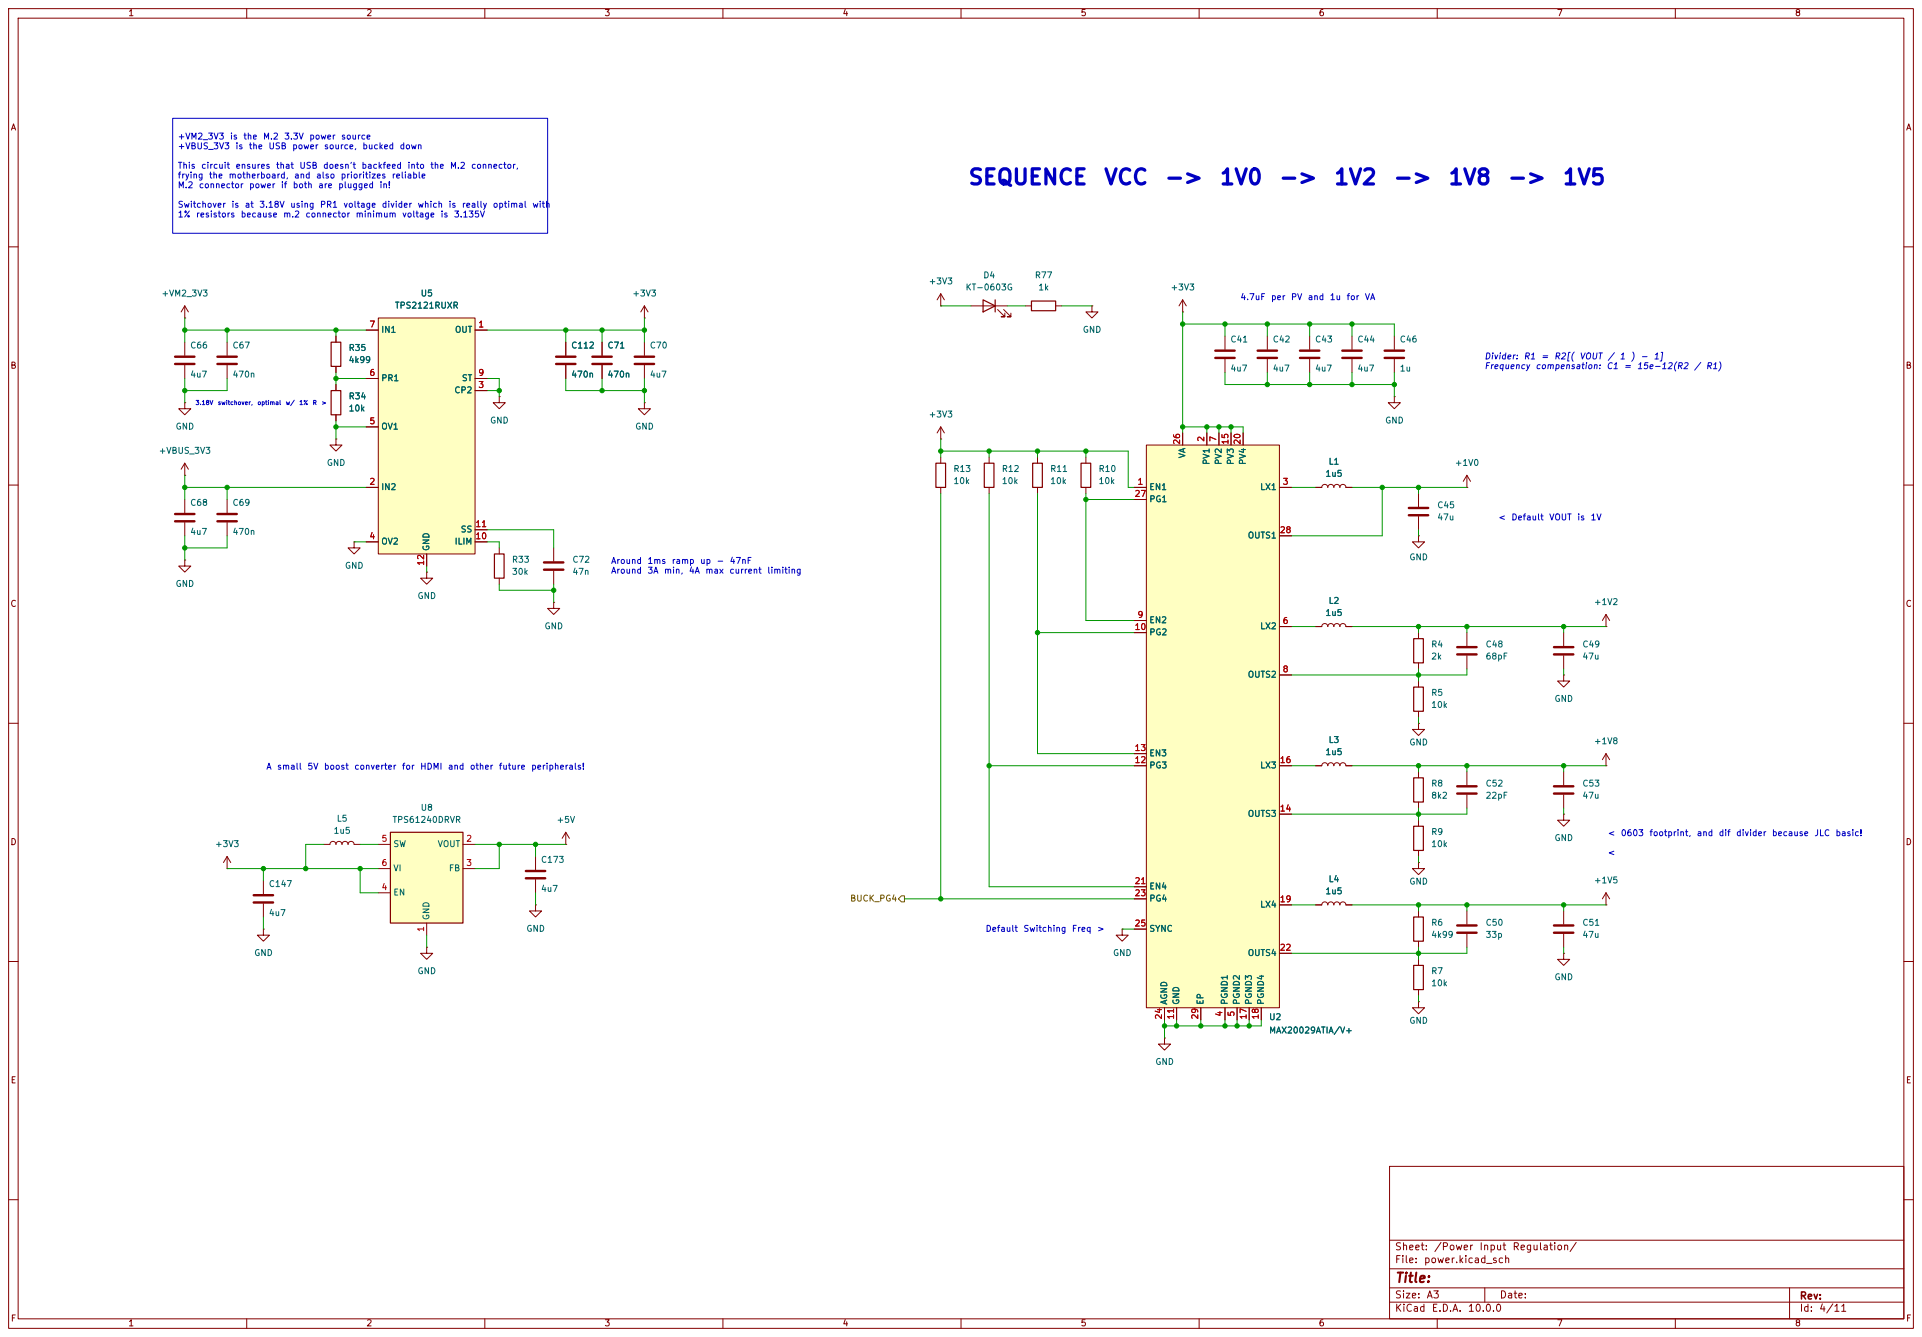
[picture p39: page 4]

+VM2_3V3 is the M.2 3.3V power source +VBUS_3V3 is the USB power source, bucked down

This circuit ensures that USB doesn't backfeed into the M.2 connector, frying the motherboard, and also prioritizes reliable M.2 connector power if both are plugged in! Switchover is at 3.18V using PR1 voltage divider which is really optimal with 1% resistors because m.2 connector minimum voltage is 3.135V

A small 5V boost converter for HDMI and other future peripherals!

Sheet: /Power Input Regulation/
File: power.kicad_sch

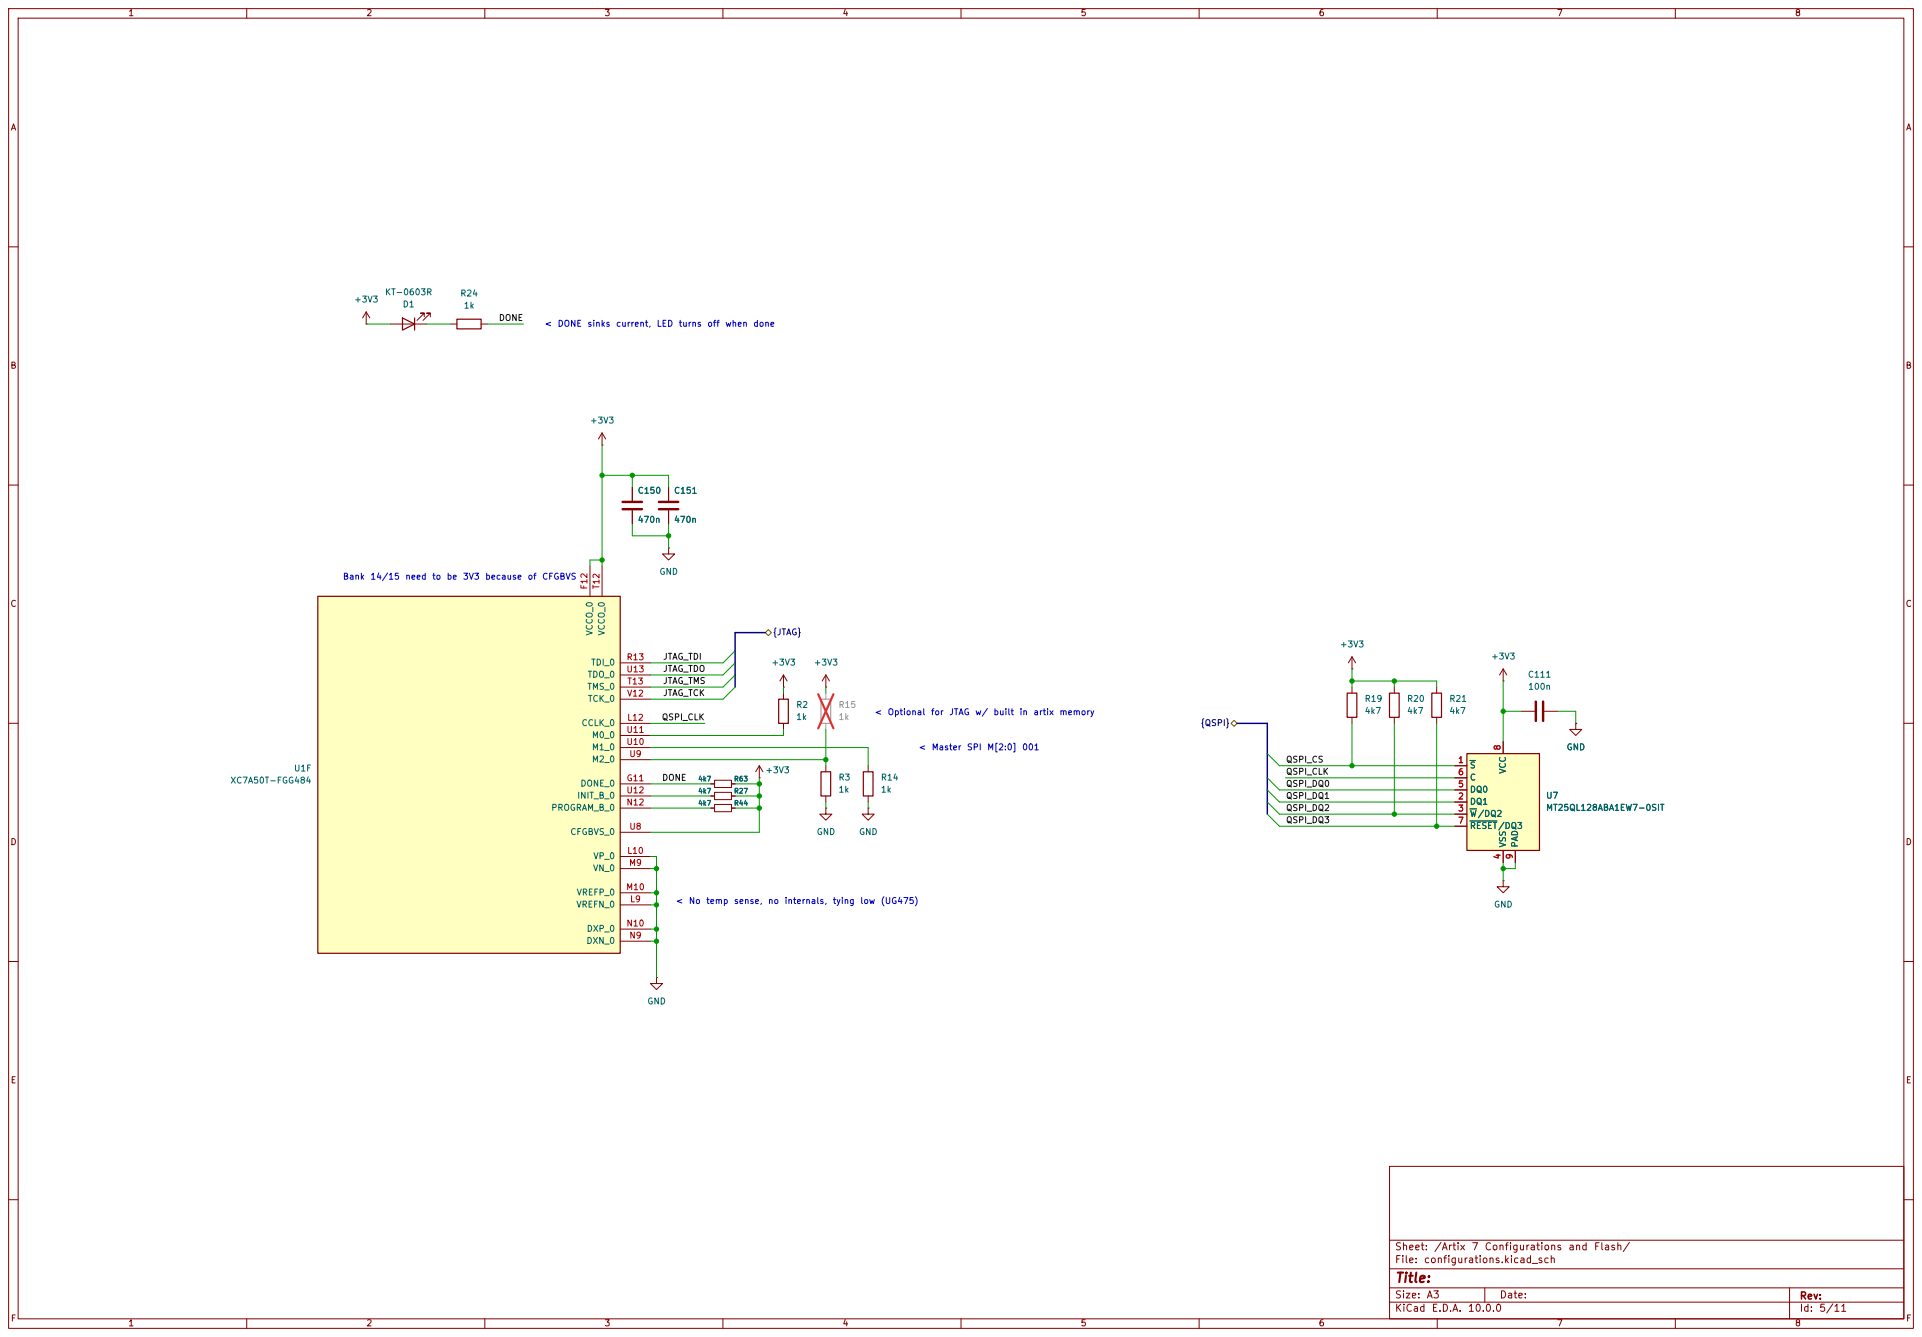
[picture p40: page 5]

Sheet: /Artix 7 Configurations and Flash/
File: configurations.kicad_sch

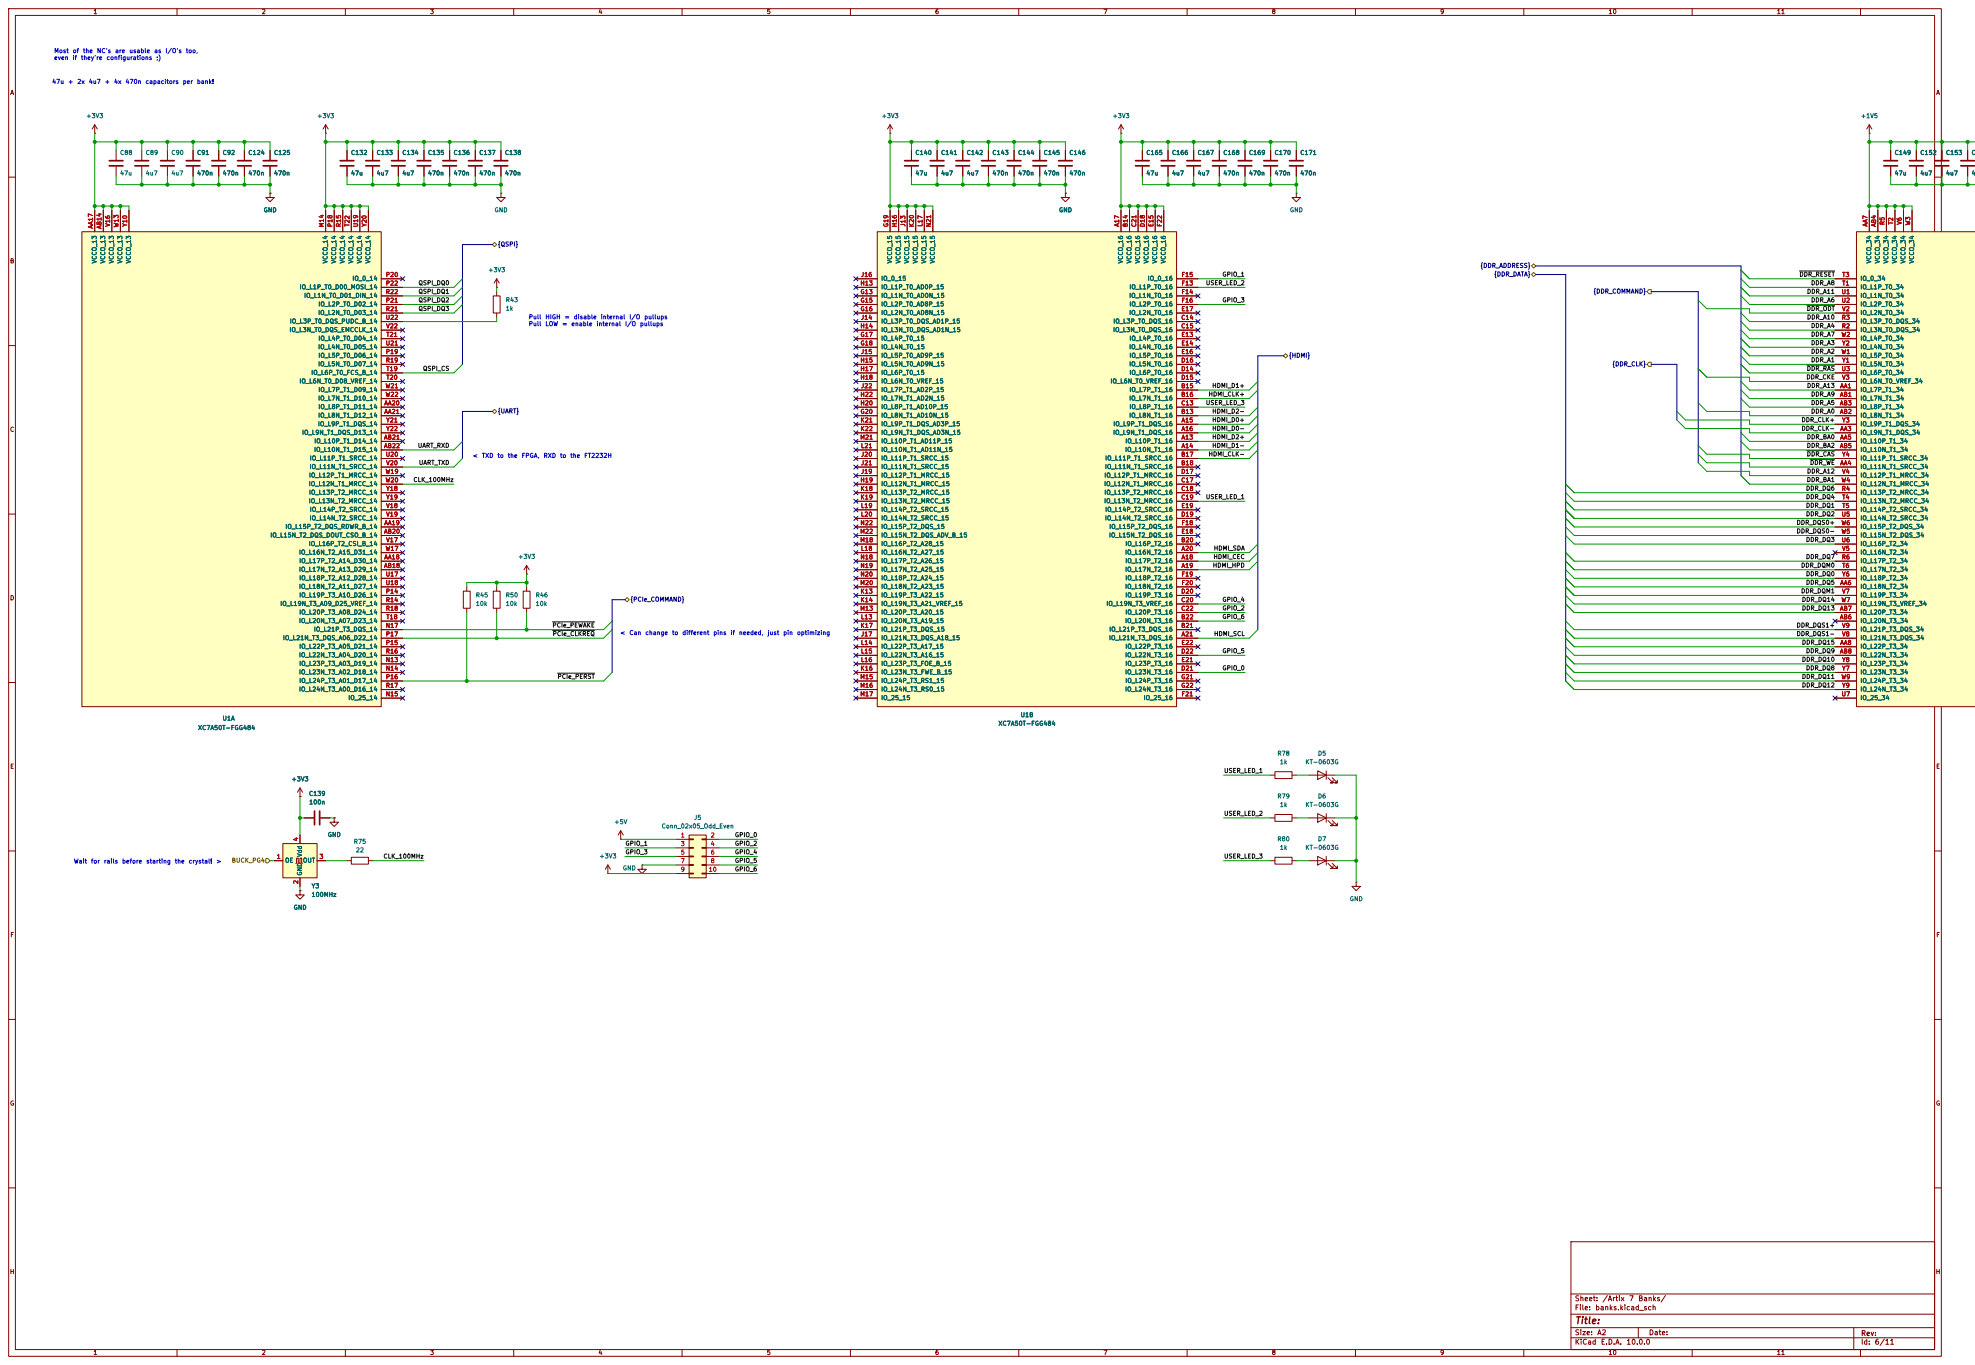
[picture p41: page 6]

Most of the NC's are usable as I/O's too, even if they're configurations ;)

Pull LOW = enable internal I/O pullups < TXD to the FPGA, RXD to the FT2232H

Pull HIGH = disable internal I/O pullups

< Can change to different pins if needed, just pin optimizing

Wait for rails before starting the crystal! >

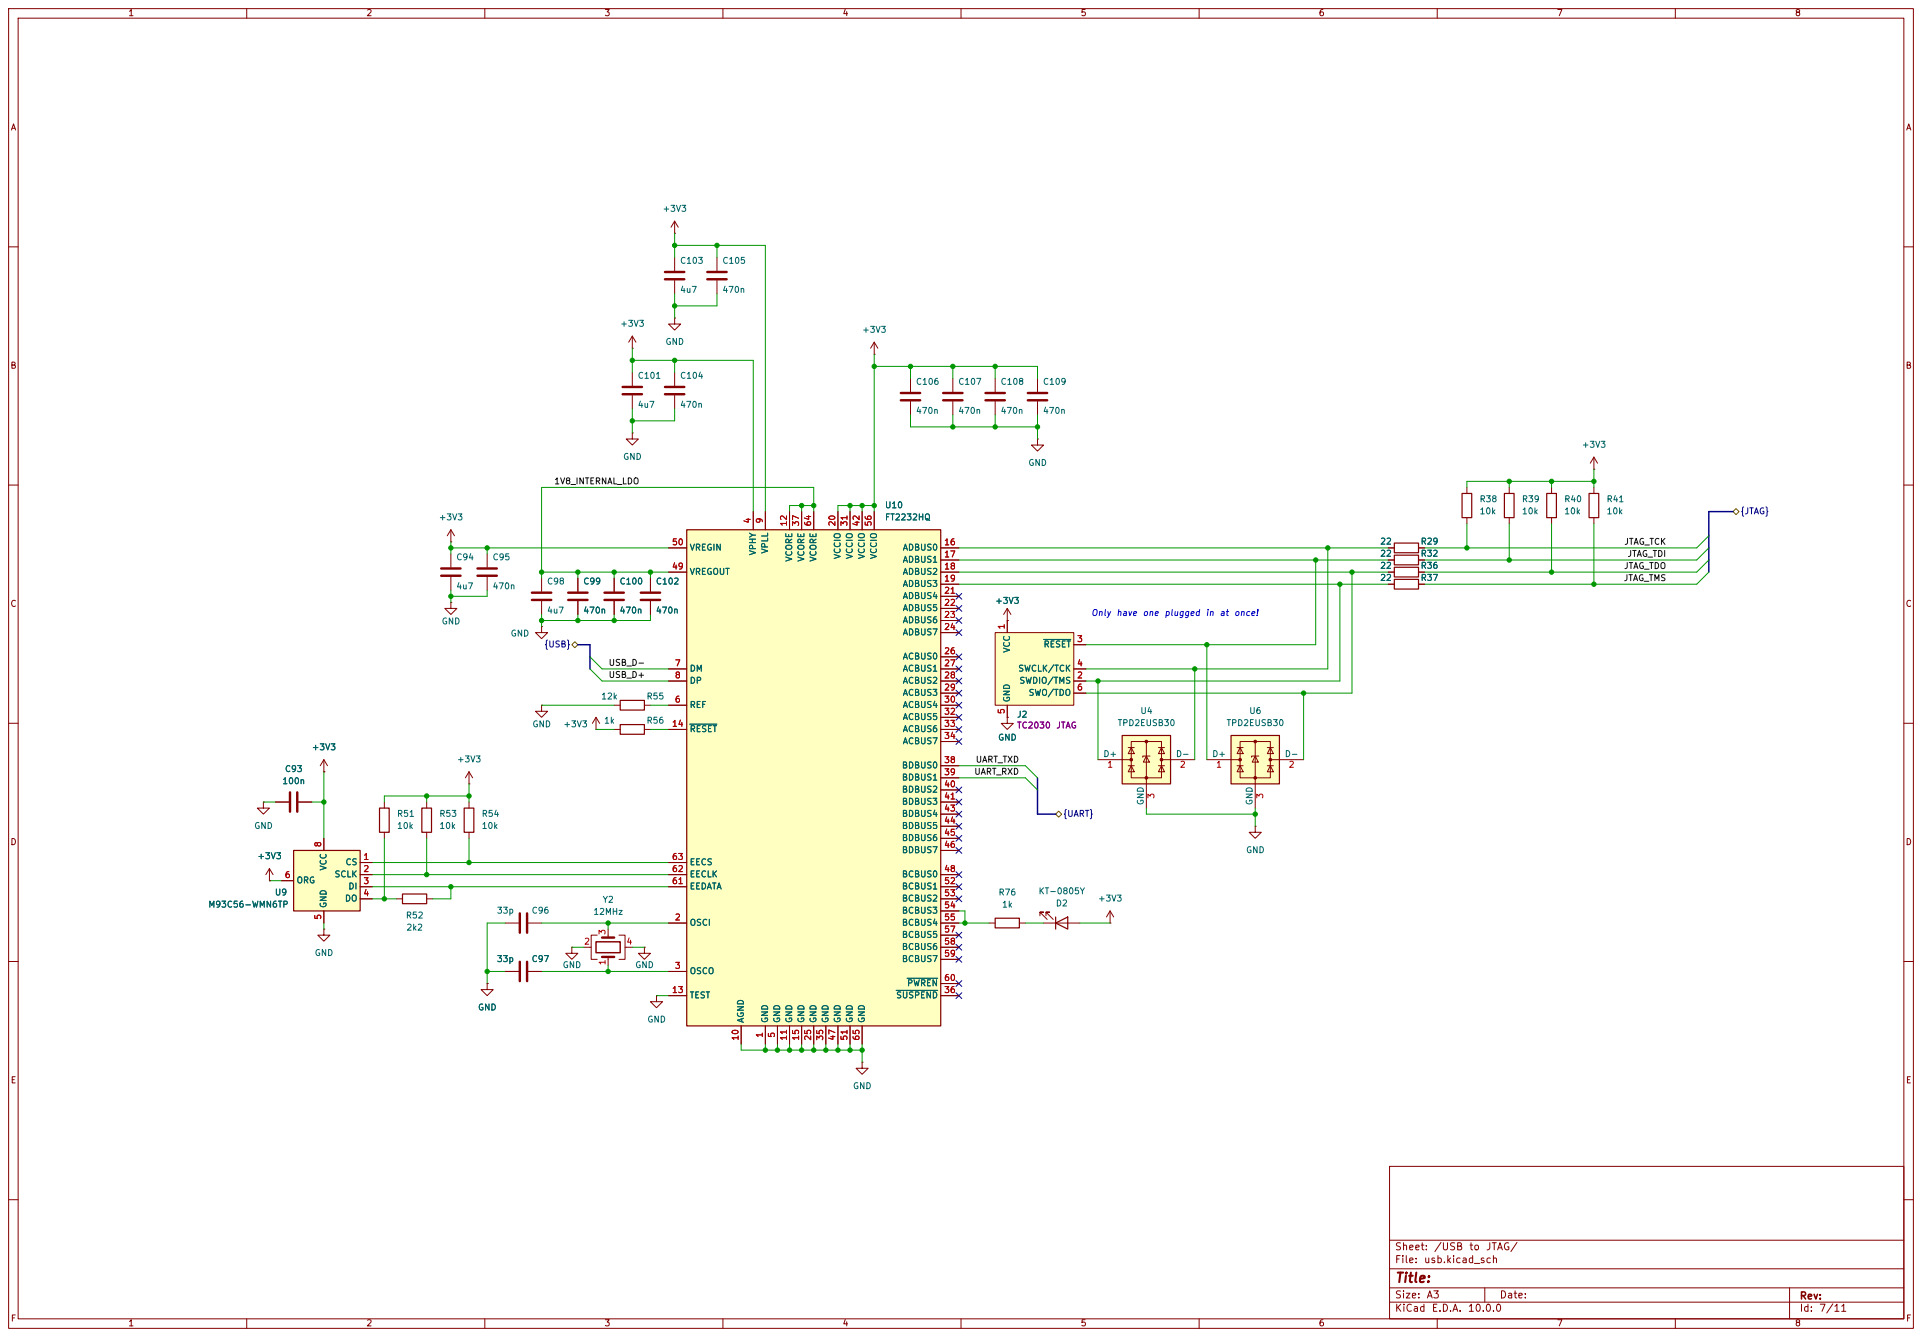
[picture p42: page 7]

Only have one plugged in at once! U10

5 REF 6 DM 7 DP 8 VPLL 9 AGND 10 GND 11 VCORE 12

1 OSCI 2 OSCO 3 VPHY 4 GND

Sheet: /USB to JTAG/
File: usb.kicad_sch

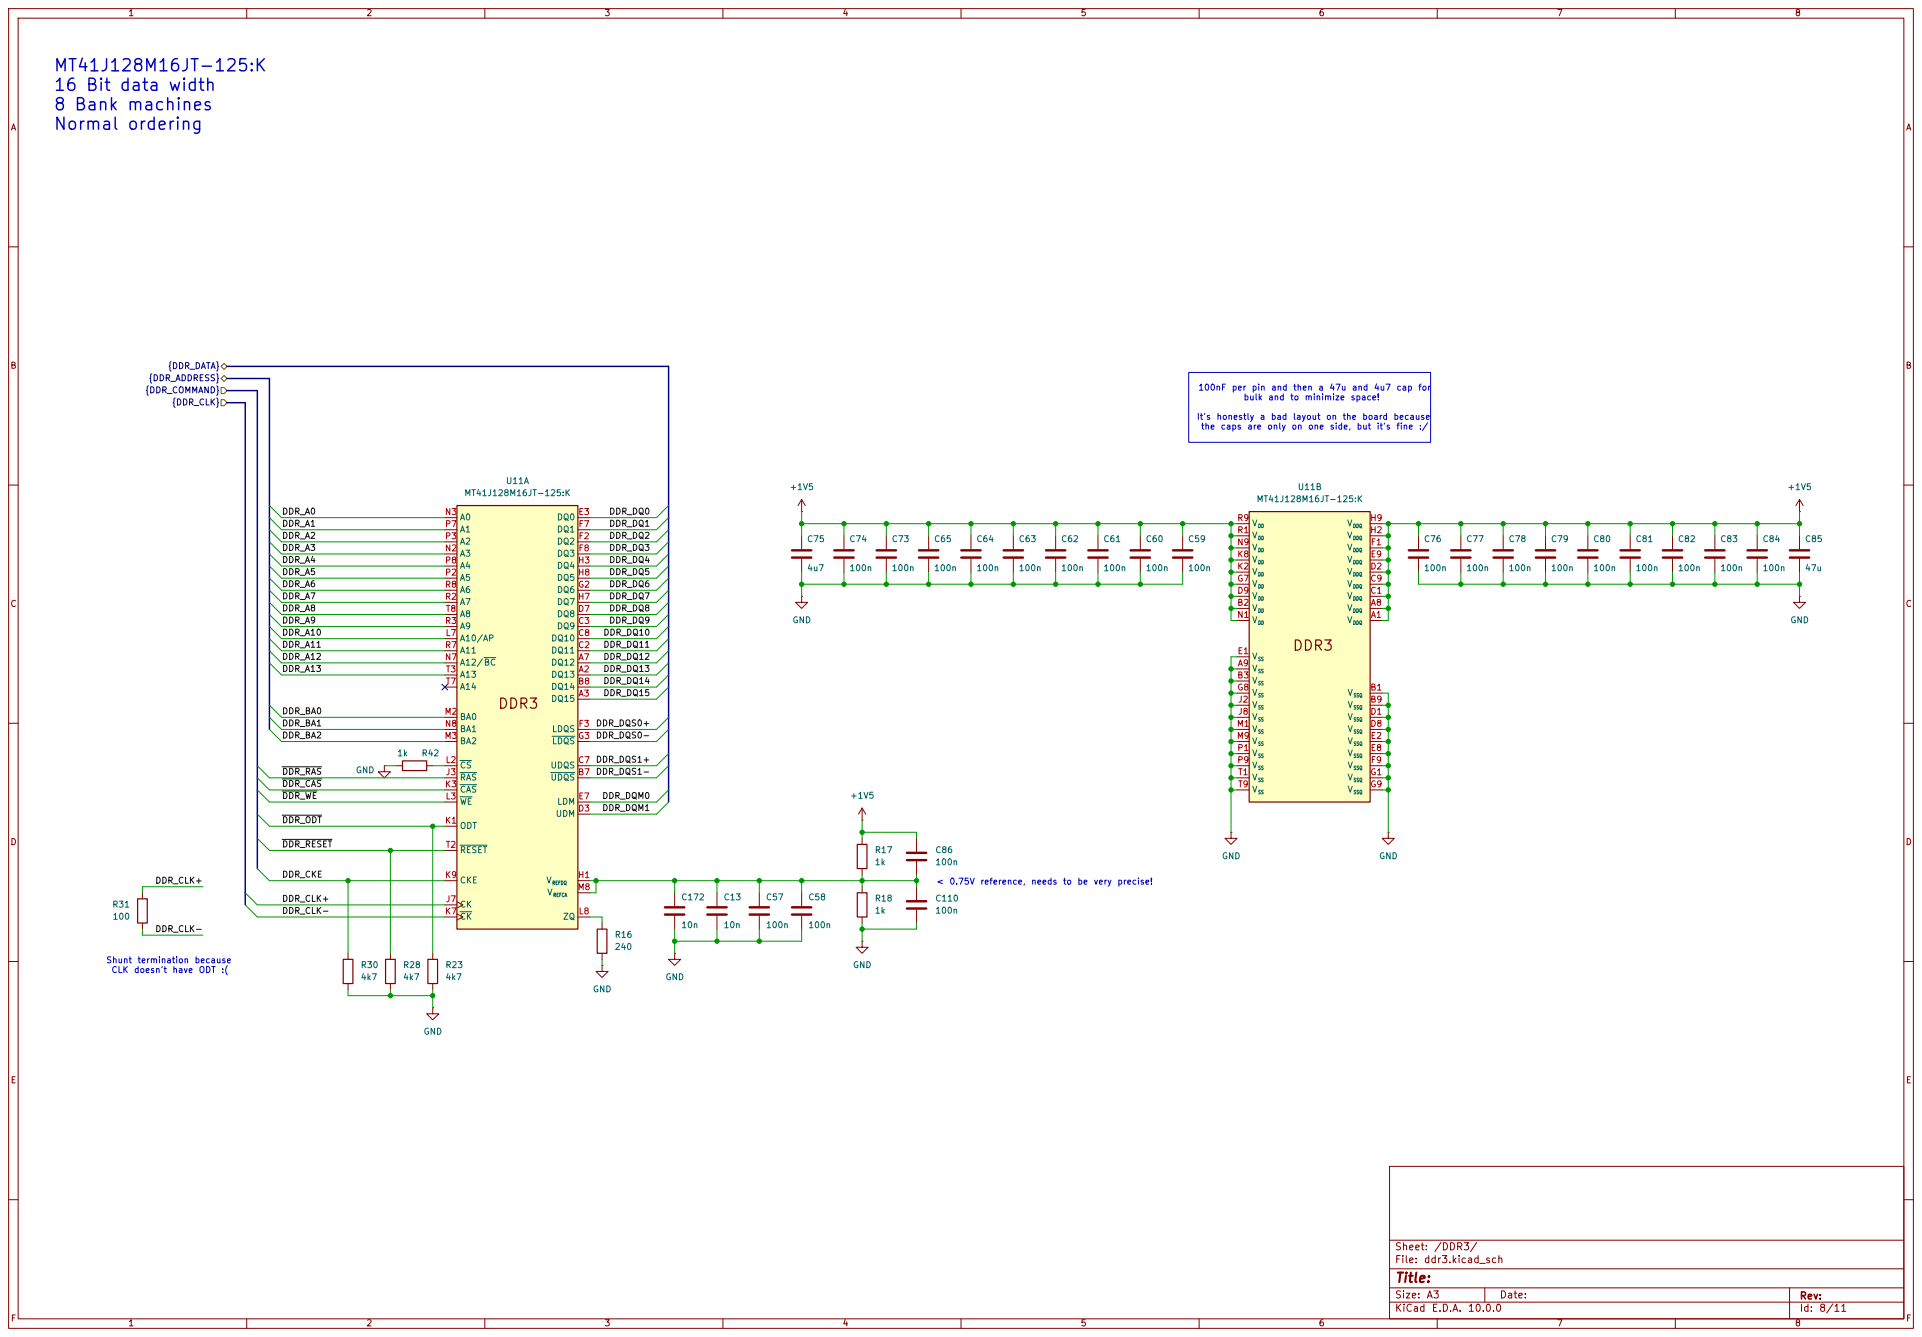
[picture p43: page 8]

100nF per pin and then a 47u and 4u7 cap for bulk and to minimize space!

It's honestly a bad layout on the board because
the caps are only on one side, but it's fine :/

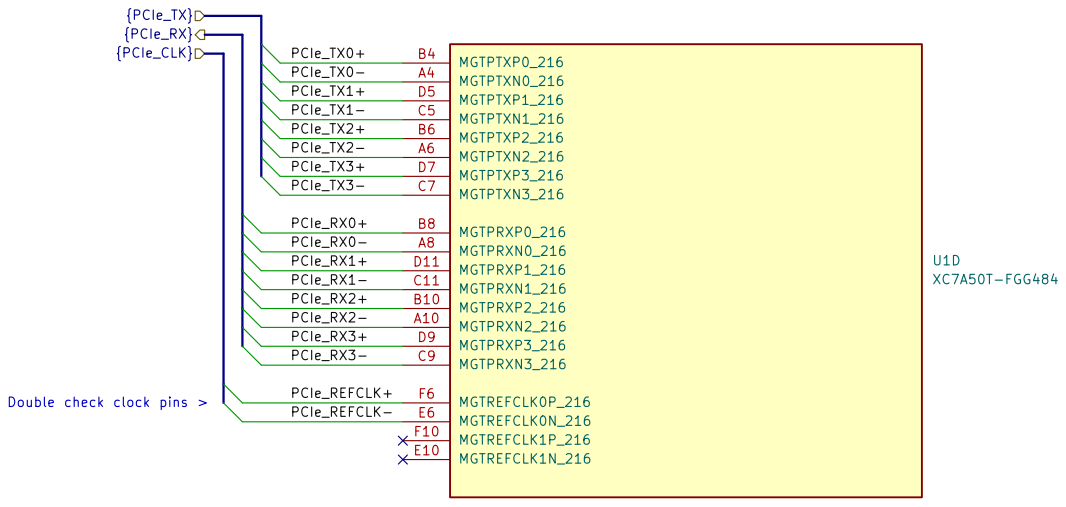
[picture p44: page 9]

Double check clock pins >

Sheet: /Artix 7 PCIe GTP Transceivers/
File: PCIe GTP Transceivers.kicad_sch
Title:

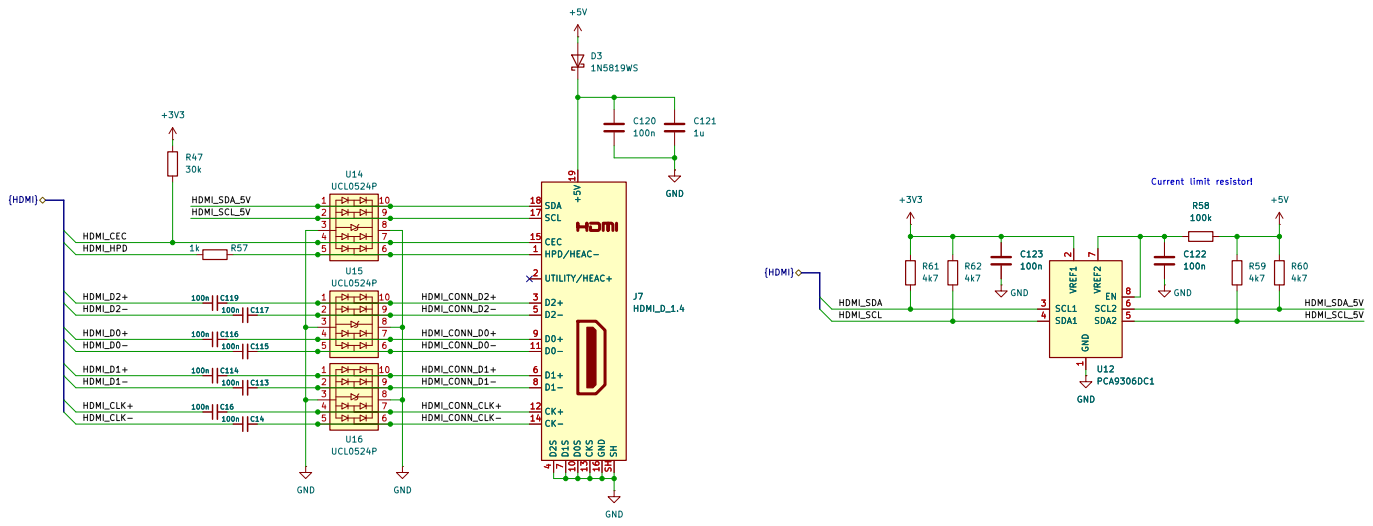
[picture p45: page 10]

7 D1- 8 D0+ 9 D0S 10 D0- 11 CK+ 12 CKS 13 CK- 14 CEC 15 GND 16

2 | | 9 | HDMI_CONN_D2-
3 | | 8 | HDMI_CONN_D0+

5 | | 6 | HDMI_CONN_D0-

3 | | 10 U16 UCL0524P 8 | HDMI_CONN_CLK+
2 | | 9 | HDMI_CONN_D1-

HDMI_CONN_D1+

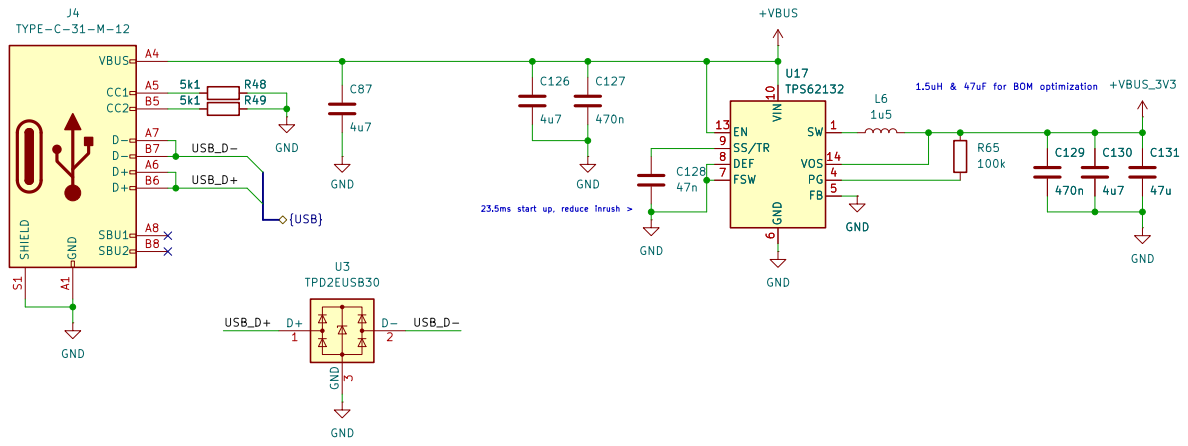
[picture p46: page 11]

23.5ms start up, reduce inrush >

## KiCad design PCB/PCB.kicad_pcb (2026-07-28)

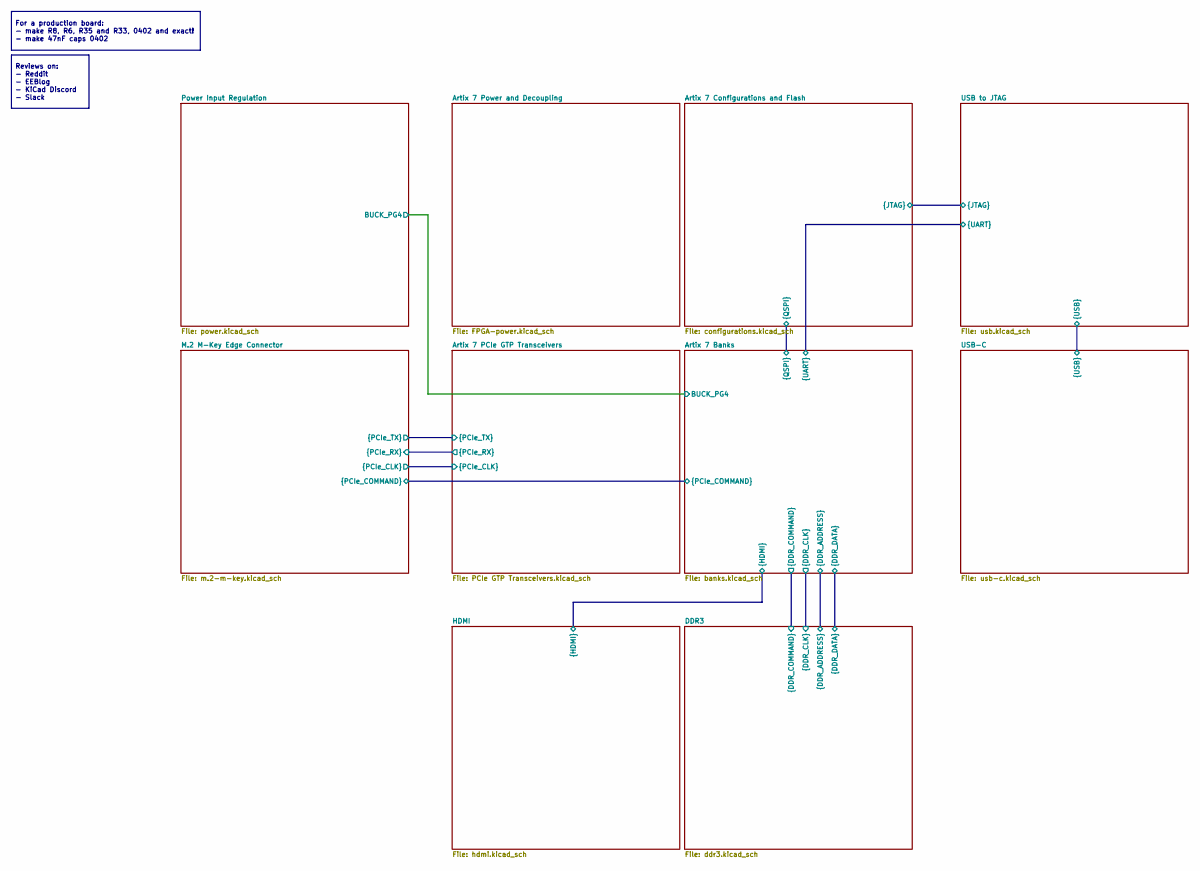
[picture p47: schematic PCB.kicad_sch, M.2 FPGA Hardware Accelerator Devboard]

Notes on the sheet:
For a production board: - make R8, R6, R35 and R33, 0402 and exact! - make 47nF caps 0402
Reviews on: - Reddit - EEBlog - KiCad Discord - Slack

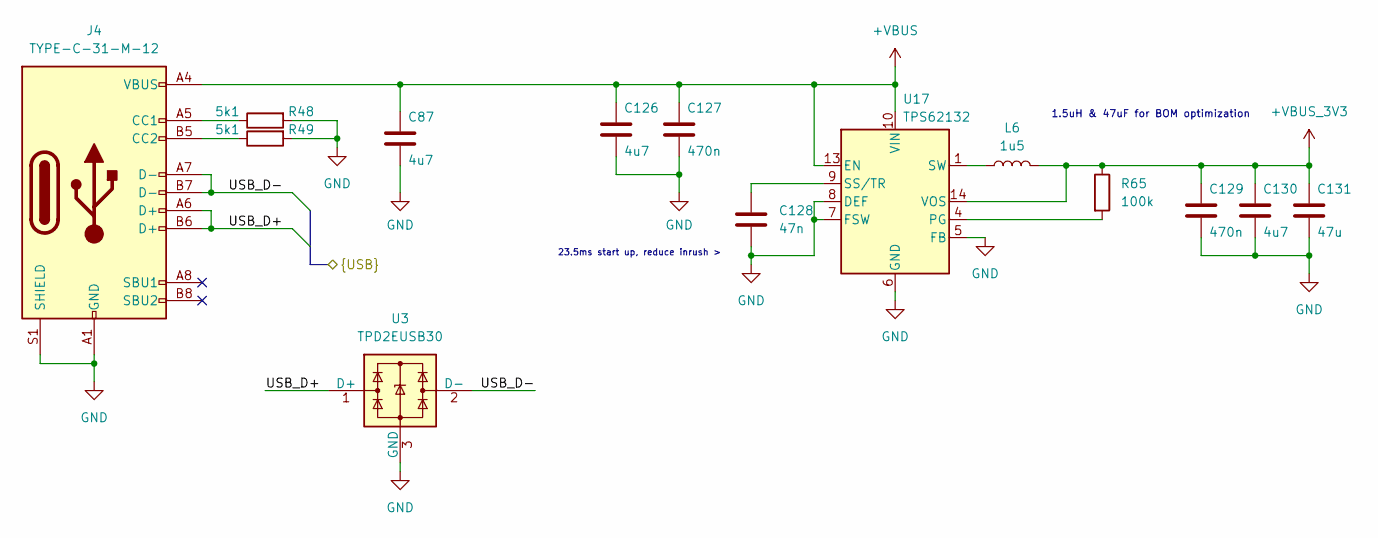
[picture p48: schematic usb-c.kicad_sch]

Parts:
C87, C126, C130: 4u7; C_0603_1608Metric
C127, C129: 470n; C_0201_0603Metric
C128: 47n; C_0603_1608Metric
C131: 47u; C_1206_3216Metric
J4: TYPE-C-31-M-12; USB_C_Receptacle_HRO_TYPE-C-31-M-12; MPN TYPE-C-31-M-12; LCSC C165948
L6: 1u5; L_Sunlord_SWPA4030S; MPN SWPA4030S1R5NT; LCSC C42100
R48, R49: 5k1; R_0402_1005Metric
R65: 100k; R_0402_1005Metric
U3: TPD2EUSB30; Texas_DRT-3
U17: TPS62132; VQFN-16-1EP_3x3mm_P0.5mm_EP1.68x1.68mm_ThermalVias

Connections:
+VBUS: C87.1, C126.1, C127.1, J4.A4 (VBUS), J4.A9 (VBUS), J4.B4 (VBUS), J4.B9 (VBUS), U17.10 (VIN), U17.11 (VIN), U17.12 (VIN), U17.13 (EN)
+VBUS_3V3: C129.1, C130.1, C131.1, L6.2, R65.1, U17.14 (VOS); also elsewhere on the board
/USB to JTAG/USB_D+: J4.A6 (D+), J4.B6 (D+), U3.1 (D+); also elsewhere on the board
/USB to JTAG/USB_D-: J4.A7 (D-), J4.B7 (D-), U3.2 (D-); also elsewhere on the board
GND: C87.2, C126.2, C127.2, C128.2, C129.2, C130.2, C131.2, J4.A1 (GND), J4.A12 (GND), J4.B1 (GND), J4.B12 (GND), J4.S1 (SHIELD), R48.2, R49.2, U3.3 (GND), U17.5 (FB), U17.6 (GND), U17.7 (FSW), U17.8 (DEF), U17.15 (GND), U17.16 (GND), U17.17 (GND); also elsewhere on the board
unnamed: J4.A5 (CC1), R48.1
unnamed: J4.B5 (CC2), R49.1
unnamed: L6.1, U17.1 (SW), U17.2 (SW), U17.3 (SW)
unnamed: R65.2, U17.4 (PG)
unnamed: C128.1, U17.9 (SS/TR)

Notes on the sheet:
23.5ms start up, reduce inrush >
1.5uH & 47uF for BOM optimization

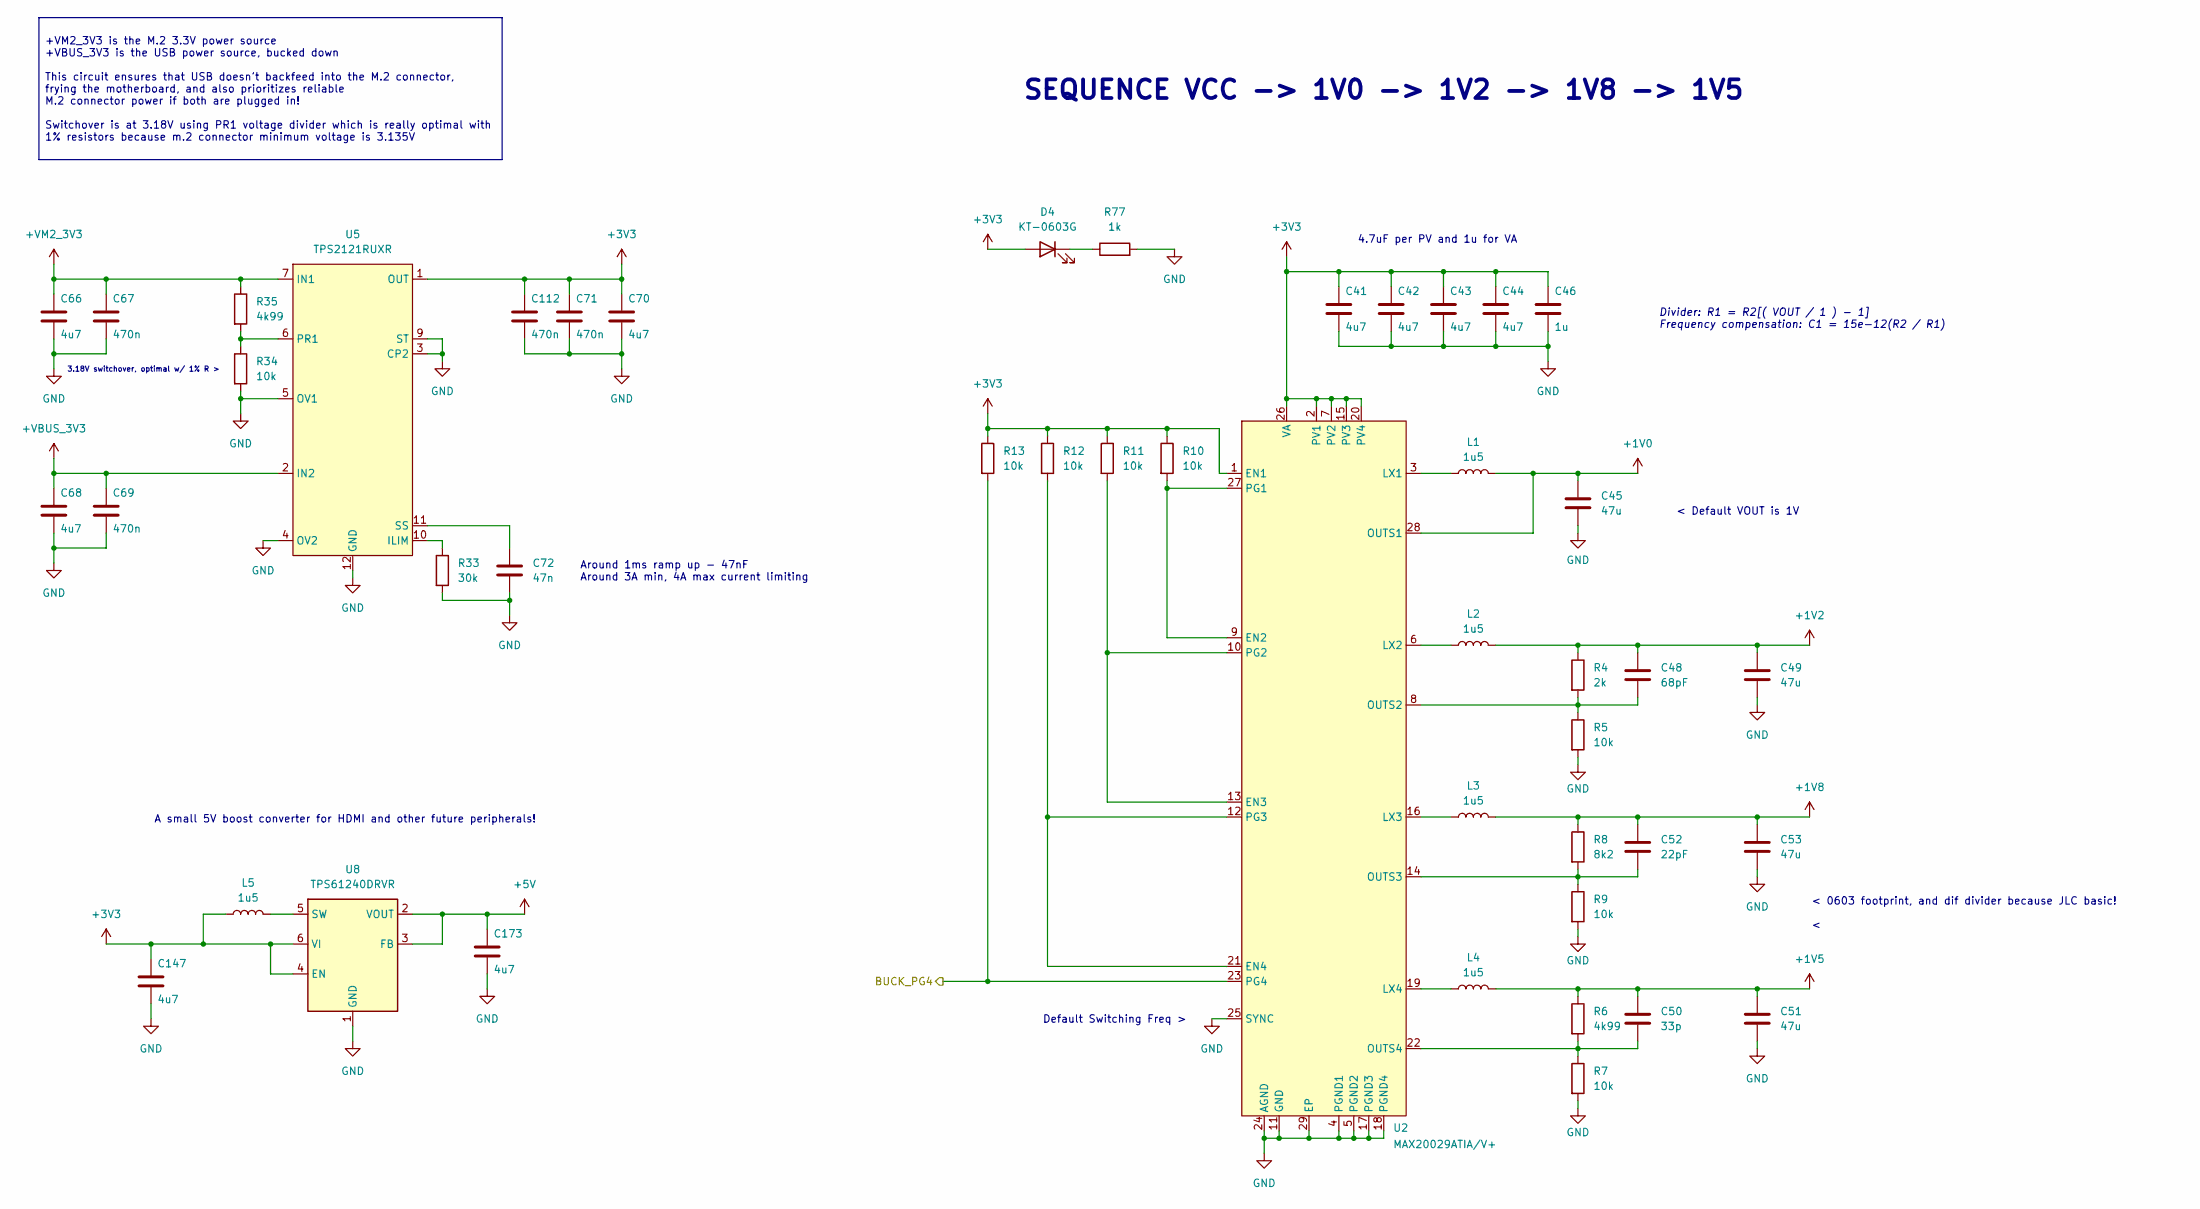
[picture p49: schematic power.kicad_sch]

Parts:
C41, C42, C43, C44, C66, C68, C70, C147, C173: 4u7; C_0603_1608Metric
C45, C49, C51, C53: 47u; C_1206_3216Metric
C46: 1u; C_0402_1005Metric
C48: 68pF; C_0402_1005Metric
C50: 33p; C_0402_1005Metric
C52: 22pF; C_0402_1005Metric
C67, C69, C71, C112: 470n; C_0201_0603Metric
C72: 47n; C_0603_1608Metric
D4: KT-0603G; LED_0603_1608Metric; MPN KT-0805G; LCSC C2297
L1, L2, L3, L4, L5: 1u5; L_Sunlord_SWPA4030S; MPN SWPA4030S1R5NT; LCSC C42100
R4: 2k; R_0402_1005Metric
R5, R7, R9, R10, R11, R12, R13, R34: 10k; R_0402_1005Metric
R6, R35: 4k99; R_0603_1608Metric
R8: 8k2; R_0603_1608Metric
R33: 30k; R_0603_1608Metric
R77: 1k; R_0402_1005Metric
U2: MAX20029ATIA/V+; QFN-28-1EP_5x5mm_P0.5mm_EP3.25x3.25mm_ThermalVias; LCSC Part C1235515
U5: TPS2121RUXR; Texas_VQFN-HR-12_2x2.5mm_P0.5mm_ThermalVias; MPN TPS2121RUXR; LCSC C485916
U8: TPS61240DRVR; WSON-6-1EP_2x2mm_P0.65mm_EP1x1.6mm

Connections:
+1V0: C45.1, L1.2, U2.28 (OUTS1); also elsewhere on the board
+1V2: C48.1, C49.1, L2.2, R4.1; also elsewhere on the board
+1V5: C50.1, C51.1, L4.2, R6.1; also elsewhere on the board
+1V8: C52.1, C53.1, L3.2, R8.1; also elsewhere on the board
+3V3: C41.1, C42.1, C43.1, C44.1, C46.1, C70.1, C71.1, C112.1, C147.1, D4.2 (A), L5.1, R10.1, R11.1, R12.1, R13.1, U2.1 (EN1), U2.2 (PV1), U2.7 (PV2), U2.15 (PV3), U2.20 (PV4), U2.26 (VA), U5.1 (OUT), U5.8 (OUT), U8.4 (EN), U8.6 (VI); also elsewhere on the board
+5V: C173.1, U8.2 (VOUT), U8.3 (FB); also elsewhere on the board
+VBUS_3V3: C68.1, C69.1, U5.2 (IN2); also elsewhere on the board
+VM2_3V3: C66.1, C67.1, R35.1, U5.7 (IN1); also elsewhere on the board
/Artix 7 Banks/BUCK_PG4: R13.2, U2.23 (PG4); also elsewhere on the board
GND: C41.2, C42.2, C43.2, C44.2, C45.2, C46.2, C49.2, C51.2, C53.2, C66.2, C67.2, C68.2, C69.2, C70.2, C71.2, C72.2, C112.2, C147.2, C173.2, R5.2, R7.2, R9.2, R33.2, R34.2, R77.2, U2.4 (PGND1), U2.5 (PGND2), U2.11 (GND), U2.17 (PGND3), U2.18 (PGND4), U2.24 (AGND), U2.25 (SYNC), U2.29 (EP), U5.3 (CP2), U5.4 (OV2), U5.5 (OV1), U5.9 (ST), U5.12 (GND), U8.1 (GND), U8.7 (GND); also elsewhere on the board
unnamed: D4.1 (K), R77.1
unnamed: R10.2, U2.9 (EN2), U2.27 (PG1)
unnamed: R11.2, U2.10 (PG2), U2.13 (EN3)
unnamed: R12.2, U2.12 (PG3), U2.21 (EN4)
unnamed: L1.1, U2.3 (LX1)
unnamed: L2.1, U2.6 (LX2)
unnamed: L3.1, U2.16 (LX3)
unnamed: L4.1, U2.19 (LX4)
unnamed: C48.2, R4.2, R5.1, U2.8 (OUTS2)
unnamed: C52.2, R8.2, R9.1, U2.14 (OUTS3)
unnamed: C50.2, R6.2, R7.1, U2.22 (OUTS4)
unnamed: R33.1, U5.10 (ILIM)
unnamed: R34.1, R35.2, U5.6 (PR1)
unnamed: C72.1, U5.11 (SS)
unnamed: L5.2, U8.5 (SW)

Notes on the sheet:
Default Switching Freq >
Divider: R1 = R2[( VOUT / 1 ) − 1] Frequency compensation: C1 = 15e-12(R2 / R1)
4.7uF per PV and 1u for VA
< 0603 footprint, and dif divider because JLC basic! <
Around 1ms ramp up - 47nF Around 3A min, 4A max current limiting
A small 5V boost converter for HDMI and other future peripherals!
SEQUENCE VCC -> 1V0 -> 1V2 -> 1V8 -> 1V5
< Default VOUT is 1V
3.18V switchover, optimal w/ 1% R >
+VM2_3V3 is the M.2 3.3V power source +VBUS_3V3 is the USB power source, bucked down This circuit ensures that USB doesn't backfeed into the M.2 connector, frying the motherboard, and also prioritizes reliable M.2 connector power if both are plugged in! Switchover is at 3.18V using PR1 voltage divi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

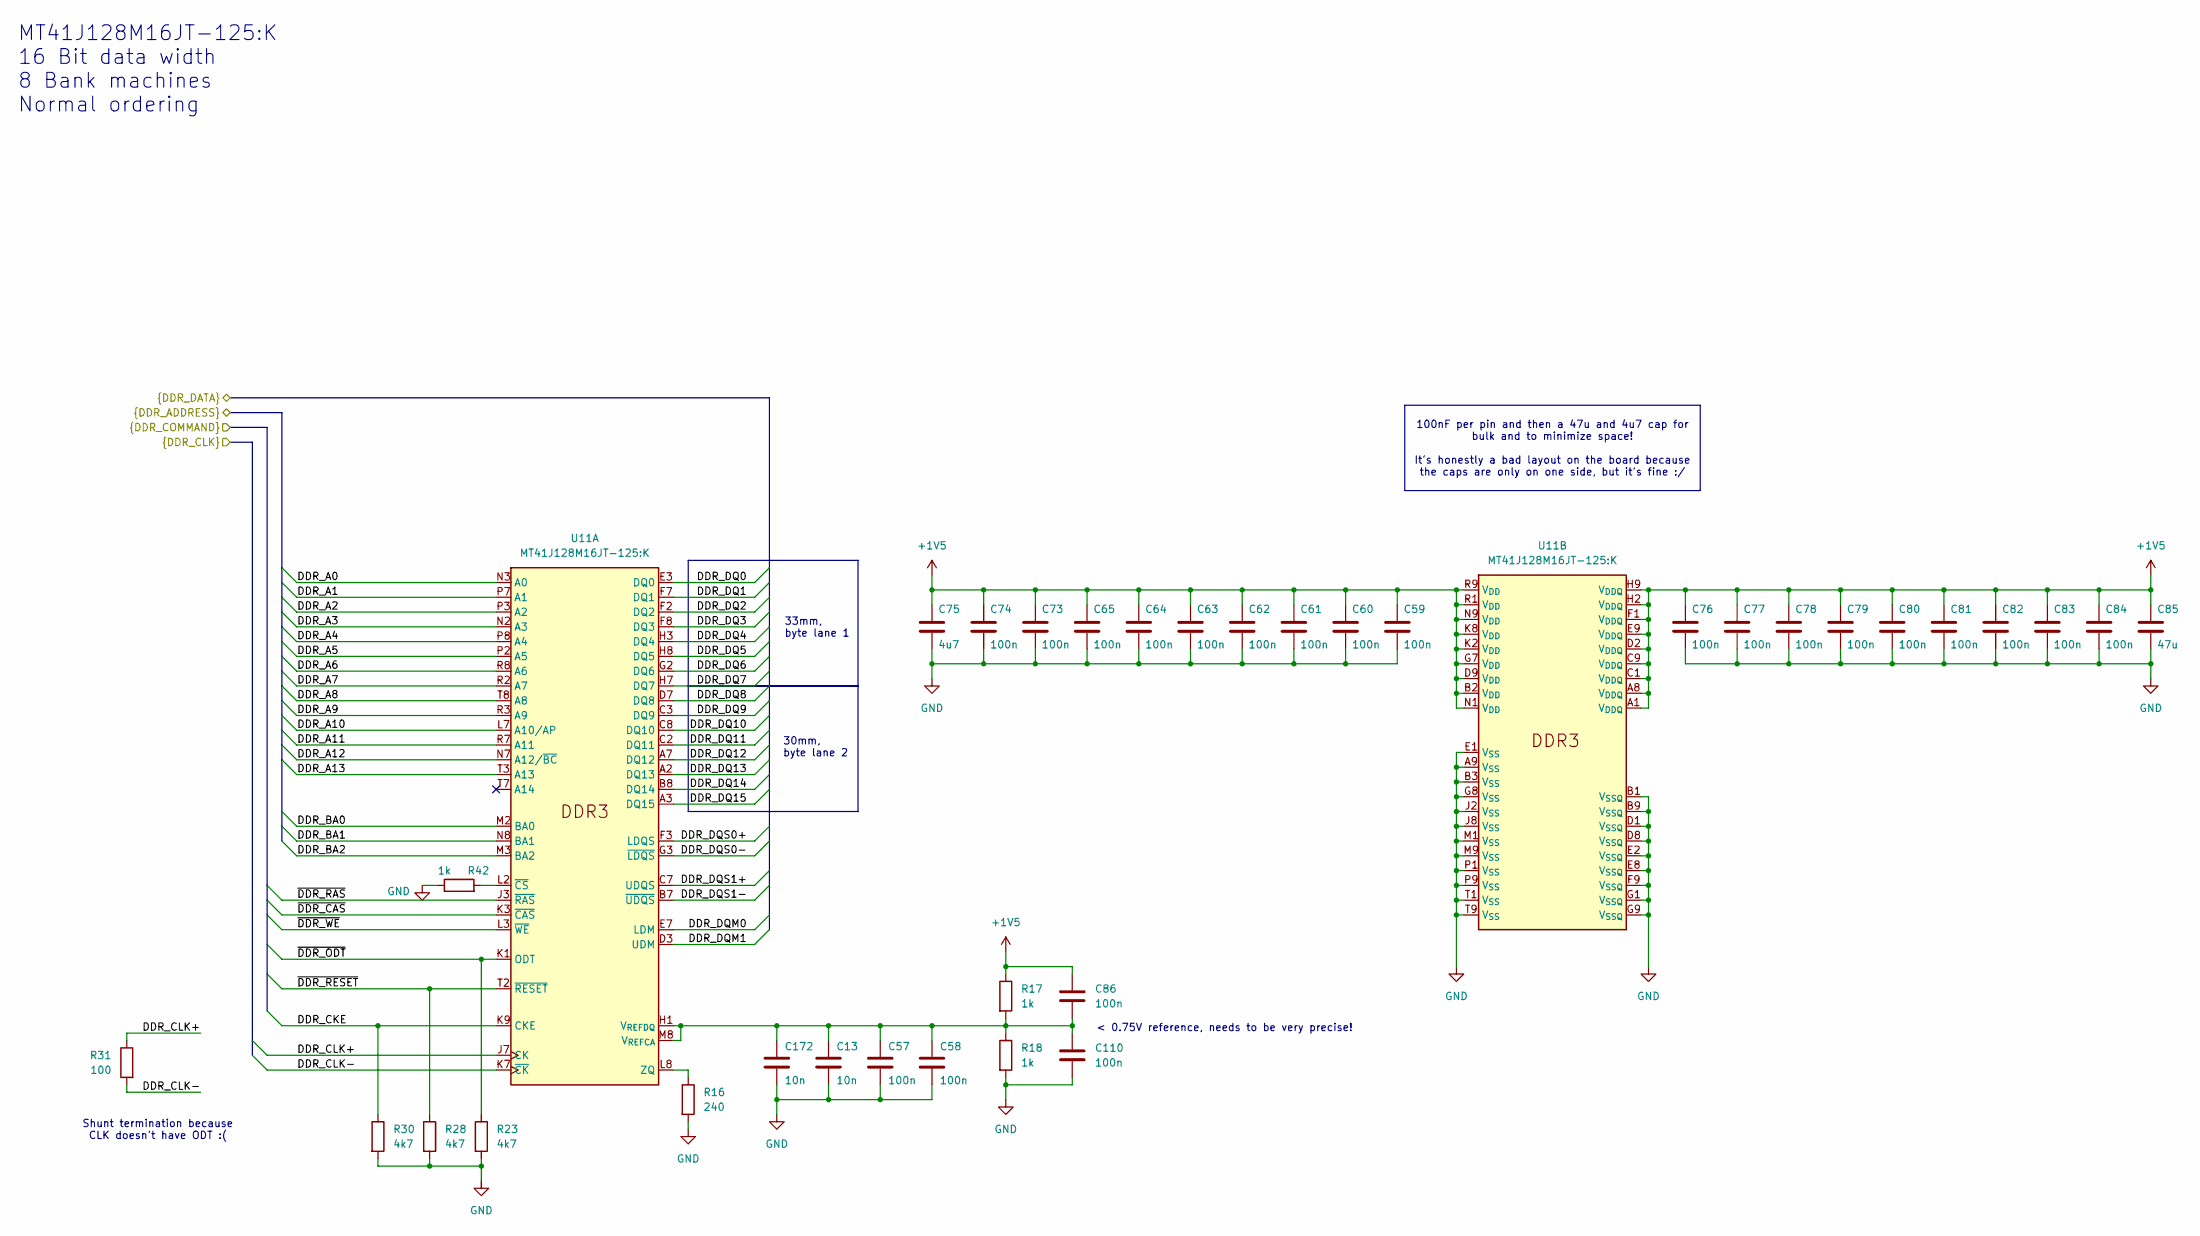
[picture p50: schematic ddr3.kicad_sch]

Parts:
C13, C172: 10n; C_0402_1005Metric
C57, C58, C59, C60, C61, C62, C63, C64, C65, C73, C74, C76, C77, C78, C79, C80, C81, C82, C83, C84, C86, C110: 100n; C_0402_1005Metric
C75: 4u7; C_0603_1608Metric
C85: 47u; C_1206_3216Metric
R16: 240; R_0402_1005Metric
R17, R18, R42: 1k; R_0402_1005Metric
R23, R28, R30: 4k7; R_0402_1005Metric
R31: 100; R_0402_1005Metric
U11: MT41J128M16JT-125:K; FBGA-96_8x14mm_Layout9x16_P0.8mm; MPN MT41J128M16JT-125:K; LCSC C426885

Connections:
+1V5: C59.1, C60.1, C61.1, C62.1, C63.1, C64.1, C65.1, C73.1, C74.1, C75.1, C76.1, C77.1, C78.1, C79.1, C80.1, C81.1, C82.1, C83.1, C84.1, C85.1, C86.1, R17.1, U11.A1 (V_{DDQ}), U11.A8 (V_{DDQ}), U11.B2 (V_{DD}), U11.C1 (V_{DDQ}), U11.C9 (V_{DDQ}), U11.D2 (V_{DDQ}), U11.D9 (V_{DD}), U11.E9 (V_{DDQ}), U11.F1 (V_{DDQ}), U11.G7 (V_{DD}), U11.H2 (V_{DDQ}), U11.H9 (V_{DDQ}), U11.K2 (V_{DD}), U11.K8 (V_{DD}), U11.N1 (V_{DD}), U11.N9 (V_{DD}), U11.R1 (V_{DD}), U11.R9 (V_{DD}); also elsewhere on the board
/Artix 7 Banks/DDR_A0: U11.N3 (A0); also elsewhere on the board
/Artix 7 Banks/DDR_A1: U11.P7 (A1); also elsewhere on the board
/Artix 7 Banks/DDR_A2: U11.P3 (A2); also elsewhere on the board
/Artix 7 Banks/DDR_A3: U11.N2 (A3); also elsewhere on the board
/Artix 7 Banks/DDR_A4: U11.P8 (A4); also elsewhere on the board
/Artix 7 Banks/DDR_A5: U11.P2 (A5); also elsewhere on the board
/Artix 7 Banks/DDR_A6: U11.R8 (A6); also elsewhere on the board
/Artix 7 Banks/DDR_A7: U11.R2 (A7); also elsewhere on the board
/Artix 7 Banks/DDR_A8: U11.T8 (A8); also elsewhere on the board
/Artix 7 Banks/DDR_A9: U11.R3 (A9); also elsewhere on the board
/Artix 7 Banks/DDR_A10: U11.L7 (A10/AP); also elsewhere on the board
/Artix 7 Banks/DDR_A11: U11.R7 (A11); also elsewhere on the board
/Artix 7 Banks/DDR_A12: U11.N7 (A12/~BC); also elsewhere on the board
/Artix 7 Banks/DDR_A13: U11.T3 (A13); also elsewhere on the board
/Artix 7 Banks/DDR_BA0: U11.M2 (BA0); also elsewhere on the board
/Artix 7 Banks/DDR_BA1: U11.N8 (BA1); also elsewhere on the board
/Artix 7 Banks/DDR_BA2: U11.M3 (BA2); also elsewhere on the board
/Artix 7 Banks/DDR_CKE: R30.1, U11.K9 (CKE); also elsewhere on the board
/Artix 7 Banks/DDR_CLK+: R31.1, U11.J7 (CK); also elsewhere on the board
/Artix 7 Banks/DDR_CLK-: R31.2, U11.K7 (~CK); also elsewhere on the board
/Artix 7 Banks/DDR_DQ0: U11.E3 (DQ0); also elsewhere on the board
/Artix 7 Banks/DDR_DQ1: U11.F7 (DQ1); also elsewhere on the board
/Artix 7 Banks/DDR_DQ2: U11.F2 (DQ2); also elsewhere on the board
/Artix 7 Banks/DDR_DQ3: U11.F8 (DQ3); also elsewhere on the board
/Artix 7 Banks/DDR_DQ4: U11.H3 (DQ4); also elsewhere on the board
/Artix 7 Banks/DDR_DQ5: U11.H8 (DQ5); also elsewhere on the board
/Artix 7 Banks/DDR_DQ6: U11.G2 (DQ6); also elsewhere on the board
/Artix 7 Banks/DDR_DQ7: U11.H7 (DQ7); also elsewhere on the board
/Artix 7 Banks/DDR_DQ8: U11.D7 (DQ8); also elsewhere on the board
/Artix 7 Banks/DDR_DQ9: U11.C3 (DQ9); also elsewhere on the board
/Artix 7 Banks/DDR_DQ10: U11.C8 (DQ10); also elsewhere on the board
/Artix 7 Banks/DDR_DQ11: U11.C2 (DQ11); also elsewhere on the board
/Artix 7 Banks/DDR_DQ12: U11.A7 (DQ12); also elsewhere on the board
/Artix 7 Banks/DDR_DQ13: U11.A2 (DQ13); also elsewhere on the board
/Artix 7 Banks/DDR_DQ14: U11.B8 (DQ14); also elsewhere on the board
/Artix 7 Banks/DDR_DQ15: U11.A3 (DQ15); also elsewhere on the board
/Artix 7 Banks/DDR_DQM0: U11.E7 (LDM); also elsewhere on the board
/Artix 7 Banks/DDR_DQM1: U11.D3 (UDM); also elsewhere on the board
/Artix 7 Banks/DDR_DQS0+: U11.F3 (LDQS); also elsewhere on the board
/Artix 7 Banks/DDR_DQS0-: U11.G3 (~LDQS); also elsewhere on the board
/Artix 7 Banks/DDR_DQS1+: U11.C7 (UDQS); also elsewhere on the board
/Artix 7 Banks/DDR_DQS1-: U11.B7 (~UDQS); also elsewhere on the board
/Artix 7 Banks/~DDR_CAS: U11.K3 (~CAS); also elsewhere on the board
/Artix 7 Banks/~DDR_ODT: R23.1, U11.K1 (ODT); also elsewhere on the board
/Artix 7 Banks/~DDR_RAS: U11.J3 (~RAS); also elsewhere on the board
/Artix 7 Banks/~DDR_RESET: R28.1, U11.T2 (~RESET); also elsewhere on the board
/Artix 7 Banks/~DDR_WE: U11.L3 (~WE); also elsewhere on the board
GND: C13.2, C57.2, C58.2, C59.2, C60.2, C61.2, C62.2, C63.2, C64.2, C65.2, C73.2, C74.2, C75.2, C76.2, C77.2, C78.2, C79.2, C80.2, C81.2, C82.2, C83.2, C84.2, C85.2, C110.2, C172.2, R16.2, R18.2, R23.2, R28.2, R30.2, R42.1, U11.A9 (V_{SS}), U11.B1 (V_{SSQ}), U11.B3 (V_{SS}), U11.B9 (V_{SSQ}), U11.D1 (V_{SSQ}), U11.D8 (V_{SSQ}), U11.E1 (V_{SS}), U11.E2 (V_{SSQ}), U11.E8 (V_{SSQ}), U11.F9 (V_{SSQ}), U11.G1 (V_{SSQ}), U11.G8 (V_{SS}), U11.G9 (V_{SSQ}), U11.J2 (V_{SS}), U11.J8 (V_{SS}), U11.M1 (V_{SS}), U11.M9 (V_{SS}), U11.P1 (V_{SS}), U11.P9 (V_{SS}), U11.T1 (V_{SS}), U11.T9 (V_{SS}); also elsewhere on the board
unnamed: C13.1, C57.1, C58.1, C86.2, C110.1, C172.1, R17.2, R18.1, U11.H1 (V_{REFDQ}), U11.M8 (V_{REFCA})
unnamed: R16.1, U11.L8 (ZQ)
unnamed: R42.2, U11.L2 (~CS)

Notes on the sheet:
MT41J128M16JT-125:K 16 Bit data width 8 Bank machines Normal ordering
< 0.75V reference, needs to be very precise!
33mm, byte lane 1
Shunt termination because CLK doesn't have ODT :(
30mm, byte lane 2
100nF per pin and then a 47u and 4u7 cap for bulk and to minimize space! It's honestly a bad layout on the board because the caps are only on one side, but it's fine :/

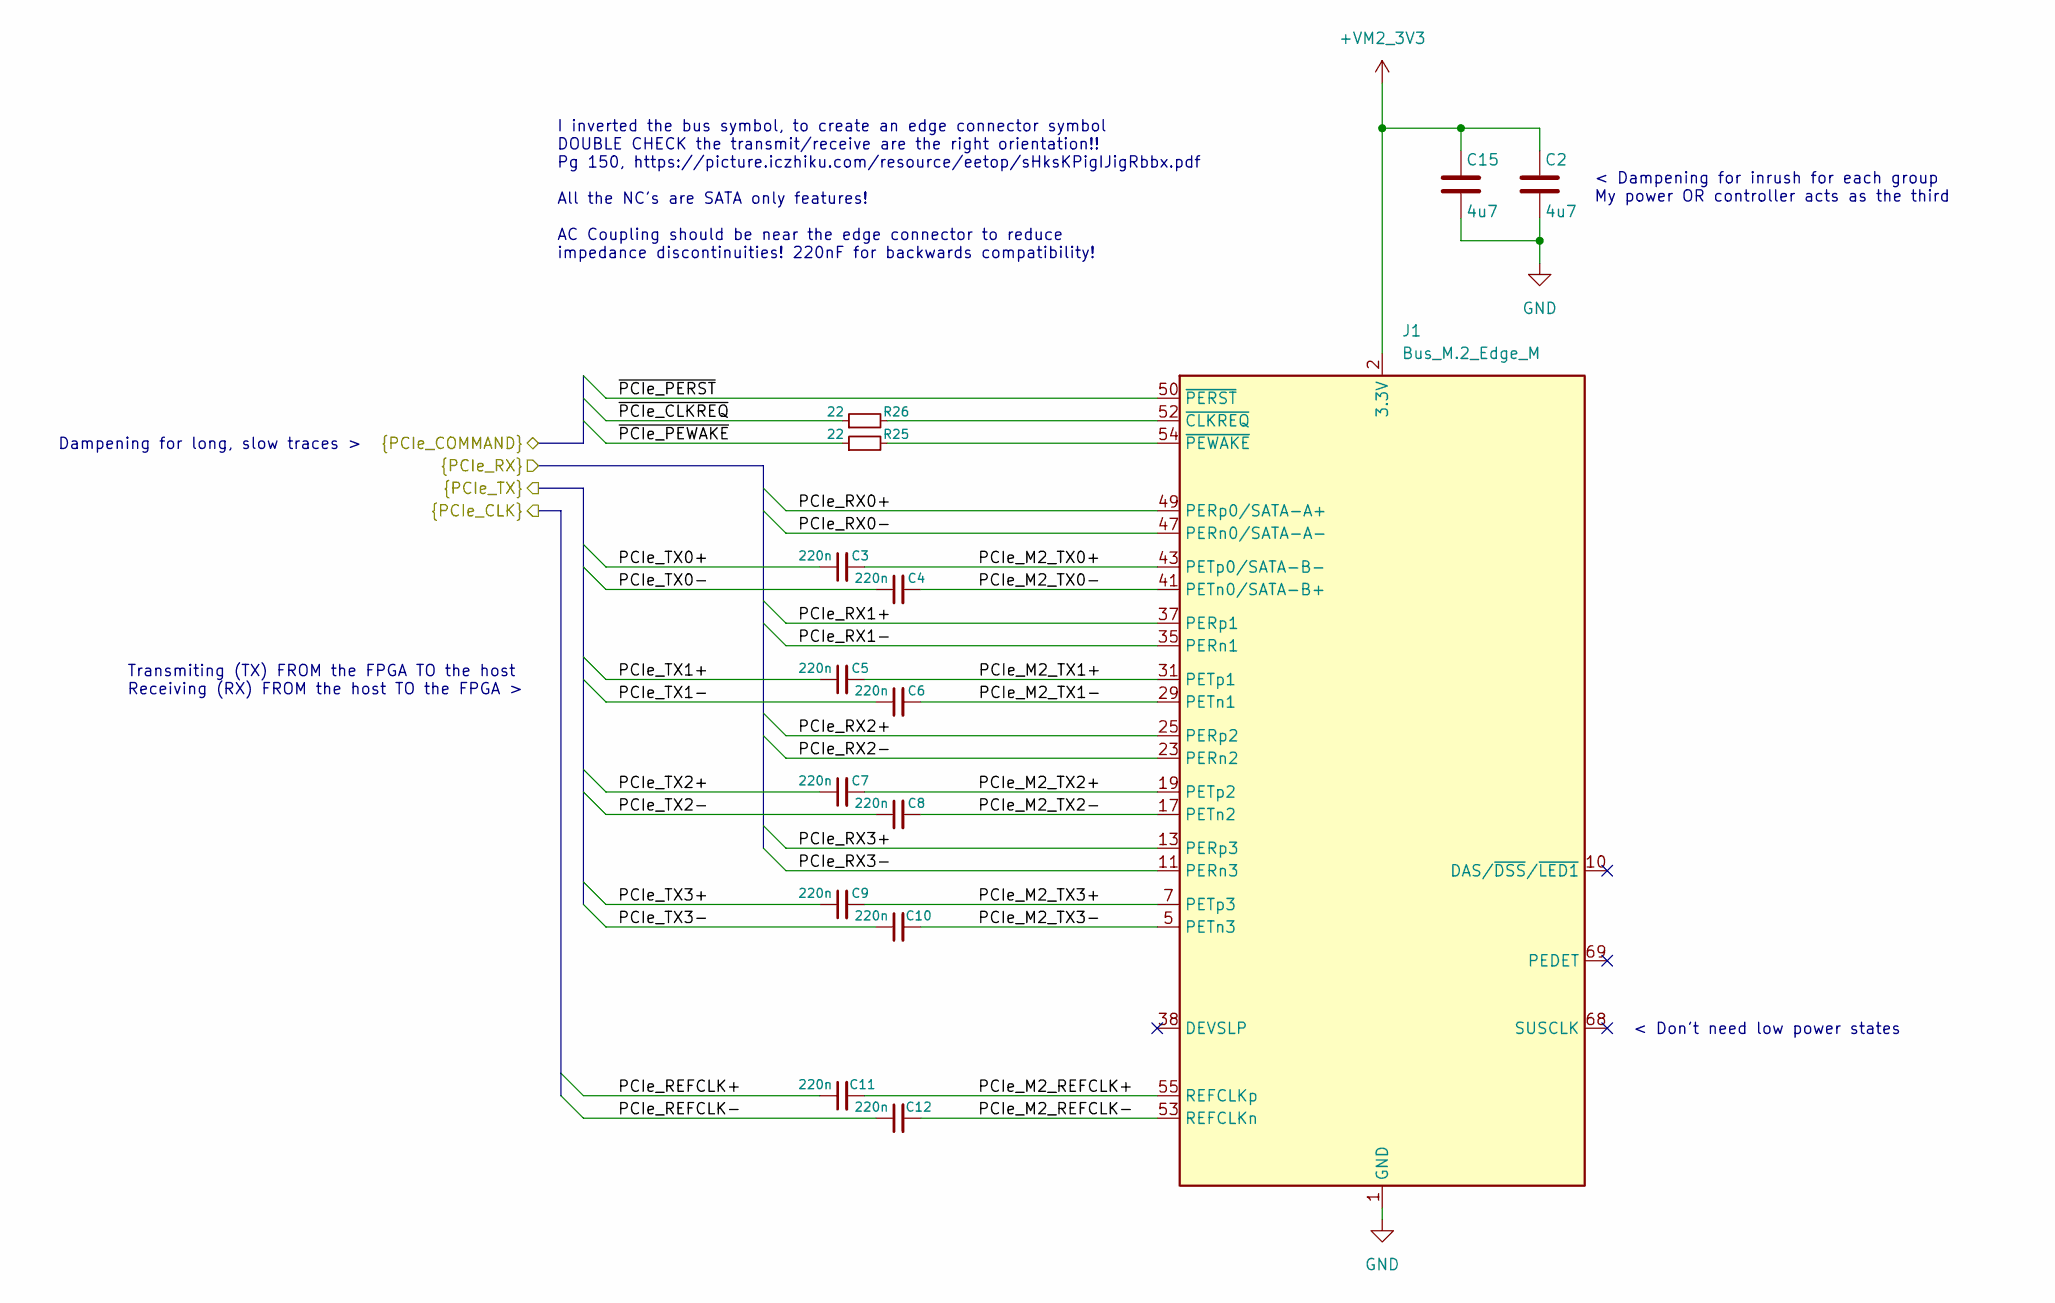
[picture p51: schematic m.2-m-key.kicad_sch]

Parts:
C2, C15: 4u7; C_0603_1608Metric
C3, C4, C5, C6, C7, C8, C9, C10, C11, C12: 220n; C_0402_1005Metric
J1: Bus_M.2_Edge_M; M.2 M-Key 2242
R25, R26: 22; R_0402_1005Metric

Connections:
+VM2_3V3: C2.1, C15.1, J1.2 (3.3V), J1.4 (3.3V), J1.12 (3.3V), J1.14 (3.3V), J1.16 (3.3V), J1.18 (3.3V), J1.70 (3.3V), J1.72 (3.3V), J1.74 (3.3V); also elsewhere on the board
/Artix 7 Banks/~PCIe_CLKREQ: R26.1; also elsewhere on the board
/Artix 7 Banks/~PCIe_PERST: J1.50 (~PERST); also elsewhere on the board
/Artix 7 Banks/~PCIe_PEWAKE: R25.1; also elsewhere on the board
/Artix 7 PCIe GTP Transceivers/PCIe_REFCLK+: C11.1; also elsewhere on the board
/Artix 7 PCIe GTP Transceivers/PCIe_REFCLK-: C12.1; also elsewhere on the board
/Artix 7 PCIe GTP Transceivers/PCIe_RX0+: J1.49 (PERp0/SATA-A+); also elsewhere on the board
/Artix 7 PCIe GTP Transceivers/PCIe_RX0-: J1.47 (PERn0/SATA-A-); also elsewhere on the board
/Artix 7 PCIe GTP Transceivers/PCIe_RX1+: J1.37 (PERp1); also elsewhere on the board
/Artix 7 PCIe GTP Transceivers/PCIe_RX1-: J1.35 (PERn1); also elsewhere on the board
/Artix 7 PCIe GTP Transceivers/PCIe_RX2+: J1.25 (PERp2); also elsewhere on the board
/Artix 7 PCIe GTP Transceivers/PCIe_RX2-: J1.23 (PERn2); also elsewhere on the board
/Artix 7 PCIe GTP Transceivers/PCIe_RX3+: J1.13 (PERp3); also elsewhere on the board
/Artix 7 PCIe GTP Transceivers/PCIe_RX3-: J1.11 (PERn3); also elsewhere on the board
/Artix 7 PCIe GTP Transceivers/PCIe_TX0+: C3.1; also elsewhere on the board
/Artix 7 PCIe GTP Transceivers/PCIe_TX0-: C4.1; also elsewhere on the board
/Artix 7 PCIe GTP Transceivers/PCIe_TX1+: C5.1; also elsewhere on the board
/Artix 7 PCIe GTP Transceivers/PCIe_TX1-: C6.1; also elsewhere on the board
/Artix 7 PCIe GTP Transceivers/PCIe_TX2+: C7.1; also elsewhere on the board
/Artix 7 PCIe GTP Transceivers/PCIe_TX2-: C8.1; also elsewhere on the board
/Artix 7 PCIe GTP Transceivers/PCIe_TX3+: C9.1; also elsewhere on the board
/Artix 7 PCIe GTP Transceivers/PCIe_TX3-: C10.1; also elsewhere on the board
/M.2 M-Key Edge Connector/PCIe_M2_REFCLK+: C11.2, J1.55 (REFCLKp)
/M.2 M-Key Edge Connector/PCIe_M2_REFCLK-: C12.2, J1.53 (REFCLKn)
/M.2 M-Key Edge Connector/PCIe_M2_TX0+: C3.2, J1.43 (PETp0/SATA-B-)
/M.2 M-Key Edge Connector/PCIe_M2_TX0-: C4.2, J1.41 (PETn0/SATA-B+)
/M.2 M-Key Edge Connector/PCIe_M2_TX1+: C5.2, J1.31 (PETp1)
/M.2 M-Key Edge Connector/PCIe_M2_TX1-: C6.2, J1.29 (PETn1)
/M.2 M-Key Edge Connector/PCIe_M2_TX2+: C7.2, J1.19 (PETp2)
/M.2 M-Key Edge Connector/PCIe_M2_TX2-: C8.2, J1.17 (PETn2)
/M.2 M-Key Edge Connector/PCIe_M2_TX3+: C9.2, J1.7 (PETp3)
/M.2 M-Key Edge Connector/PCIe_M2_TX3-: C10.2, J1.5 (PETn3)
GND: C2.2, C15.2, J1.1 (GND), J1.3 (GND), J1.9 (GND), J1.15 (GND), J1.21 (GND), J1.27 (GND), J1.33 (GND), J1.39 (GND), J1.45 (GND), J1.51 (GND), J1.57 (GND), J1.71 (GND), J1.73 (GND), J1.75 (GND); also elsewhere on the board
unnamed: J1.52 (~CLKREQ), R26.2
unnamed: J1.54 (~PEWAKE), R25.2

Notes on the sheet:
Transmiting (TX) FROM the FPGA TO the host Receiving (RX) FROM the host TO the FPGA >
Dampening for long, slow traces >
< Don't need low power states
< Dampening for inrush for each group My power OR controller acts as the third
I inverted the bus symbol, to create an edge connector symbol DOUBLE CHECK the transmit/receive are the right orientation!! Pg 150, https://picture.iczhiku.com/resource/eetop/sHksKPigIJigRbbx.pdf All the NC's are SATA only features! AC Coupling should be near the edge connector to reduce impedance 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

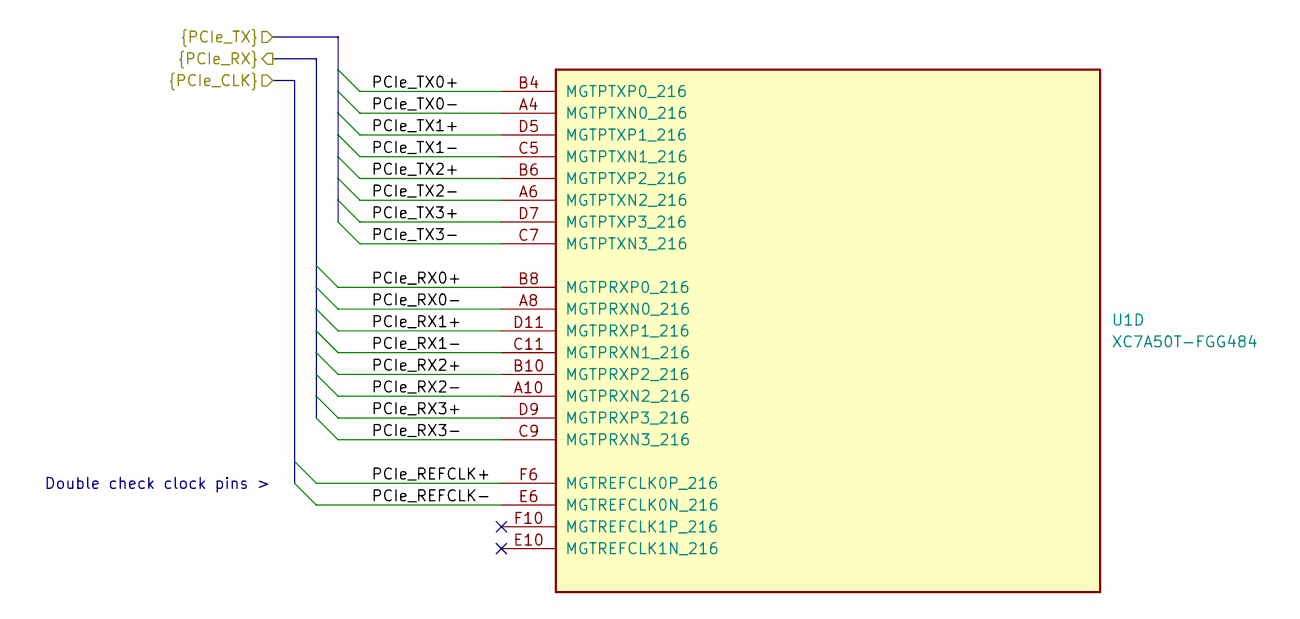
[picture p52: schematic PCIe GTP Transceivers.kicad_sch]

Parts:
U1: XC7A50T-FGG484; Xilinx_FGG484

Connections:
/Artix 7 PCIe GTP Transceivers/PCIe_REFCLK+: U1.F6 (MGTREFCLK0P_216); also elsewhere on the board
/Artix 7 PCIe GTP Transceivers/PCIe_REFCLK-: U1.E6 (MGTREFCLK0N_216); also elsewhere on the board
/Artix 7 PCIe GTP Transceivers/PCIe_RX0+: U1.B8 (MGTPRXP0_216); also elsewhere on the board
/Artix 7 PCIe GTP Transceivers/PCIe_RX0-: U1.A8 (MGTPRXN0_216); also elsewhere on the board
/Artix 7 PCIe GTP Transceivers/PCIe_RX1+: U1.D11 (MGTPRXP1_216); also elsewhere on the board
/Artix 7 PCIe GTP Transceivers/PCIe_RX1-: U1.C11 (MGTPRXN1_216); also elsewhere on the board
/Artix 7 PCIe GTP Transceivers/PCIe_RX2+: U1.B10 (MGTPRXP2_216); also elsewhere on the board
/Artix 7 PCIe GTP Transceivers/PCIe_RX2-: U1.A10 (MGTPRXN2_216); also elsewhere on the board
/Artix 7 PCIe GTP Transceivers/PCIe_RX3+: U1.D9 (MGTPRXP3_216); also elsewhere on the board
/Artix 7 PCIe GTP Transceivers/PCIe_RX3-: U1.C9 (MGTPRXN3_216); also elsewhere on the board
/Artix 7 PCIe GTP Transceivers/PCIe_TX0+: U1.B4 (MGTPTXP0_216); also elsewhere on the board
/Artix 7 PCIe GTP Transceivers/PCIe_TX0-: U1.A4 (MGTPTXN0_216); also elsewhere on the board
/Artix 7 PCIe GTP Transceivers/PCIe_TX1+: U1.D5 (MGTPTXP1_216); also elsewhere on the board
/Artix 7 PCIe GTP Transceivers/PCIe_TX1-: U1.C5 (MGTPTXN1_216); also elsewhere on the board
/Artix 7 PCIe GTP Transceivers/PCIe_TX2+: U1.B6 (MGTPTXP2_216); also elsewhere on the board
/Artix 7 PCIe GTP Transceivers/PCIe_TX2-: U1.A6 (MGTPTXN2_216); also elsewhere on the board
/Artix 7 PCIe GTP Transceivers/PCIe_TX3+: U1.D7 (MGTPTXP3_216); also elsewhere on the board
/Artix 7 PCIe GTP Transceivers/PCIe_TX3-: U1.C7 (MGTPTXN3_216); also elsewhere on the board

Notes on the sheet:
Double check clock pins >

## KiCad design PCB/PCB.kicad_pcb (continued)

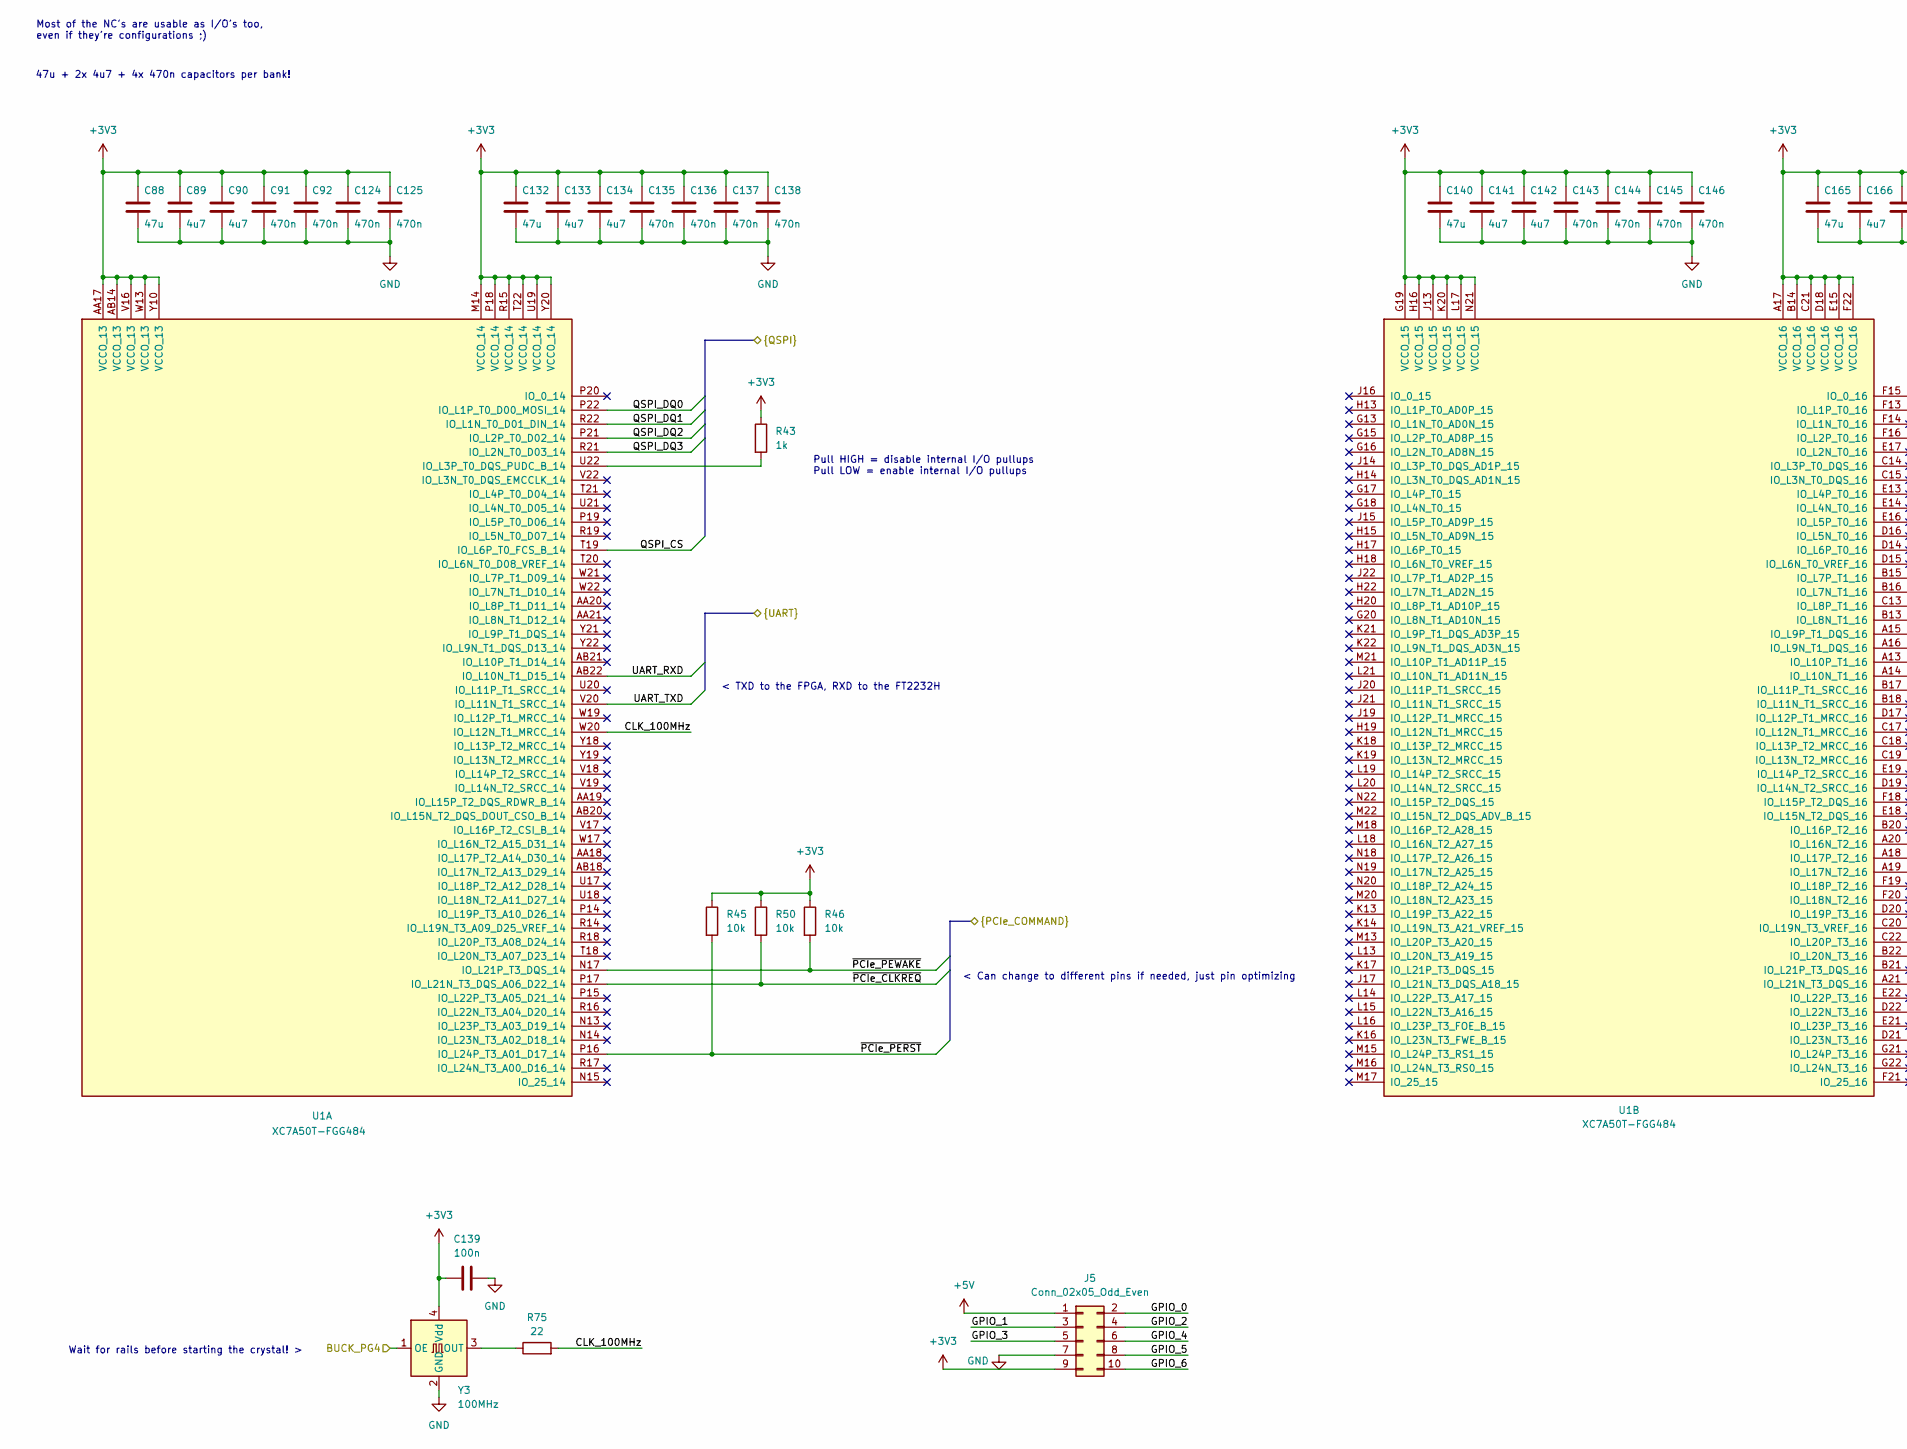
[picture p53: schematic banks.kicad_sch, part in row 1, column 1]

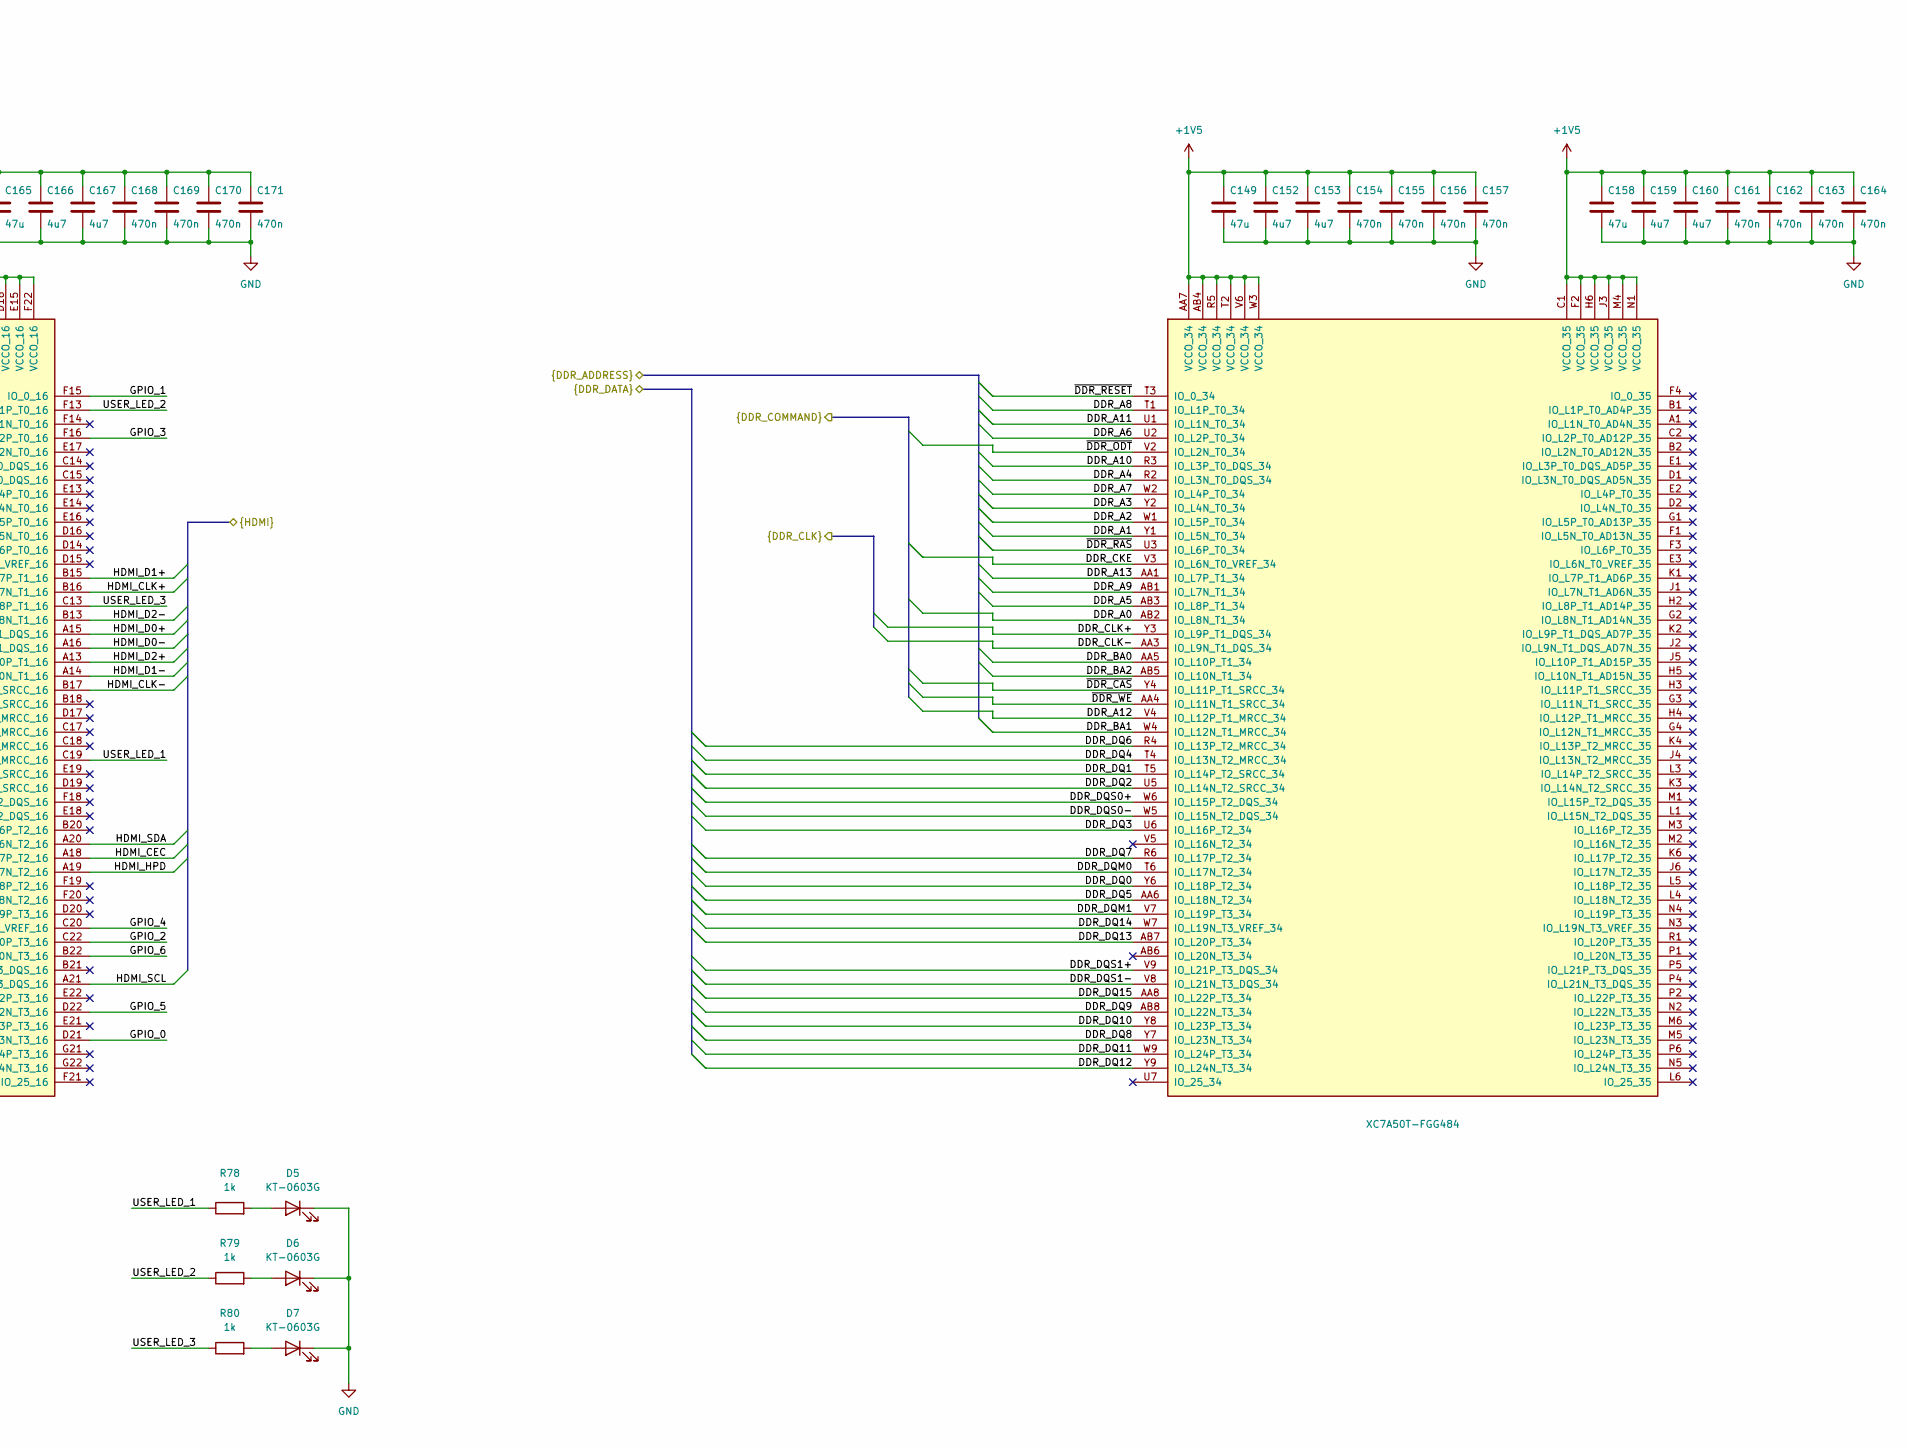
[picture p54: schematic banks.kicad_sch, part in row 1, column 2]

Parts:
C88, C132, C140, C149, C158, C165: 47u; C_1206_3216Metric
C89, C90, C133, C134, C141, C142, C152, C153, C159, C160, C166, C167: 4u7; C_0603_1608Metric
C91, C92, C124, C125, C135, C136, C137, C138, C143, C144, C145, C146, C154, C155, C156, C157, C161, C162, C163, C164, C168, C169, C170, C171: 470n; C_0201_0603Metric
C139: 100n; C_0402_1005Metric
D5, D6, D7: KT-0603G; LED_0603_1608Metric; MPN KT-0805G; LCSC C2297
J5: Conn_02x05_Odd_Even; PinHeader_2x05_P1.27mm_Vertical_SMD
R43, R78, R79, R80: 1k; R_0402_1005Metric
R45, R46, R50: 10k; R_0402_1005Metric
R75: 22; R_0402_1005Metric
U1: XC7A50T-FGG484; Xilinx_FGG484
Y3: 100MHz; Oscillator_SMD_SiT_PQFN-4Pin_5.0x3.2mm; MPN SIT8008BI-32-33E-100.000000; LCSC C78882

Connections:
+1V5: C149.1, C152.1, C153.1, C154.1, C155.1, C156.1, C157.1, C158.1, C159.1, C160.1, C161.1, C162.1, C163.1, C164.1, U1.AA7 (VCCO_34), U1.AB4 (VCCO_34), U1.C1 (VCCO_35), U1.F2 (VCCO_35), U1.H6 (VCCO_35), U1.J3 (VCCO_35), U1.M4 (VCCO_35), U1.N1 (VCCO_35), U1.R5 (VCCO_34), U1.T2 (VCCO_34), U1.V6 (VCCO_34), U1.W3 (VCCO_34); also elsewhere on the board
+3V3: C88.1, C89.1, C90.1, C91.1, C92.1, C124.1, C125.1, C132.1, C133.1, C134.1, C135.1, C136.1, C137.1, C138.1, C139.1, C140.1, C141.1, C142.1, C143.1, C144.1, C145.1, C146.1, C165.1, C166.1, C167.1, C168.1, C169.1, C170.1, C171.1, J5.9, R43.1, R45.1, R46.1, R50.1, U1.A17 (VCCO_16), U1.AA17 (VCCO_13), U1.AB14 (VCCO_13), U1.B14 (VCCO_16), U1.C21 (VCCO_16), U1.D18 (VCCO_16), U1.E15 (VCCO_16), U1.F22 (VCCO_16), U1.G19 (VCCO_15), U1.H16 (VCCO_15), U1.J13 (VCCO_15), U1.K20 (VCCO_15), U1.L17 (VCCO_15), U1.M14 (VCCO_14), U1.N21 (VCCO_15), U1.P18 (VCCO_14), U1.R15 (VCCO_14), U1.T22 (VCCO_14), U1.U19 (VCCO_14), U1.V16 (VCCO_13), U1.W13 (VCCO_13), U1.Y10 (VCCO_13), U1.Y20 (VCCO_14), Y3.4 (Vdd); also elsewhere on the board
+5V: J5.1; also elsewhere on the board
/Artix 7 Banks/BUCK_PG4: Y3.1 (OE); also elsewhere on the board
/Artix 7 Banks/CLK_100MHz: R75.2, U1.W20 (IO_L12N_T1_MRCC_14)
/Artix 7 Banks/DDR_A0: U1.AB2 (IO_L8N_T1_34); also elsewhere on the board
/Artix 7 Banks/DDR_A1: U1.Y1 (IO_L5N_T0_34); also elsewhere on the board
/Artix 7 Banks/DDR_A2: U1.W1 (IO_L5P_T0_34); also elsewhere on the board
/Artix 7 Banks/DDR_A3: U1.Y2 (IO_L4N_T0_34); also elsewhere on the board
/Artix 7 Banks/DDR_A4: U1.R2 (IO_L3N_T0_DQS_34); also elsewhere on the board
/Artix 7 Banks/DDR_A5: U1.AB3 (IO_L8P_T1_34); also elsewhere on the board
/Artix 7 Banks/DDR_A6: U1.U2 (IO_L2P_T0_34); also elsewhere on the board
/Artix 7 Banks/DDR_A7: U1.W2 (IO_L4P_T0_34); also elsewhere on the board
/Artix 7 Banks/DDR_A8: U1.T1 (IO_L1P_T0_34); also elsewhere on the board
/Artix 7 Banks/DDR_A9: U1.AB1 (IO_L7N_T1_34); also elsewhere on the board
/Artix 7 Banks/DDR_A10: U1.R3 (IO_L3P_T0_DQS_34); also elsewhere on the board
/Artix 7 Banks/DDR_A11: U1.U1 (IO_L1N_T0_34); also elsewhere on the board
/Artix 7 Banks/DDR_A12: U1.V4 (IO_L12P_T1_MRCC_34); also elsewhere on the board
/Artix 7 Banks/DDR_A13: U1.AA1 (IO_L7P_T1_34); also elsewhere on the board
/Artix 7 Banks/DDR_BA0: U1.AA5 (IO_L10P_T1_34); also elsewhere on the board
/Artix 7 Banks/DDR_BA1: U1.W4 (IO_L12N_T1_MRCC_34); also elsewhere on the board
/Artix 7 Banks/DDR_BA2: U1.AB5 (IO_L10N_T1_34); also elsewhere on the board
/Artix 7 Banks/DDR_CKE: U1.V3 (IO_L6N_T0_VREF_34); also elsewhere on the board
/Artix 7 Banks/DDR_CLK+: U1.Y3 (IO_L9P_T1_DQS_34); also elsewhere on the board
/Artix 7 Banks/DDR_CLK-: U1.AA3 (IO_L9N_T1_DQS_34); also elsewhere on the board
/Artix 7 Banks/DDR_DQ0: U1.Y6 (IO_L18P_T2_34); also elsewhere on the board
/Artix 7 Banks/DDR_DQ1: U1.T5 (IO_L14P_T2_SRCC_34); also elsewhere on the board
/Artix 7 Banks/DDR_DQ2: U1.U5 (IO_L14N_T2_SRCC_34); also elsewhere on the board
/Artix 7 Banks/DDR_DQ3: U1.U6 (IO_L16P_T2_34); also elsewhere on the board
/Artix 7 Banks/DDR_DQ4: U1.T4 (IO_L13N_T2_MRCC_34); also elsewhere on the board
/Artix 7 Banks/DDR_DQ5: U1.AA6 (IO_L18N_T2_34); also elsewhere on the board
/Artix 7 Banks/DDR_DQ6: U1.R4 (IO_L13P_T2_MRCC_34); also elsewhere on the board
/Artix 7 Banks/DDR_DQ7: U1.R6 (IO_L17P_T2_34); also elsewhere on the board
/Artix 7 Banks/DDR_DQ8: U1.Y7 (IO_L23N_T3_34); also elsewhere on the board
/Artix 7 Banks/DDR_DQ9: U1.AB8 (IO_L22N_T3_34); also elsewhere on the board
/Artix 7 Banks/DDR_DQ10: U1.Y8 (IO_L23P_T3_34); also elsewhere on the board
/Artix 7 Banks/DDR_DQ11: U1.W9 (IO_L24P_T3_34); also elsewhere on the board
/Artix 7 Banks/DDR_DQ12: U1.Y9 (IO_L24N_T3_34); also elsewhere on the board
/Artix 7 Banks/DDR_DQ13: U1.AB7 (IO_L20P_T3_34); also elsewhere on the board
/Artix 7 Banks/DDR_DQ14: U1.W7 (IO_L19N_T3_VREF_34); also elsewhere on the board
/Artix 7 Banks/DDR_DQ15: U1.AA8 (IO_L22P_T3_34); also elsewhere on the board
/Artix 7 Banks/DDR_DQM0: U1.T6 (IO_L17N_T2_34); also elsewhere on the board
/Artix 7 Banks/DDR_DQM1: U1.V7 (IO_L19P_T3_34); also elsewhere on the board
/Artix 7 Banks/DDR_DQS0+: U1.W6 (IO_L15P_T2_DQS_34); also elsewhere on the board
/Artix 7 Banks/DDR_DQS0-: U1.W5 (IO_L15N_T2_DQS_34); also elsewhere on the board
/Artix 7 Banks/DDR_DQS1+: U1.V9 (IO_L21P_T3_DQS_34); also elsewhere on the board
/Artix 7 Banks/DDR_DQS1-: U1.V8 (IO_L21N_T3_DQS_34); also elsewhere on the board
/Artix 7 Banks/GPIO_0: J5.2, U1.D21 (IO_L23N_T3_16)
/Artix 7 Banks/GPIO_1: J5.3, U1.F15 (IO_0_16)
/Artix 7 Banks/GPIO_2: J5.4, U1.C22 (IO_L20P_T3_16)
/Artix 7 Banks/GPIO_3: J5.5, U1.F16 (IO_L2P_T0_16)
/Artix 7 Banks/GPIO_4: J5.6, U1.C20 (IO_L19N_T3_VREF_16)
/Artix 7 Banks/GPIO_5: J5.8, U1.D22 (IO_L22N_T3_16)
/Artix 7 Banks/GPIO_6: J5.10, U1.B22 (IO_L20N_T3_16)
/Artix 7 Banks/HDMI_CEC: U1.A18 (IO_L17P_T2_16); also elsewhere on the board
/Artix 7 Banks/HDMI_CLK+: U1.B16 (IO_L7N_T1_16); also elsewhere on the board
/Artix 7 Banks/HDMI_CLK-: U1.B17 (IO_L11P_T1_SRCC_16); also elsewhere on the board
/Artix 7 Banks/HDMI_D0+: U1.A15 (IO_L9P_T1_DQS_16); also elsewhere on the board
/Artix 7 Banks/HDMI_D0-: U1.A16 (IO_L9N_T1_DQS_16); also elsewhere on the board
/Artix 7 Banks/HDMI_D1+: U1.B15 (IO_L7P_T1_16); also elsewhere on the board
/Artix 7 Banks/HDMI_D1-: U1.A14 (IO_L10N_T1_16); also elsewhere on the board
/Artix 7 Banks/HDMI_D2+: U1.A13 (IO_L10P_T1_16); also elsewhere on the board
/Artix 7 Banks/HDMI_D2-: U1.B13 (IO_L8N_T1_16); also elsewhere on the board
/Artix 7 Banks/HDMI_HPD: U1.A19 (IO_L17N_T2_16); also elsewhere on the board
/Artix 7 Banks/HDMI_SCL: U1.A21 (IO_L21N_T3_DQS_16); also elsewhere on the board
/Artix 7 Banks/HDMI_SDA: U1.A20 (IO_L16N_T2_16); also elsewhere on the board
/Artix 7 Banks/QSPI_CS: U1.T19 (IO_L6P_T0_FCS_B_14); also elsewhere on the board
/Artix 7 Banks/QSPI_DQ0: U1.P22 (IO_L1P_T0_D00_MOSI_14); also elsewhere on the board
/Artix 7 Banks/QSPI_DQ1: U1.R22 (IO_L1N_T0_D01_DIN_14); also elsewhere on the board
/Artix 7 Banks/QSPI_DQ2: U1.P21 (IO_L2P_T0_D02_14); also elsewhere on the board
/Artix 7 Banks/QSPI_DQ3: U1.R21 (IO_L2N_T0_D03_14); also elsewhere on the board
/Artix 7 Banks/UART_RXD: U1.AB22 (IO_L10N_T1_D15_14); also elsewhere on the board
/Artix 7 Banks/UART_TXD: U1.V20 (IO_L11N_T1_SRCC_14); also elsewhere on the board
/Artix 7 Banks/USER_LED_1: R78.1, U1.C19 (IO_L13N_T2_MRCC_16)
/Artix 7 Banks/USER_LED_2: R79.1, U1.F13 (IO_L1P_T0_16)
/Artix 7 Banks/USER_LED_3: R80.1, U1.C13 (IO_L8P_T1_16)
/Artix 7 Banks/~DDR_CAS: U1.Y4 (IO_L11P_T1_SRCC_34); also elsewhere on the board
/Artix 7 Banks/~DDR_ODT: U1.V2 (IO_L2N_T0_34); also elsewhere on the board
/Artix 7 Banks/~DDR_RAS: U1.U3 (IO_L6P_T0_34); also elsewhere on the board
/Artix 7 Banks/~DDR_RESET: U1.T3 (IO_0_34); also elsewhere on the board
/Artix 7 Banks/~DDR_WE: U1.AA4 (IO_L11N_T1_SRCC_34); also elsewhere on the board
/Artix 7 Banks/~PCIe_CLKREQ: R50.2, U1.P17 (IO_L21N_T3_DQS_A06_D22_14); also elsewhere on the board
/Artix 7 Banks/~PCIe_PERST: R45.2, U1.P16 (IO_L24P_T3_A01_D17_14); also elsewhere on the board
/Artix 7 Banks/~PCIe_PEWAKE: R46.2, U1.N17 (IO_L21P_T3_DQS_14); also elsewhere on the board
GND: C88.2, C89.2, C90.2, C91.2, C92.2, C124.2, C125.2, C132.2, C133.2, C134.2, C135.2, C136.2, C137.2, C138.2, C139.2, C140.2, C141.2, C142.2, C143.2, C144.2, C145.2, C146.2, C149.2, C152.2, C153.2, C154.2, C155.2, C156.2, C157.2, C158.2, C159.2, C160.2, C161.2, C162.2, C163.2, C164.2, C165.2, C166.2, C167.2, C168.2, C169.2, C170.2, C171.2, D5.1 (K), D6.1 (K), D7.1 (K), J5.7, Y3.2 (GND); also elsewhere on the board
unnamed: D5.2 (A), R78.2
unnamed: D6.2 (A), R79.2
unnamed: D7.2 (A), R80.2
unnamed: R43.2, U1.U22 (IO_L3P_T0_DQS_PUDC_B_14)
unnamed: R75.1, Y3.3 (OUT)

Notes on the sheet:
Most of the NC's are usable as I/O's too, even if they're configurations ;)
47u + 2x 4u7 + 4x 470n capacitors per bank!
< Can change to different pins if needed, just pin optimizing
Wait for rails before starting the crystal! >
< TXD to the FPGA, RXD to the FT2232H
Pull HIGH = disable internal I/O pullups Pull LOW = enable internal I/O pullups

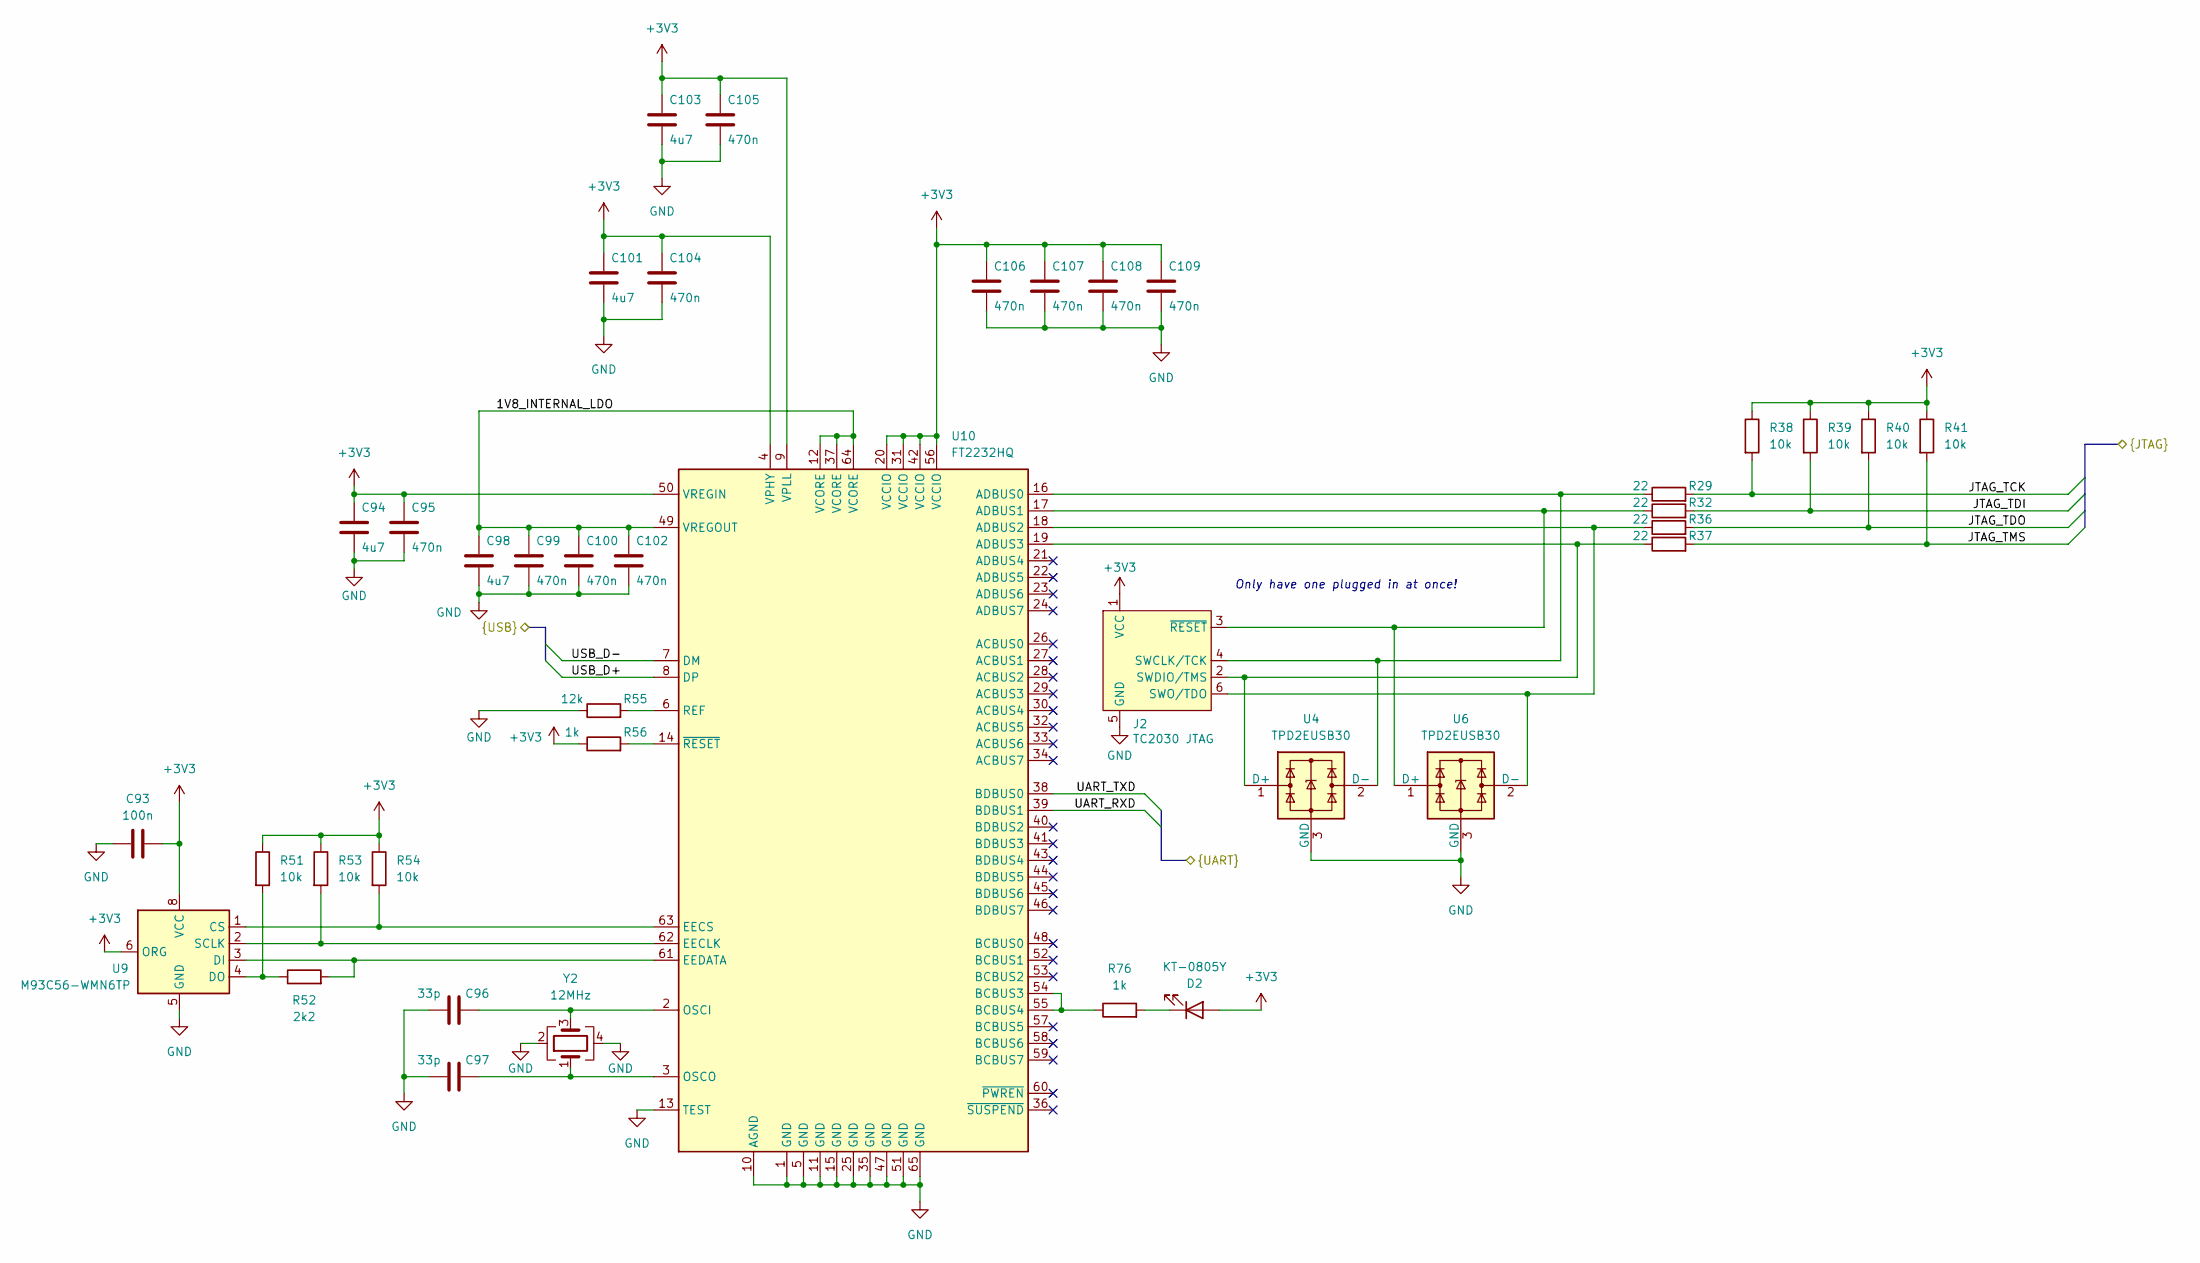
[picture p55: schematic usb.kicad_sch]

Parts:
C93: 100n; C_0402_1005Metric
C94, C98, C101, C103: 4u7; C_0603_1608Metric
C95, C99, C100, C102, C104, C105, C106, C107, C108, C109: 470n; C_0201_0603Metric
C96, C97: 33p; C_0402_1005Metric
D2: KT-0805Y; LED_0805_2012Metric; MPN KT-0805Y; LCSC C2296
J2: Conn_ARM_SWD_TagConnect_TC2030; Tag-Connect_TC2030-IDC-FP_2x03_P1.27mm_Vertical
R29, R32, R36, R37: 22; R_0402_1005Metric
R38, R39, R40, R41, R51, R53, R54: 10k; R_0402_1005Metric
R52: 2k2; R_0402_1005Metric
R55: 12k; R_0402_1005Metric
R56, R76: 1k; R_0402_1005Metric
U4, U6: TPD2EUSB30; Texas_DRT-3
U9: M93C56-WMN6TP; SOIC-8_3.9x4.9mm_P1.27mm
U10: FT2232HQ; QFN-64-1EP_9x9mm_P0.5mm_EP4.35x4.35mm
Y2: 12MHz; Crystal_SMD_3225-4Pin_3.2x2.5mm; MPN X322512MSB4SI; LCSC C9002

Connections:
+3V3: C93.2, C94.1, C95.1, C101.1, C103.1, C104.1, C105.1, C106.1, C107.1, C108.1, C109.1, D2.2 (A), J2.1 (VCC), R38.1, R39.1, R40.1, R41.1, R51.1, R53.1, R54.1, R56.1, U9.6 (ORG), U9.8 (VCC), U10.4 (VPHY), U10.9 (VPLL), U10.20 (VCCIO), U10.31 (VCCIO), U10.42 (VCCIO), U10.50 (VREGIN), U10.56 (VCCIO); also elsewhere on the board
/Artix 7 Banks/UART_RXD: U10.39 (BDBUS1); also elsewhere on the board
/Artix 7 Banks/UART_TXD: U10.38 (BDBUS0); also elsewhere on the board
/Artix 7 Configurations and Flash/JTAG_TCK: R29.2, R38.2; also elsewhere on the board
/Artix 7 Configurations and Flash/JTAG_TDI: R32.2, R39.2; also elsewhere on the board
/Artix 7 Configurations and Flash/JTAG_TDO: R36.2, R40.2; also elsewhere on the board
/Artix 7 Configurations and Flash/JTAG_TMS: R37.2, R41.2; also elsewhere on the board
/USB to JTAG/1V8_INTERNAL_LDO: C98.1, C99.1, C100.1, C102.1, U10.12 (VCORE), U10.37 (VCORE), U10.49 (VREGOUT), U10.64 (VCORE)
/USB to JTAG/USB_D+: U10.8 (DP); also elsewhere on the board
/USB to JTAG/USB_D-: U10.7 (DM); also elsewhere on the board
GND: C93.1, C94.2, C95.2, C96.1, C97.1, C98.2, C99.2, C100.2, C101.2, C102.2, C103.2, C104.2, C105.2, C106.2, C107.2, C108.2, C109.2, J2.5 (GND), R55.1, U4.3 (GND), U6.3 (GND), U9.5 (GND), U10.1 (GND), U10.5 (GND), U10.10 (AGND), U10.11 (GND), U10.13 (TEST), U10.15 (GND), U10.25 (GND), U10.35 (GND), U10.47 (GND), U10.51 (GND), U10.65 (GND), Y2.2, Y2.4; also elsewhere on the board
unnamed: D2.1 (K), R76.2
unnamed: J2.4 (SWCLK/TCK), R29.1, U4.2 (D-), U10.16 (ADBUS0)
unnamed: J2.2 (SWDIO/TMS), R37.1, U4.1 (D+), U10.19 (ADBUS3)
unnamed: J2.6 (SWO/TDO), R36.1, U6.2 (D-), U10.18 (ADBUS2)
unnamed: J2.3 (~RESET), R32.1, U6.1 (D+), U10.17 (ADBUS1)
unnamed: R51.2, R52.1, U9.4 (DO)
unnamed: R76.1, U10.54 (BCBUS3), U10.55 (BCBUS4)
unnamed: R53.2, U9.2 (SCLK), U10.62 (EECLK)
unnamed: R54.2, U9.1 (CS), U10.63 (EECS)
unnamed: R52.2, U9.3 (DI), U10.61 (EEDATA)
unnamed: C96.2, U10.2 (OSCI), Y2.3
unnamed: C97.2, U10.3 (OSCO), Y2.1
unnamed: R55.2, U10.6 (REF)
unnamed: R56.2, U10.14 (~RESET)

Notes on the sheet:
Only have one plugged in at once!

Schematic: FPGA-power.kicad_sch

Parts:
C17, C18, C19, C20, C25, C27, C28, C29, C30, C31, C35, C36, C38, C39, C47, C54, C118, C148: 470n; C_0201_0603Metric
C21, C22, C23, C32, C33, C37, C40, C56: 4u7; C_0603_1608Metric
C24: 330u; CP_EIA-3528-21_Kemet-B; MPN ETPE330MA9GB; LCSC C542287
C26: 100u; C_1206_3216Metric; MPN CL31A107MQHNNNE; LCSC C15008
C34: 47u; C_1206_3216Metric
FB1: 120@100MHz; L_0805_2012Metric; MPN 742792023; LCSC C5120901
R1: 100; R_0402_1005Metric
U1: XC7A50T-FGG484; Xilinx_FGG484

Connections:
+1V0: C17.1, C18.1, C19.1, C20.1, C21.1, C22.1, C23.1, C24.1, C25.1, C26.1, C56.1, C118.1, C148.1, FB1.1, U1.H8 (VCCINT), U1.H10 (VCCINT), U1.J7 (VCCINT), U1.J9 (VCCINT), U1.J11 (VCCBRAM), U1.K8 (VCCINT), U1.L7 (VCCINT), U1.L11 (VCCBRAM), U1.M8 (VCCINT), U1.N7 (VCCINT), U1.N11 (VCCBRAM), U1.P8 (VCCINT), U1.P10 (VCCINT), U1.R7 (VCCINT), U1.R9 (VCCINT), U1.T8 (VCCINT), U1.T10 (VCCINT); also elsewhere on the board
+1V2: C38.1, C39.1, C40.1, R1.2, U1.B5 (MGTAVTT), U1.B7 (MGTAVTT), U1.B9 (MGTAVTT), U1.B11 (MGTAVTT), U1.C4 (MGTAVTT), U1.C8 (MGTAVTT); also elsewhere on the board
+1V8: C27.1, C28.1, C29.1, C30.1, C31.1, C32.1, C33.1, C34.1, C47.1, C54.1, U1.E12 (VCCBATT_0), U1.H12 (VCCAUX), U1.K10 (VCCADC_0), U1.K12 (VCCAUX), U1.M12 (VCCAUX), U1.P12 (VCCAUX), U1.R11 (VCCAUX); also elsewhere on the board
GND: C17.2, C18.2, C19.2, C20.2, C21.2, C22.2, C23.2, C24.2, C25.2, C26.2, C27.2, C28.2, C29.2, C30.2, C31.2, C32.2, C33.2, C34.2, C35.2, C36.2, C37.2, C38.2, C39.2, C40.2, C47.2, C54.2, C56.2, C118.2, C148.2, U1.A2 (GND), U1.A3 (GND), U1.A5 (GND), U1.A7 (GND), U1.A9 (GND), U1.A11 (GND), U1.A12 (GND), U1.A22 (GND), U1.AA2 (GND), U1.AA12 (GND), U1.AA22 (GND), U1.AB9 (GND), U1.AB19 (GND), U1.B3 (GND), U1.B12 (GND), U1.B19 (GND), U1.C3 (GND), U1.C6 (GND), U1.C10 (GND), U1.C12 (GND), U1.C16 (GND), U1.D3 (GND), U1.D4 (GND), U1.D8 (GND), U1.D12 (GND), U1.D13 (GND), U1.E4 (GND), U1.E5 (GND), U1.E7 (GND), U1.E9 (GND), U1.E11 (GND), U1.E20 (GND), U1.F5 (GND), U1.F11 (GND), U1.F17 (GND), U1.G5 (GND), U1.G6 (GND), U1.G7 (GND), U1.G8 (GND), U1.G9 (GND), U1.G10 (GND), U1.G12 (GND), U1.G14 (GND), U1.H1 (GND), U1.H7 (GND), U1.H9 (GND), U1.H11 (GND), U1.H21 (GND), U1.J8 (GND), U1.J10 (GND), U1.J12 (GND), U1.J18 (GND), U1.K5 (GND), U1.K7 (GND), U1.K9 (GNDADC_0), U1.K11 (GND), U1.K15 (GND), U1.L2 (GND), U1.L8 (GND), U1.L22 (GND), U1.M7 (GND), U1.M11 (GND), U1.M19 (GND), U1.N6 (GND), U1.N8 (GND), U1.N16 (GND), U1.P3 (GND), U1.P7 (GND), U1.P9 (GND), U1.P11 (GND), U1.P13 (GND), U1.R8 (GND), U1.R10 (GND), U1.R12 (GND), U1.R20 (GND), U1.T7 (GND), U1.T9 (GND), U1.T11 (GND), U1.T17 (GND), U1.U4 (GND), U1.U14 (GND), U1.V1 (GND), U1.V11 (GND), U1.V21 (GND), U1.W8 (GND), U1.W18 (GND), U1.Y5 (GND), U1.Y15 (GND); also elsewhere on the board
unnamed: C35.1, C36.1, C37.1, FB1.2, U1.D6 (MGTAVCC), U1.D10 (MGTAVCC), U1.E8 (MGTAVCC), U1.F7 (MGTAVCC), U1.F9 (MGTAVCC)
unnamed: R1.1, U1.F8 (MGTRREF_216)

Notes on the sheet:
No ferrite bead because low impedance termination rail!
Remember to model pi filter!
Simulate beads in LTSpice!
Maybe a ferrite bead on VCCADC >

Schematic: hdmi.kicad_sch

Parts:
C14, C16, C113, C114, C115, C116, C117, C119, C120, C122, C123: 100n; C_0402_1005Metric
C121: 1u; C_0402_1005Metric
D3: 1N5819WS; D_SOD-323; MPN 1N5819WS
J7: HDMI_D_1.4; Kai's_HDMI_Micro-D_Molex_46765-1xxx; MPN HYC23-HDMID19-650; LCSC C711358
R47: 30k; R_0603_1608Metric
R57: 1k; R_0402_1005Metric
R58: 100k; R_0402_1005Metric
R59, R60, R61, R62: 4k7; R_0402_1005Metric
U12: PCA9306DC1; VSSOP-8_2.3x2mm_P0.5mm; MPN PCA9306DC1; LCSC C129510
U14, U15, U16: UCL0524P; Diodes_UDFN-10_1.0x2.5mm_P0.5mm; MPN UCL0524P; LCSC C2835428

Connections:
+3V3: C123.1, R47.1, R61.1, R62.1, U12.2 (VREF1); also elsewhere on the board
+5V: D3.2 (A), R58.1, R59.1, R60.1; also elsewhere on the board
/Artix 7 Banks/HDMI_CEC: J7.15 (CEC), R47.2, U14.4, U14.7; also elsewhere on the board
/Artix 7 Banks/HDMI_CLK+: C16.1; also elsewhere on the board
/Artix 7 Banks/HDMI_CLK-: C14.1; also elsewhere on the board
/Artix 7 Banks/HDMI_D0+: C116.1; also elsewhere on the board
/Artix 7 Banks/HDMI_D0-: C115.1; also elsewhere on the board
/Artix 7 Banks/HDMI_D1+: C114.1; also elsewhere on the board
/Artix 7 Banks/HDMI_D1-: C113.1; also elsewhere on the board
/Artix 7 Banks/HDMI_D2+: C119.1; also elsewhere on the board
/Artix 7 Banks/HDMI_D2-: C117.1; also elsewhere on the board
/Artix 7 Banks/HDMI_HPD: R57.1; also elsewhere on the board
/Artix 7 Banks/HDMI_SCL: R62.2, U12.4 (SDA1); also elsewhere on the board
/Artix 7 Banks/HDMI_SDA: R61.2, U12.3 (SCL1); also elsewhere on the board
/HDMI/HDMI_CONN_CLK+: C16.2, J7.12 (CK+), U16.4, U16.7
/HDMI/HDMI_CONN_CLK-: C14.2, J7.14 (CK-), U16.5, U16.6
/HDMI/HDMI_CONN_D0+: C116.2, J7.9 (D0+), U15.4, U15.7
/HDMI/HDMI_CONN_D0-: C115.2, J7.11 (D0-), U15.5, U15.6
/HDMI/HDMI_CONN_D1+: C114.2, J7.6 (D1+), U16.1, U16.10
/HDMI/HDMI_CONN_D1-: C113.2, J7.8 (D1-), U16.2, U16.9
/HDMI/HDMI_CONN_D2+: C119.2, J7.3 (D2+), U15.1, U15.10
/HDMI/HDMI_CONN_D2-: C117.2, J7.5 (D2-), U15.2, U15.9
/HDMI/HDMI_SCL_5V: J7.17 (SCL), R59.2, U12.5 (SDA2), U14.2, U14.9
/HDMI/HDMI_SDA_5V: J7.18 (SDA), R60.2, U12.6 (SCL2), U14.1, U14.10
GND: C120.2, C121.2, C122.2, C123.2, J7.4 (D2S), J7.7 (D1S), J7.10 (D0S), J7.13 (CKS), J7.16 (GND), J7.SH, U12.1 (GND), U14.3, U14.8, U15.3, U15.8, U16.3, U16.8; also elsewhere on the board
unnamed: C120.1, C121.1, D3.1 (K), J7.19 (+5V)
unnamed: J7.1 (HPD/HEAC-), R57.2, U14.5, U14.6
unnamed: C122.1, R58.2, U12.7 (VREF2), U12.8 (EN)

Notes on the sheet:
Current limit resistor!

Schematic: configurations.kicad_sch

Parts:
C111: 100n; C_0402_1005Metric
C150, C151: 470n; C_0201_0603Metric
D1: KT-0603R; LED_0603_1608Metric; MPN KT-0805Y; LCSC C2296
R2, R3, R14, R24: 1k; R_0402_1005Metric
R15: 1k; R_0402_1005Metric; not fitted
R19, R20, R21, R27, R44, R63: 4k7; R_0402_1005Metric
U1: XC7A50T-FGG484; Xilinx_FGG484
U7: MT25QL128ABA1EW7-0SIT; W-PDFN-8-1EP_6x5mm_P1.27mm_EP3x3mm; MPN MT25QL128ABA1EW7-0SIT; LCSC C2887898

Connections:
+3V3: C111.1, C150.1, C151.1, D1.2 (A), R2.1, R15.1, R19.1, R20.1, R21.1, R27.2, R44.2, R63.2, U1.F12 (VCCO_0), U1.T12 (VCCO_0), U1.U8 (CFGBVS_0), U7.8 (VCC); also elsewhere on the board
/Artix 7 Banks/QSPI_CS: R19.2, U7.1 (~S); also elsewhere on the board
/Artix 7 Banks/QSPI_DQ0: U7.5 (DQ0); also elsewhere on the board
/Artix 7 Banks/QSPI_DQ1: U7.2 (DQ1); also elsewhere on the board
/Artix 7 Banks/QSPI_DQ2: R20.2, U7.3 (~W/DQ2); also elsewhere on the board
/Artix 7 Banks/QSPI_DQ3: R21.2, U7.7 (~RESET/DQ3); also elsewhere on the board
/Artix 7 Configurations and Flash/DONE: R24.1, R63.1, U1.G11 (DONE_0)
/Artix 7 Configurations and Flash/JTAG_TCK: U1.V12 (TCK_0); also elsewhere on the board
/Artix 7 Configurations and Flash/JTAG_TDI: U1.R13 (TDI_0); also elsewhere on the board
/Artix 7 Configurations and Flash/JTAG_TDO: U1.U13 (TDO_0); also elsewhere on the board
/Artix 7 Configurations and Flash/JTAG_TMS: U1.T13 (TMS_0); also elsewhere on the board
/Artix 7 Configurations and Flash/QSPI_CLK: U1.L12 (CCLK_0), U7.6 (C)
GND: C111.2, C150.2, C151.2, R3.2, R14.2, U1.L9 (VREFN_0), U1.L10 (VP_0), U1.M9 (VN_0), U1.M10 (VREFP_0), U1.N9 (DXN_0), U1.N10 (DXP_0), U7.4 (VSS), U7.9 (PAD); also elsewhere on the board
unnamed: D1.1 (K), R24.2
unnamed: R27.1, U1.U12 (INIT_B_0)
unnamed: R2.2, U1.U11 (M0_0)
unnamed: R14.1, U1.U10 (M1_0)
unnamed: R3.1, R15.2, U1.U9 (M2_0)
unnamed: R44.1, U1.N12 (PROGRAM_B_0)

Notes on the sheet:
< Optional for JTAG w/ built in artix memory
Bank 14/15 need to be 3V3 because of CFGBVS
< Master SPI M[2:0] 001
< No temp sense, no internals, tying low (UG475)
< DONE sinks current, LED turns off when done

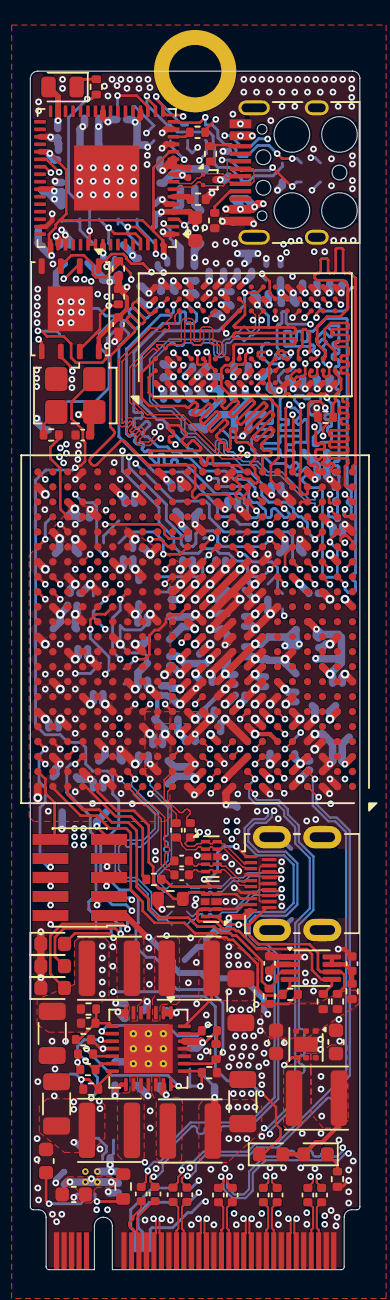
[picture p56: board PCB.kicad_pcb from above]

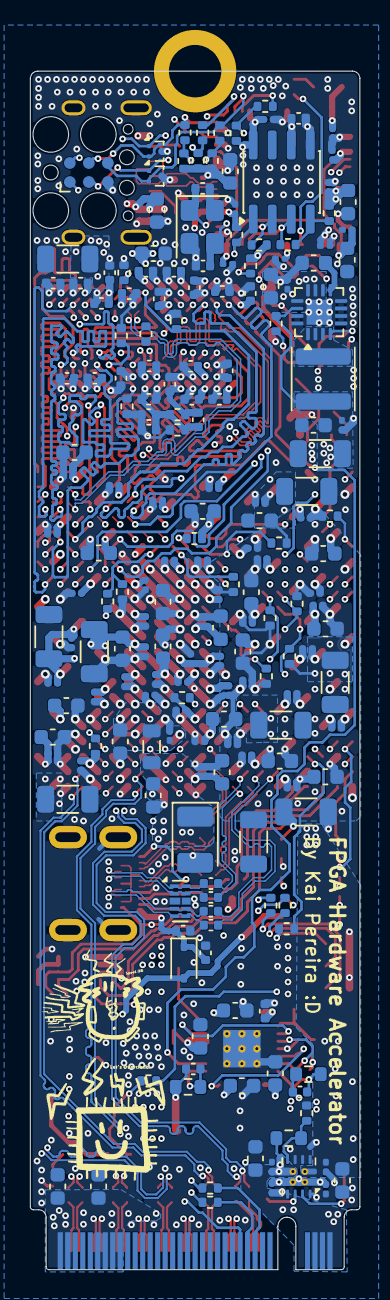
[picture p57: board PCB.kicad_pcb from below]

Board: 6 copper layers, 22.0 x 80.0 mm, 277 parts (196 on the bottom side), 193 nets.

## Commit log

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2025-12-24 updated the symbol again, added basic inductor/divider/decoupling to quad buck
    [power.kicad_sch]
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2025-12-27 working on buck, changing values to proper standard, ie 4.7 -> 4u7
    [FPGA-power.kicad_sch, power.kicad_sch]
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2025-12-27 cleaning stuff up, fixing power sequencing and decoupling
    [FPGA-power.kicad_sch, power.kicad_sch]
2025-12-29 changing the FPGA symbol for simpler decoupling schematic
    [FPGA-power.kicad_sch, PCB.kicad_sch]
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2025-12-30 fixing configurations
    [banks.kicad_sch, configurations.kicad_sch]
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2026-01-02 working on wiring the FT2232H, also modified some values to follow more standard conventions
    [configurations.kicad_sch, power.kicad_sch]
2026-01-02 cleaned up the schematic, wired some config pins
    [configurations.kicad_sch]
2026-01-03 fixed JTAGG, working on power architecture
    [configurations.kicad_sch, m.2-m-key.kicad_sch]
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2026-01-05 absolutely cooked on this power mux circuit, finished it!
    [power.kicad_sch]
2026-01-05 cleaning up the schematic a bit after this grind
    [FPGA-power.kicad_sch, m.2-m-key.kicad_sch, power.kicad_sch]
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2026-01-06 fixing JJTAG configuration
    [configurations.kicad_sch]
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2026-01-08 found the DDR3 memory I'm going to use
    [PCB.kicad_sch]
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2026-01-09 more bus shenanigans, fixing some pins
    [ddr3l.kicad_sch]
2026-01-09 adding bus labels and hierarchial labels to root
    [PCB.kicad_sch, ddr3l.kicad_sch]
2026-01-09 fixing up the DDR bus definitions
    [ddr3l.kicad_sch]
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2026-01-10 some footprints added in, starting to work on flash
    [FPGA-power.kicad_sch, PCB.kicad_pcb, PCB.kicad_sch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]
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2026-01-10 wiring some configuration pins, cleaning up the schematic
    [banks.kicad_sch, configurations.kicad_sch]
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2026-01-10 changing some of the decoupling and changing ferrite beads to 120R, will simulate later
    [FPGA-power.kicad_sch]
2026-01-11 an LED + changing the decoupling on the m.2 edge connector
    [configurations.kicad_sch, m.2-m-key.kicad_sch]
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2026-01-11 fixed my m.2 edge connector!
    [m.2-m-key.kicad_sch]
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2026-01-11 changing ac couping value to 220n for backward compatibility
    [m.2-m-key.kicad_sch]
2026-01-11 wiring the m.2 connector to the MGT transceivers
    [PCB.kicad_sch, PCIe GTP Transceivers.kicad_sch, m.2-m-key.kicad_sch]
2026-01-11 added some configuration features and cleaned it up
    [PCIe GTP Transceivers.kicad_sch, configurations.kicad_sch, ddr3l.kicad_sch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]
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2026-01-12 cleaning up my DDR3 symbols, journaling about some DDR3
    [configurations.kicad_sch, ddr3l.kicad_sch]
2026-01-12 cleaning up DDR3 even more, finishing it's journaling
    [PCB.kicad_sch, ddr3.kicad_sch]
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2026-01-13 cleaninng up the board, fixing some pullups, PCIe command pins
    [PCB.kicad_sch, banks.kicad_sch, configurations.kicad_sch]
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2026-01-13 cleaning up the schematic some more, getting ready to wire the clocks, HDMI and ethernet!
    [PCB.kicad_sch, banks.kicad_sch, ethernet.kicad_sch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]
2026-01-13 cleaning up the schematic even more, it looks sick now
    [PCB.kicad_sch, banks.kicad_sch, ddr3.kicad_sch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]
2026-01-13 cleaning up the schematic even more, starting on HDMI
    [PCIe GTP Transceivers.kicad_sch, ethernet.kicad_sch, hdmi.kicad_sch]
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2026-01-14 added th e level shifter for HDMI DCC
    [hdmi.kicad_sch]
2026-01-14 added all the HDMI parts in, done now!
    [hdmi.kicad_sch]
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2026-01-15 kind of finished wiring ethernet, cleaning stuff up
    [PCB.kicad_sch, banks.kicad_sch, ethernet.kicad_sch]
2026-01-16 adding some termination resistors and DNP's to EPHY
    [ethernet.kicad_sch]
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2026-01-16 finished HDMI ESD protection, took longer than I would have liked
    [hdmi.kicad_sch]
2026-01-16 cleaned up the schematic after that mess, looking beautiful :D
    [hdmi.kicad_sch]
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2026-01-16 completely finished the clock, cleaned up the schematic
    [PCB.kicad_sch, banks.kicad_sch]
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2026-01-17 cleaned up the schematic, I think it just needs a couple of reviews now!
    [usb.kicad_sch]
2026-01-17 cleaning up the schematic some more before sharing
    [configurations.kicad_sch, ethernet.kicad_sch, hdmi.kicad_sch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]
2026-01-17 cleaning some stuff up, PDF of the schematic added in!
    [ddr3.kicad_sch]
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2026-03-08 a bunch more layout stuff! Getting really compact!
    [PCB.kicad_pcb, banks.kicad_sch, configurations.kicad_sch]
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2026-03-08 all the FPGA decoupling layout and routing :D
    [PCB.kicad_pcb]
2026-03-08 laying out a bunch more stuff on the board!
    [PCB.kicad_pcb]
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2026-03-12 removing the TC2030, doesn't make sense :/
    [PCB.kicad_pcb, usb.kicad_sch]
2026-03-12 nevermind, tc2030 is a good idea for a fallback breakout
    [PCB.kicad_pcb, usb.kicad_sch]
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2026-03-16 fixing up my buck converter, getting ready for power routing
    [PCB.kicad_pcb, power.kicad_sch]
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2026-03-17 finished fills and a bit of routing for the buck
    [PCB.kicad_pcb, power.kicad_sch]
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2026-03-26 some USB to JTAG routing and other stuff
    [PCB.kicad_pcb]
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2026-03-27 more routing, cleaning up silkscreen and some other stuff
    [FPGA-power.kicad_sch, PCB.kicad_pcb]
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2026-03-29 cleaning up the QSPI and JTAG traces a LOT
    [PCB.kicad_pcb]
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2026-03-30 fixing a bunch of DRC unconnected items
    [PCB.kicad_pcb]
2026-03-31 reworking the M.2 3V3 fill
    [PCB.kicad_pcb]
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2026-04-01 fixing some DRC errors
    [PCB.kicad_pcb]
2026-04-01 PCIe tuning up, fixing some inner layer traces, down to 4 unrouted!
    [PCB.kicad_pcb, banks.kicad_sch]
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2026-04-02 0 unrouted, now I just gotta do HDMI and UART!
    [PCB.kicad_pcb]
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2026-04-04 fixing some unconnected items, working on HDMI
    [PCB.kicad_pcb]
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2026-04-06 finished routing HDMI and moved around a bunch of stuff!
    [PCB.kicad_pcb, banks.kicad_sch]
2026-04-06 cleaning some stuff up, doing some intra pair matching, and a bit more
    [PCB.kicad_pcb]
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2026-04-07 a lot of power stitching and lowering inductance of a bunch of stuff
    [PCB.kicad_pcb]
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2026-04-07 some chill ground stitching, lots of DRC errors though :((
    [PCB.kicad_pcb]
2026-04-07 more signal stitching and refining, time to go through DRC!
    [PCB.kicad_pcb]
2026-04-08 lower inductance fills, working through DRC errors, modified my M.2 footprint a bunch! 143 DRC errors ;)
    [PCB.kicad_pcb]
2026-04-08 refining and fixing more DRC errors
    [PCB.kicad_pcb]
2026-04-08 working on DRC errors!
    [PCB.kicad_pcb, power.kicad_sch]
2026-04-09 fixing a bunch of kicad bugs by updating!
    [PCB.kicad_pcb]
2026-04-09 fixing thermal relief errors, down to 80 DRC errors now!
    [PCB.kicad_pcb]
2026-04-09 zero DRC errors, back to design verification, second passes, and I also need to do some silkscreen labels ;)
    [PCB.kicad_pcb]
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2026-04-09 whoops, didn't leave enough room for my headers lol, some more refining, let's get these finishing touches in and find some space
    [PCB.kicad_pcb]
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2026-04-19 lowering 3V3 fill inductance by moving the USB 3V3 fill
    [PCB.kicad_pcb]
2026-04-19 routed a bunch of GPIO's, tuning up the USB 3V3 fill
    [PCB.kicad_pcb, PCB.kicad_sch, banks.kicad_sch]
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2026-04-19 tuning stuff up, and fixing DRC!
    [PCB.kicad_pcb, banks.kicad_sch]
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2026-05-02 cleaning up my crosstalk even more and making sure everything is matched!
    [PCB.kicad_pcb]
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2026-05-03 0 DRC errorsgit add .
    [PCB.kicad_pcb]
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
